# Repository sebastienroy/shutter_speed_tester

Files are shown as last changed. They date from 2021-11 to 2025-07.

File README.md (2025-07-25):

# Shutter Speed Tester for Film Cameras

The shutter speed tester is a project which goal is to design and build a tool that allows to test the shutter speed accuracy of a film camera

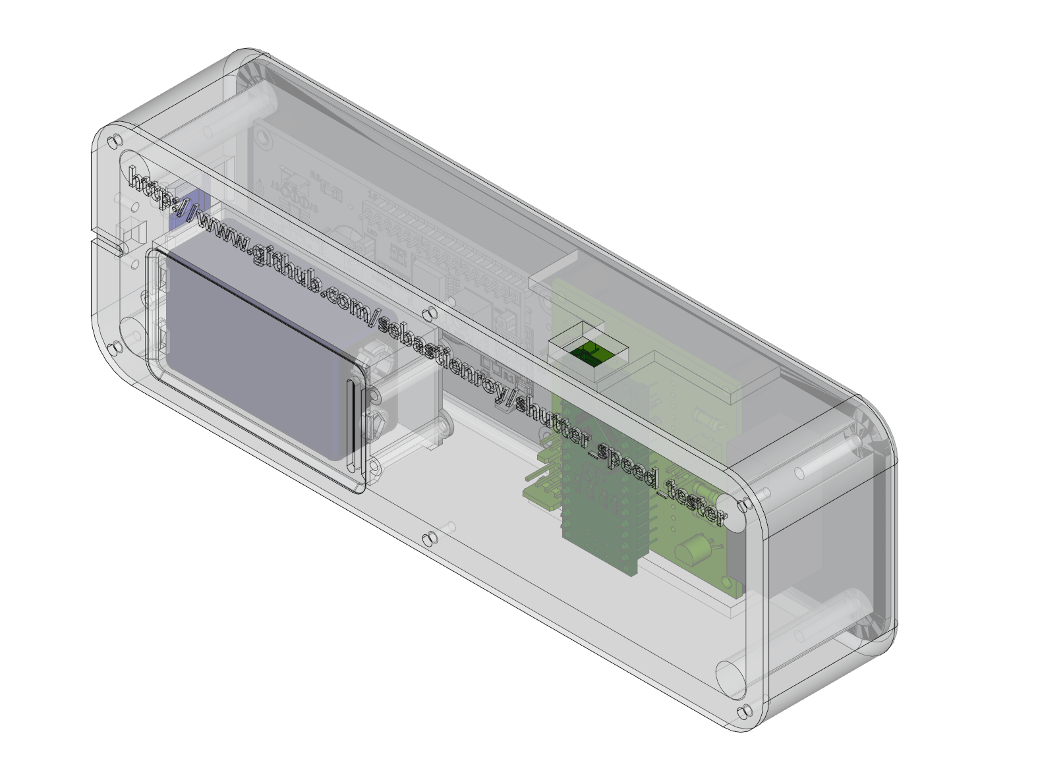
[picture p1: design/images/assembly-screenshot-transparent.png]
Shutter Speed Tester for Film Cameras in FreeCAD


When people passionated with old film cameras want to use their camera to shoot film, this sometimes results in an over or an under exposed film.  
This is usually due to the speed of the camera shutter that is not any more accurate. In order to check the shutter speed accuracy, the camera owner has to compare the actual opening time of the shutter with the expected one.  
This is the purpose of the shutter speed tester : measure the accuracy of shutter speed. 

Here is a presentation video (in French) :  

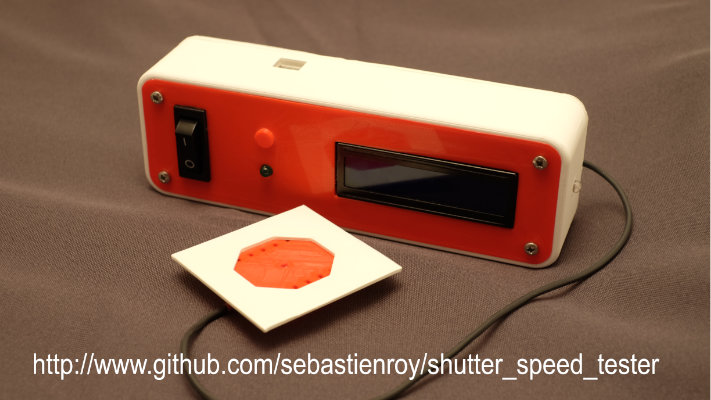
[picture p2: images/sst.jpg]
Presentation video in french (https://youtu.be/lsWC2Jt2cCw)


The result of this open source project is to allow anyone who has the minimum skills in DIY domain to build his own device

[Here is the description of the open source project.](project_description.md)

## Accuracy of the open source tester

The resulting tester has been tested against two methods described in [shutter meta tester project](https://github.com/sebastienroy/shutter_meta_tester) : time slot method and rotating wheel method.  
With the time slot method (an LED lit during a given time duration), the difference between expected and measured value is about a few tens of microseconds. This error is due mainly to the latency of the phototransistor. This error is small enough to not to be taken into account even at speed up to 1/2000s.  
With the rotating wheel method, we can observe an error a lot bigger. This error is not due to electronic factors, but results from geometric facts:  
The sensor of the tester is a bulb of 3mm diameter.  
At 1/1000s, given that the curtains translation speed is about 3m/s, the slit width of the curtain shutters is about 3mm large.  
When trying to measure a 3mm object with a 3mm sensor, the resulting error is about 100%.  
**So, because of geometric consideration, the use of such a tester should be reserved for speeds not exceeding 1/250.  
The conclusion is the same for all testers with a similar sensor that do not provide a calibration mechanism.**  

# Baby Shutter Tester mark II
Many people, interested to get such a device but who don't feel skilled enough to build their own copy, asked the author of the project to build it for them.  
This resulted to the commercial version of the tool, the Baby Shutter Tester (mark I).  
The Baby Shutter Tester was regularly improved, and its main additional feature was the ability to self calibrate.  **The self-calibration mechanism allowed a precision of a few microseconds, instead of 1 stop at high speeds.**  
However, the precision brought by the self-calibration procedure required to follow a very specific process, difficult to implement outside a workshop.  

So, a completely reworked version has been designed: the **Baby Shutter Tester Mark II.**  
The speed measurement method impleted by this new version is completely different: instead of starting a timer at a given light illumination threshold, the tester takes into account all the light variations that hits its sensor.  
This allows to take into account high speed ranges, where the shutter cannot be considered as a perfect shutter, i.e. the cases where the shutter cannot be aproximated to an on/off mechanism.  
This method is similar to the method used by the Kyoritsu legacy professional shutter tester.  
In addition, the Baby Shutter Tester Marks II meets all the recommendations of the ISO-516:2019 standard. Not only the testing method but also all the measurement precision requirement described by the standard.  

The benefits of this characteristics are the following:
- An extreme accuracy
- The accuracy is obtained without calibration procedure
- Using the optional light source with diffuser, the tester can also measure central (leaf) shutters without any bias.

More information on https://photographyelectronics.com  

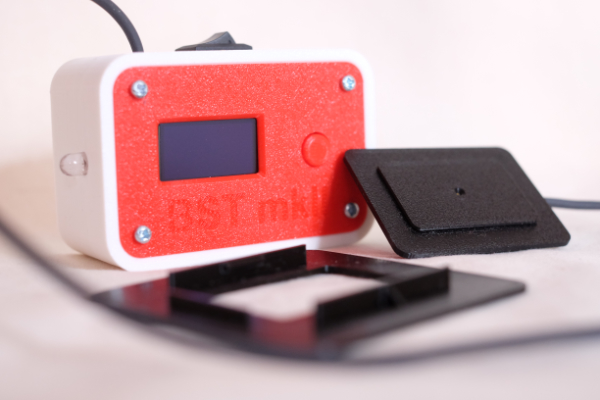
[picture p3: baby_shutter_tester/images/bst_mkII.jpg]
Baby Shutter Tester image


## Video presentation
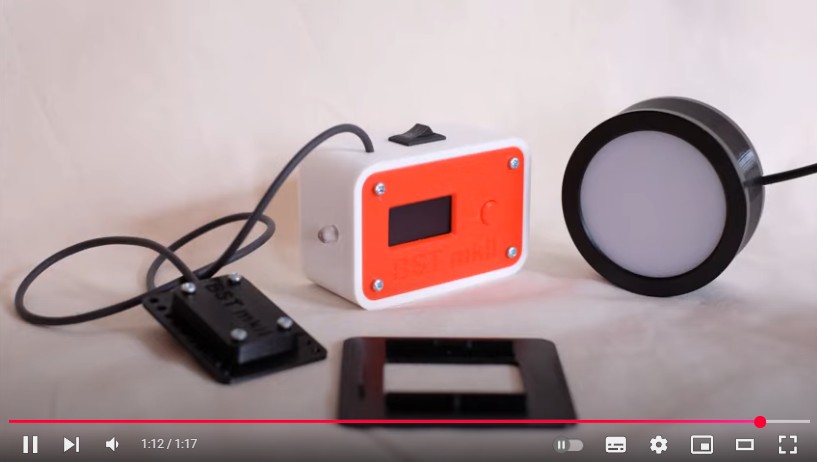
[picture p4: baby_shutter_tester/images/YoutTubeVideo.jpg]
Presentation YouTube (https://youtu.be/JVzSVh_tT6g)
  

## Accuracy test methods
The accuracy of the Baby Shutter Tester mark II is checked using 
- the graphical verification method described in the ISO-516:2019 standard
- [a dedicated benchmark](https://github.com/sebastienroy/shutter_meta_tester).
 
## Where to buy 
https://photographyelectronics.com/shop/  
[eBay link](https://www.ebay.fr/itm/205397044799)

## User manual

[User Manual](https://github.com/sebastienroy/shutter_speed_tester/wiki/Shutter-Testers-documentation)

# Curtain travel time measurement: The Shutter Lover

The Shutter Lover is a tool specialized in the measurement of the travel time of the curtains of focal plane shutters.  
The measurement of the curtain travel time is necessary for camera repairers, in order to be able to ajust the springs of each of the curtains.  
The goal is to obtain an homogeneous travel time of the two curtains, with values in accordance with the manufacturer recommendations.  

Shop: https://photographyelectronics.com/shop/  
This product is also available for [purchase on ebay](https://www.ebay.fr/itm/204344103169).  

Here is a short teaser :  
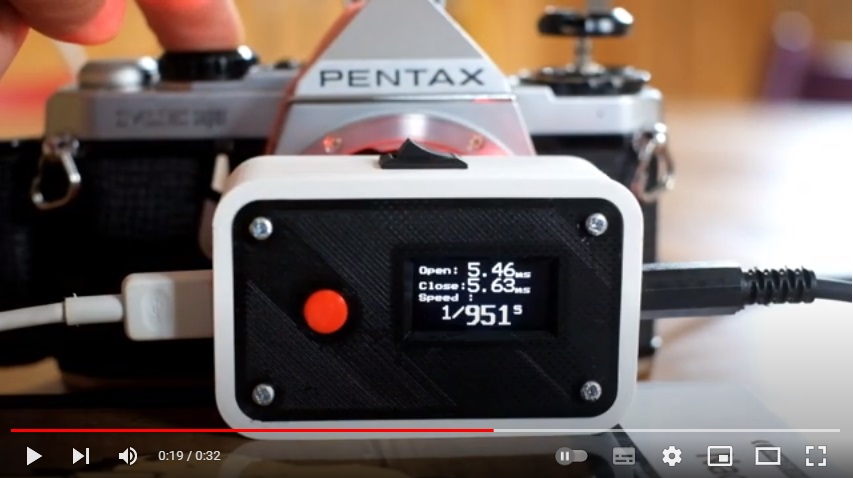
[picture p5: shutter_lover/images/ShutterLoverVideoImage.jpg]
Video of the Shutter Lover (https://youtu.be/AOC1KYjHUho)


## User Manual  

[User Manual](https://github.com/sebastienroy/shutter_speed_tester/wiki/Shutter-Testers-documentation)

## Test bench

In order to get the better precision and reproducibility with the shutter Lover, it is recommended to use a test bench, such as the one describe [here](testbench/testbench.md).

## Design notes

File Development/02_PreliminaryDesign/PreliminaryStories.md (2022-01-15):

# Preliminary design

## System and Architecture analysis

The system is very small and is not interfaced with other systems, except
- The user
- The camera

Thus we will not write a complete system analysis of this. We will jump directly to the physical architecture design of our tool :

Physical Architecture

## Components choice

|Component role | Component choice | Comment |
|---|---|---|
| Main unit | Compound | The main unit is composed of several other components.</br> A specific casing has to be be designed for it |
| Control unit (hardware) | Arduino Nano | An arduino nano microcontroler would fullfill all the needs : </br>- low price</br>- low dimensions</br>- low electric cosumption</br> - capacity to interact with simple electronic components |
| **Control unit (software)**| **Specific code** | This will be one of the subjects of this project. It has to make the link between the differents componetns of the tool |
| **Mother board** | **Specific design** | A specific PCB has to be designed to integrate all the different components of the tool. Once designed, it can be manufactured by any PCB manufacturer |
| Electrical power | Battery | The detailed design of the battery part has to be defined later. </br>The use of battery allow a more practical usage of the tool. </br>The low consumption of the arduino allow to use it without a to high battery consuption.</br>However, the USB port of the Arduino may be used as a opportunity to power the system without using a battery |
| Power switch | Flip flop switch | A "hard" power switch will be preferred rather than a "standby" push button, in order to not use the battery at all when not in use |
| Reset button | Push button | The Reset button will be able to erase the previous result and start a new measure |
| Control led| Led | the control led will help the operator to see that the light sensor is currently detecting light (when the shutter is open, if the light source and the light sensor are correctly positionned). This could be achieved also using a specific display on the general display device. However, due to the low response speed of the chosen display (see below), a LED is prefered|
|Display| 16x02 LCD| A 16x02 LCD is very common, low price and easy to control with an Arduino|
|Light source| Led| The light source has to be chosen in accordance with the light sensor sensitivity (intensity and even maybe wavelength).</br>It has to be mounted preferably on a physical support that allows to adjust the position according the tested camera.</br>There is two options for the light source : </br>  1. Use an independent light source, maybe even don't include it in the package and let the user choose it by himself</br>  2. Use a light source powered by the tool</br>The option 2 is prefered because it allow to have a real control on the quality of the light source. Indeed much of commercial led lamps are quickly blinking (PWM source) when used in eco mode and cannot be used for our purpose.</br>The challenge is to have a light source that <br/>  - is bright enough to allow the light sensor to detect the opening of the shutter</br>  - does not use too much electrical power and does not drain the battery too fast|
| Light Sensor | Phototransistor | A phototransistor is a good compromise between a low price, a good sensitivity and a low reaction time.</br> A specific support has to be designed, maybe according different film formats, in order allow a good position on the camera back, in order to easily detect the source light and not be influenced by environment light</br>Alternatives would have been :</br>- Photoresistor, too slow</br>- Photodiode, even faster than phototransistor but not enough sensitive |
| **Casing** | **Specific design** | A specific casing has to be designed in order to host all the components. There is many differnet ways to design a case. </br>- One of them is to model it with a 3D design tool and then to print it using a 3D printer</br>- Another solution is to make it using wood, using the same dimensional specifications as those defined for the 3D printed one</br>- It is also possible to mix the solutions |

## Design & development tools

The design & development tools are the following
| Tool name | Version  | Purpose | link |
| --- | -- | --- | --- |
| Fritzing | 0.9.3 | Electronic component & circuit design | https://fritzing.org/ |
| KiCad | 5.1.12 | Electronic component & circuit design| https://www.kicad.org/ |
| FreeCad | 0.19.2 | 3D modeling | https://www.freecadweb.org/ |
| Arduino IDE | 1.8.16 |Arduino cross development IDE | https://www.arduino.cc/en/software |
| VSCode | 1.62.0 | General purpose code editor | https://code.visualstudio.com/ |
| Drawio integration | 1.6.201 | Integration of Drawio tool into VSCode IDE |

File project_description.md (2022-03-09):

# Shutter Speed Tester Project Description

## Principle

Shutter speed tester principle schema

## Project scope

The project scope is to describe how to design and build a shutter speed tester tool.
The outputs of the project are :
- design documents, including the design process itself
- build description

## The project, step by step

Note that the following steps are not strictly waterfall. The result of a given step may introduce rework on previous steps

### [Operational concept definition](Development/01_OperationalConcepts/OperationalStories.md)
- Who is the target audience ?
- What need will be statisfied by the project product ? (Conops)
- How the product will satisfied by the need ? (Conuse)
- What are the product expected advantages compared to existing products ?

### [Preliminary design](Development/02_PreliminaryDesign/PreliminaryStories.md)
- Main behavioural description
- Definition of product architecture
- Choice of components / providers
- Choice of development/production tools

### [Development of Electronic circuit / microcontroler code / PCB design](Development/03_Development/DevelopmentStories.md)
- Definition of the target circuit with elements needed to implement the expected behaviour
- Development of the code necessary to control the electronic circuit and to implement the expected behaviour
- Design of the target PCB
- Production of PCB
- Assembly of components : soldering, connectors assembly, tests

### [Design of the casing](Development/04_Casing/CasingStories.md)
- Design of the facade : holes for display, button, LED, switch, position and size of screw plots
- Design of the body : positionning of the light source, sensor wire
- Design of the back : battery case and door
- Design of the sensor case : take into account different films and camera formats

### [Documentation](Development/05_Documentation/DocumentationStories.md)
- User Manual
- Build Manual
- BOM (Bill of Material)

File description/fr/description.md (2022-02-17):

# Description du projet Shutter Speed Tester (Testeur de vitesse d'obturateur)

## Introduction

Le projet consiste à réaliser un outil permettant de mesurer la vitesse d'obturation des appareils photographiques argentiques.  
Ces appareils photo, surtout lorsqu'il sont anciens, ont un obturateur qui est une pièce d'horlogerie susceptible de se dérègler. Le temps d'ouverture de l'obturateur peut alors avoir un écart important par rapport à la valeur attendue, conduisant à une sous-exposition ou une sur-exposition de la pellicule.  
La connaissance de cet écart permet au propriétaire de l'appareil photo, 
- soit de re-calibrer l'obturateur s'il en a les compétences, 
- soit de compenser l'écart constaté au moyen du règlage du diaphragme et/ou du sélecteur de vitesse.

## Niveaux de compétences requis pour ce projet

| Domaine | Niveau | Détail |
|--|--|--|
| Connaissance métier | Niveau intermédiaire| Comme dans tout projet, une bonne connaissance des besoins de l'utilisateur final est la clé de la réussite. Lorsque le client et le fournisseur ne font qu'un, forcément ça aide. Les concepts opérationnels servis par le projet sont toutefois plutôt simples à apréhender|
| Electronique | Peu complexe à moyennement complexe | - Définition des circuits : Niveau lycée. La loi d'Ohm et le principe de fonctionnement d'une LED et d'un transistor sont suffisants pour les circuits de ce projet</br>- Réalisation d'un circuit imprimé : L'expérience montre que la définition d'un circuit imprimé tel que celui de ce projet n'est au final  pas très compliquée. Sa fabrication est sous-traitée à un industriel spécialisé</br>- Assemblage des composants : L'assemblage des composants sur le circuit imprimé nécessite de réaliser quelques soudures et de sertir quelques connecteurs. Ce sont des savoir-faire qui s'apprennent très facilement après visualisation de quelques vidéos YouTube. |
| Programmation Arduino| Peu complexe à moyen | Niveau bac. Les circuits électroniques sont pilotés par le microcontroleur d'une carte Arduino. La programmation d'une telle carte est de niveau lycée. La gestion des interruptions et d'états est à peine plus complexe mais ne devrait pas présenter de difficulté particulière pour un ingénieur travaillant dans des systèmes à logiciel prépondérant |
| Modélisation 3D | Peu complexe | Définition du modèle 3D du boitier. De nombreux éléments sont à prendre en compte (taille et position des composants, trapes d'accès, etc), mais individuellement, aucun de ces éléments ne représente une difficulté majeure|
| Suite dans les idées| Niveau ingénieur d'un grand groupe industriel | Chacune des étapes du projet est individuellement très simple, et nécessite des connaissances facilement accessibles en ligne. Il a toutefois été nécessaire d'en enchainer un nombre important pour arriver au résultat attendu. L'identification et la description de ces étapes est au final l'enjeu principal d'un projet de ce type. Ce sont des activités qui sont le quotidien du Product Owner dans une organisation Scrum| 

## Outils et techniques appris ou mis en oeuvre au cours du projet
|Outil/technique|Description|
|---|---|
| Arduino IDE | Le web regorge de ressources, tutoriels, documentation, vidéos décrivant chaque aspect de la programmation Arduino. Il suffit de se pencher pour ramasser |
| Fritzing| Fritzing est un outil permettant de décrire très facilement des schémas électroniques, et notamment sous forme de plaque d'essais. Impeccable pour générer des illustrations|
| KiCAD | KiCAD est un outil Open Source de design de circuits imprimés. Il permet de décrire très précisément, avec une qualité "professionnelle", les différentes couches qui composent un circuit imprimé. Son format de fichier est directement accepté par les fabricants de circuits. KiCAD est très riche, mais seul une partie de cette richesse a été exploitée pour ce projet |
| Fer à souder | L'utilisation d'un fer à souder pour souder des composants n'est pas très compliquée mais nécessite un peu d'expérience avant d'arriver à un résultat satisfaisant. De nombreux tutoriaux et descriptifs sont disponibles en ligne |
| Pince à sertir| Pour relier les composants "externes" au circuit imprimé, on utilise des fils électriques connectés par le moyen de connecteurs. Ils nécessitent d'être sertis. On utilise pour ce faire une pince à sertir, qui demande un peu d'aprentissage pour limiter le taux de déchets|
| FreeCAD | FreeCAD est un des nombreux outils disponibles pour la modélisation 3D. Il a l'avantage d'avoir un fonctionnement paramétrique, permettant une définition ultra précise des dimensions des pièces concues. Par ailleurs de très nombreux tutoriaux et exemples sont diponibles en ligne. Une fois assimilés les principes généraux de l'outil, son utilisation est plutôt simple |
| Impression 3D| L'impression 3D proprement dite est très simple. Elle met en oeuvre un outil qui va importer le modèle 3D et le découper en tranches, les différentes couches d'impression.  |

## Les étapes du projet, pas à pas
Voici les grandes lignes du développement du projet. Les détails de chacune des parties est disponible (en anglais) sur le site de partage du projet  
> www.github.com/sebastienroy/shutter_speed_tester

### Définition du concept opérationnel
- Qui est la cible du produit ? 
- Quels besoins seront satisfaits par le produit ? (Conops)
- Comment le produit va satisfaire le besoin de l'utilisateur? (Conuse)
- Quels sont les avantages comparatifs du produit par rapport à ce qui existe déjà? 

### Design préliminaire
- Description des comportements principaux
- Définition de l'architecture du produit
- Choix des composants
- Choix des outils de développement

### Développement électronique et logiciel
- Définition du circuit comprenant les éléments requis pour implémenter le comportement attendu
- Développement du code de control des circuits électroniques et implémentant le comportement attendu
- Développement du circuit imprimé
- Production du circuit imprimé
- Assemblage des composants : soudure, sertissage des connecteurs, tests

## Design du boitier

- Design de la façade : ouvertures pour l'affichage, le bouton, la LED de control, l'interrupteur. Positionnement des plots de support à vis.
- Design du corps du boitier : positionnement de la source de lumière, du fil du capteur
- Design du dos : emplacement de la pile et de sa trappe d'accès
- Design du support de capteur : prise en compte des différents formats de film photographique.

### Documentation
- Manuel utilisateur
- Manuel de fabrication
- Liste des composants

## Les conseils de Sébastien
Ce type de projet est l'occasion idéale pour un ingénieur de couvrir l'ensemble des phases de réalisation d'un projet, des concepts opérationnels jusqu'à la mise en production. Ceci n'arrive pas souvent dans la vie professionnelle, vu les cycles parfois très longs et la taille des équipes sur lesquels nous sommes impliqués.  
Il pourrait être tentant, vu la taille typique d'un projet personnel et l'absence de contrainte externe, de ne pas formaliser les phases amont, ni même la description des phases de développement successives.  
Ce serait une erreur, car cette formalisation permet de se donner un fil conducteur. C'est une source de satisfaction à chaque étape réalisée. Comme le temps disponible pour le projet est très fragmenté, formaliser chaque étape permet de reprendre les travaux très rapidement après une interruption.

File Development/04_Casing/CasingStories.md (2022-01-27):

# Summary

- [Summary](#summary)
- [Casing Stories](#casing-stories)
  - [1. Design of the case, front side](#1-design-of-the-case-front-side)
    - [Description](#description)
    - [Realisation](#realisation)
    - [Screw holes](#screw-holes)
    - [Result](#result)
  - [2. Light source housing](#2-light-source-housing)
    - [Description](#description-1)
    - [Realisation](#realisation-1)
  - [3. Battery door](#3-battery-door)
    - [Description](#description-2)
    - [Realisation](#realisation-2)
    - [Conclusion](#conclusion)
  - [4. Prevent the sensor wire to rip](#4-prevent-the-sensor-wire-to-rip)
    - [Description](#description-3)
    - [Realisation](#realisation-3)
  - [5. LightSensorSupport](#5-lightsensorsupport)
    - [Description](#description-4)
    - [Result](#result-1)
  - [6. Medium format Adapter](#6-medium-format-adapter)
    - [Description](#description-5)
    - [Result](#result-2)

# Casing Stories

## 1. Design of the case, front side

### Description
Because designing the case may be a very complex activity, we will split in 3 steps :
* The design of the front panel
* The design of the case sides
* The design of the rear panel

Of course, the integration of these 3 parts has to be addressed

### Realisation
We use an open source model for LCD1602 : https://grabcad.com/library/1602-lcd-display-1

The Front panel need to put in place the main board, the LCD board, and te power switch. the thickness will be set to 1.5mm.

### Screw holes
One of the tricky thing is to choose the good screw hole diameter. It must be bigger than the core part of the screw, and smaller than the exernal diameter of the screw.
I have ordered iron plate screws, because they are most common than screxs for plastic.
However, screws for platics could have been ordered here :
https://www.visseriefixations.fr/eco-syn-pour-thermoplastiques-tcb-pozi-2-2x5-z-blanc.html  
We will order more specific screws when we'll have used all the screws we have ordered, described in the part list.
- Small screws : M2.2 x 6.5 mm
  - Core diameter : 1.9 mm
  - External diameter : 2.2 mm
- bigger screws : M2.9 x 13 mm
  - Core diameter : 2.2 mm
  - External diameter : 2.8 mm

Conclusion : we will use
  - 2 mm diameter for small screw holes (screws for pcb)
  - 2.5 mm diameter for bigger screw holes (screws for panels)

### Result 

Here is the front view :  
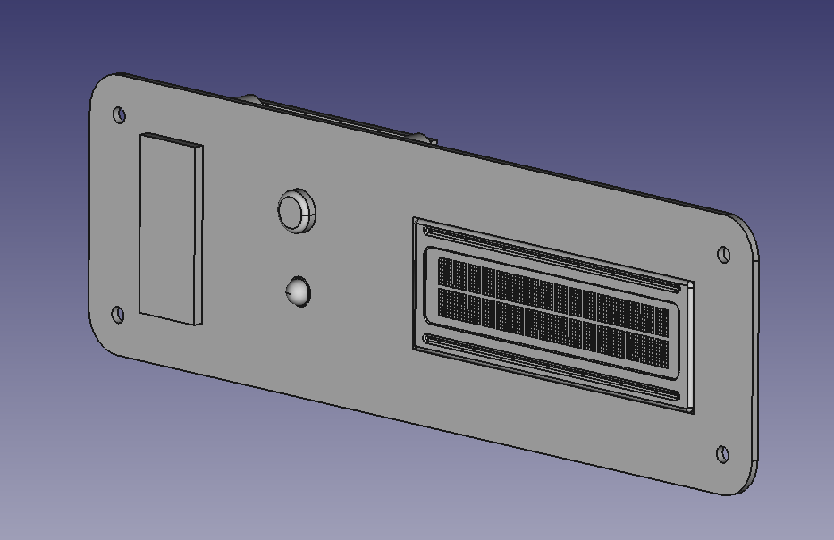
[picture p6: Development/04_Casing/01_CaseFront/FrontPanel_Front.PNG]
Casing front panel, Front view
  

And here is the back :  
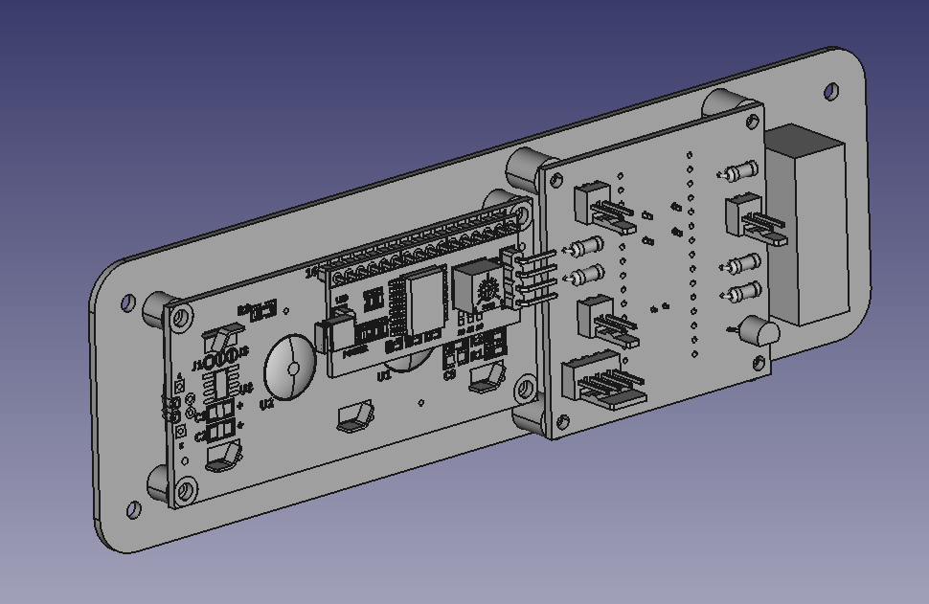
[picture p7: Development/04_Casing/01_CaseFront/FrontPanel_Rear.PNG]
Casing front panel, Rear view


## 2. Light source housing

### Description

The case must take into account the size of the different elements, but also the need to hold the light source.
Decision is taken to hold the light source in the side of the case. This will make more simple the general handling of the tool. It than just has to be placed in front of the camera, and the light sensor in the back.
The goal is now to make a design in order to hold the light source LED in the wall of the case.  
The dimensional specifications of the light source LED are the following :  
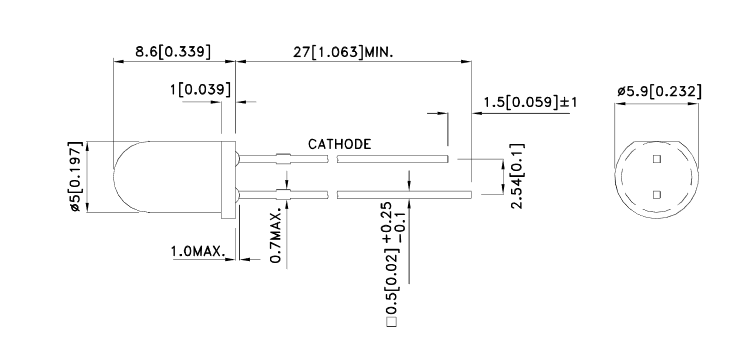
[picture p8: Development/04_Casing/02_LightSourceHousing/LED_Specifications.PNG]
LED specifications


### Realisation

We will test that :

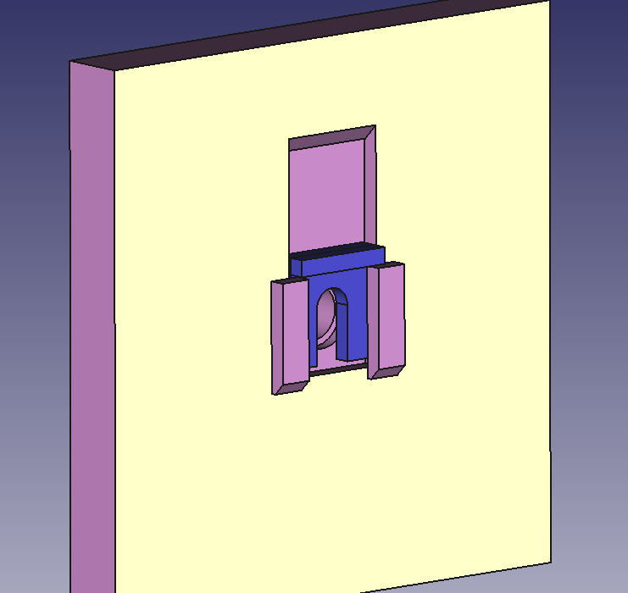
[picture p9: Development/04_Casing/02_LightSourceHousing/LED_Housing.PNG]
LED housing test


A first test shows that the concept is not bad. However, it needs a lot of sanding in order to be able to insert the LED into the hole. So, the tolerences have to be increased to make easier the insertion of the LED. Furthermore, chamfers have been added to the hold piece.

## 3. Battery door

### Description

The idea is to create a door that can be opened by hand but that cannot open by itself.  
In one word, we wan to design a battery door.
The prefered design would need no screw.  

### Realisation

We use a well known design, that use a door with a slot at one side, that allows to unlock it by bending the side.  

Here is the inside view :
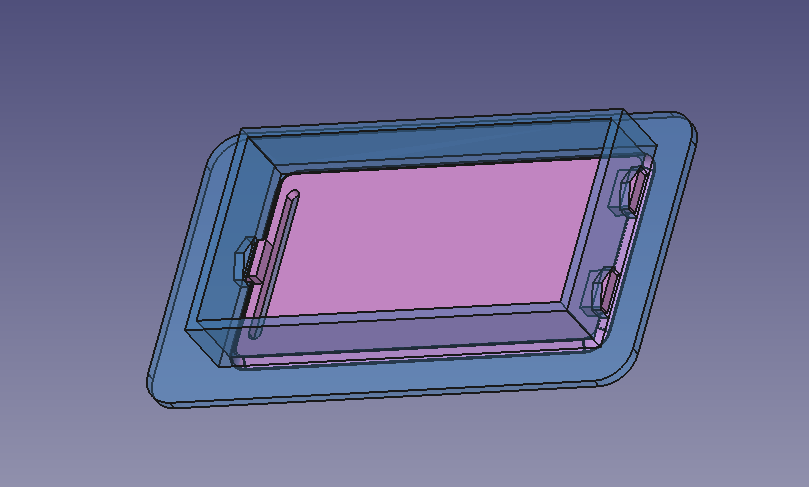
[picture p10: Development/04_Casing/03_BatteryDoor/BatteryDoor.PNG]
Battery door


There is chamfers in the opposite direction on the door panel and on the outside panel, so they fit perfectly together. 
Howver, du to the 3D printing flaws, some tolerances have to be applied :  
The door panel has to be smaller of :
- the panel opening is 60x30 mm
- the door is 62 x 32
- The thickness of both panels is 1.5 mm
- the chamfers of both panels is 1.3 mm

The theretical overlap of each side is :  
thickness - 2 (thickness - chamfer)  = 2 chamfer - thickness. 
In our case it is : 2x1.3 - 1.5 = 1.1 mm
So, a perfectly build construction would have fit with a door having 62.2 mm x 32.2 mm.  
We use a little bit smaller dimensions to take into account the 3D printing flaws.

### Conclusion
In order to fit perfectly, with a panel thickness of 1.5mm and a 1.3mm chamfer on both panel and door, the **door** must be **2mm longuer** and **2 mm larger** than the panel opening.

## 4. Prevent the sensor wire to rip

### Description
The light sensor will be placed at the back of the camera in a separate casing, and linked to the main body using a wire. The wire will be connected to the main board using a dedicated connector.  
The point to adress in this story is the way the wire passes through the casing. The problem to solve is to prevent to accidentaly rip the connecter by pulling on the wire. There is two ways to address this :  
- Using another connector to pass through the case panel
- blocking the wire, using for instance chicanes, inside the casing

### Realisation

- [ ] **TODO**

## 5. LightSensorSupport

### Description  
The vision of the design of the LightSensor support is to have a core support, designed for the 35mm film format.  
To this, may be added adaptors to 120 film format : 645, 6x6, 6x9

Specifications of 35mm film can be read there :  
[Kodak film specification](https://www.kodak.com/content/products-brochures/Film/How-to-read-a-Kodak-film-can-label.pdf)
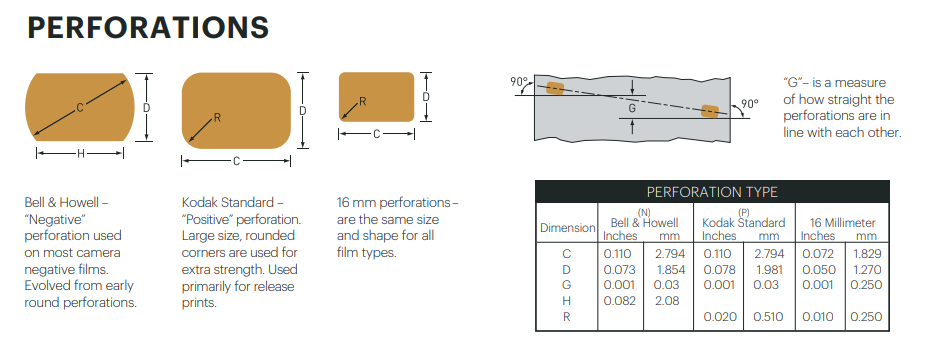
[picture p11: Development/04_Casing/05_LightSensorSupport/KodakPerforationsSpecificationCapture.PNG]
KS perforation specification


The 35mm film is 35mm large, 
Perforations pitch is 4.75mm.
Each perforation is about 2.8mm x 2.0mm large (KS perforation), at about 2 mm from the side of the film.  
Their corners are rounded, with 0.5mm radius.

Here are the physical specifications of the phototransistor :
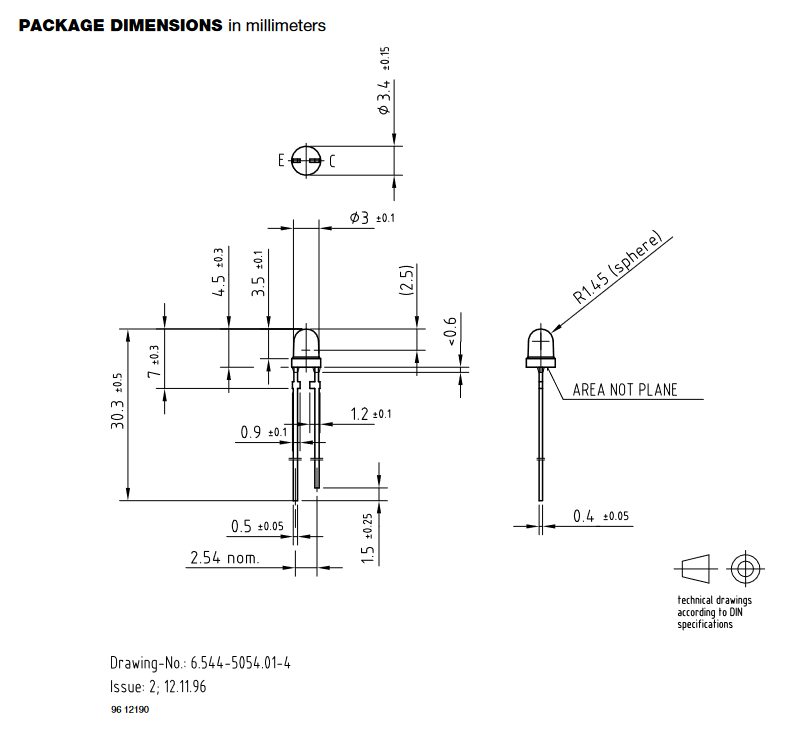
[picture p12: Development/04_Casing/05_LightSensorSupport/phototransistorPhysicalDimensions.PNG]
Phototransistor physical dimensions


A hole must be provided in the middle of the support to hold this phototransistor.

### Result
Here is the result :  
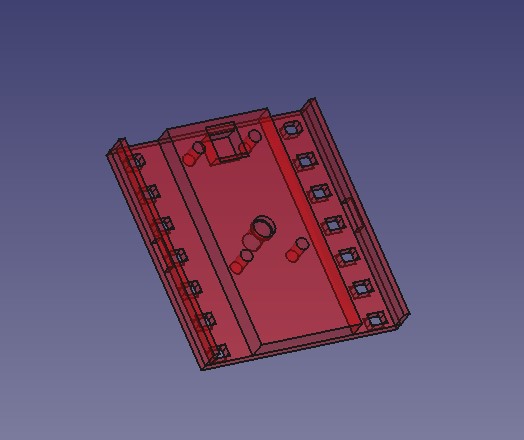
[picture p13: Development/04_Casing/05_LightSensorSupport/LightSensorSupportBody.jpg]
Light Sensor Support
  
Holes have been provisioned at the sides of the support to allow to fit an adapter for medium format film cameras.

And, with the lessons learned from step 4, we also add a cover that prevent the wire to move.

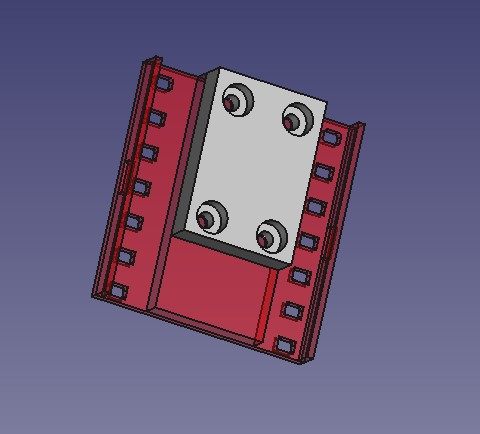
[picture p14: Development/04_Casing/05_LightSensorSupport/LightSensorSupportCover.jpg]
Light Sensor Cover


## 6. Medium format Adapter

### Description
We need an adapter in order to be able to use the sensor also with medium format cameras.  
Medium format films are rolls of approximatively 6 cm large. This format is named "120 format".  
The cameras that use 120 film may have different exposed sizes : 6x4.5, 6x6, 6x7, 6x9, ...
We will design a 6x6 adapter. Other format will be easily adapted from that.

### Result
And here is the result :
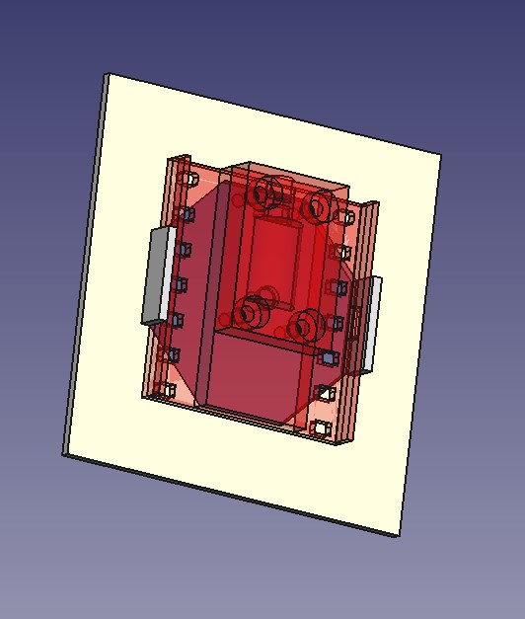
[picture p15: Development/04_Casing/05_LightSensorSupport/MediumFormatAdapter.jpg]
Medium Fomat Adapter
  
This is a very simple but efficient design.  
The adapter can be easily fit on or off by bending it.

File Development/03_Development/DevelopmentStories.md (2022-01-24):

# Summary

- [Summary](#summary)
- [Development Stories](#development-stories)
  - [1. Experimention : How to detect the opening of a camera shutter](#1-experimention--how-to-detect-the-opening-of-a-camera-shutter)
    - [Description](#description)
    - [Acceptance criteria](#acceptance-criteria)
    - [Realisation](#realisation)
    - [Results](#results)
  - [2. Detection of the time interval between rising and falling edges of the shutter](#2-detection-of-the-time-interval-between-rising-and-falling-edges-of-the-shutter)
    - [Description](#description-1)
    - [Test means](#test-means)
    - [acceptance criteria](#acceptance-criteria-1)
    - [Bibliography](#bibliography)
    - [Realisation](#realisation-1)
    - [Code](#code)
  - [3. Implementation of behaviour states](#3-implementation-of-behaviour-states)
    - [Description](#description-2)
    - [Realisation schema :](#realisation-schema-)
    - [Code](#code-1)
  - [4. Add control LED](#4-add-control-led)
    - [Description](#description-3)
    - [Realisation schema](#realisation-schema)
    - [Code](#code-2)
  - [5. Display on LCD screen](#5-display-on-lcd-screen)
    - [Description](#description-4)
    - [Code](#code-3)
  - [6. Bonus : create a sleeping mode](#6-bonus--create-a-sleeping-mode)
    - [Description](#description-5)
  - [7. Create the Printed Circuit Board (PCB)](#7-create-the-printed-circuit-board-pcb)
    - [Description](#description-6)
    - [Realisation](#realisation-2)
  - [8. Automatically update LCD IIC address](#8-automatically-update-lcd-iic-address)
    - [Description](#description-7)
    - [Realisation](#realisation-3)
  - [9. Setup mode](#9-setup-mode)
    - [Description](#description-8)
    - [Realisation](#realisation-4) 

# Development Stories

## 1. Experimention : How to detect the opening of a camera shutter

### Description

The aim of this story is to choose the right components and the right electronic schema in order to be able to detect the opening of a camera shutter, i.e how to detect a light source using a light sensor

### Acceptance criteria

The choice of the components and schema allow to detect a light source using a light sensor

### Realisation

With the following schema, it would be possible to check different values of resistor, and measure
* The voltage value induced by the phototransistor current, depending on the light that illuminated it
* Which light intensity, for different resistor value, allow to swich the digital port of the Arduino

As a ligth source, we will use a standard led component, directly wired on the 5V output of the Arduino.  A 220 Ohm resistor is used to get an intensity less than 20 mA.  
20 mA is the maximum current value recommended both for Arduino output (even not used in this experimentation) and for a standard LED.  
$$
I = U/R = \frac{(5.0 - 1.2)}{220} \approxeq 17 mA
$$  

I = U/R = (5.0V - 1.2V) / (220 Ohm) ~= 17 mA  
(The direct voltage of the Led is 1.2V)  

And here is the schema :
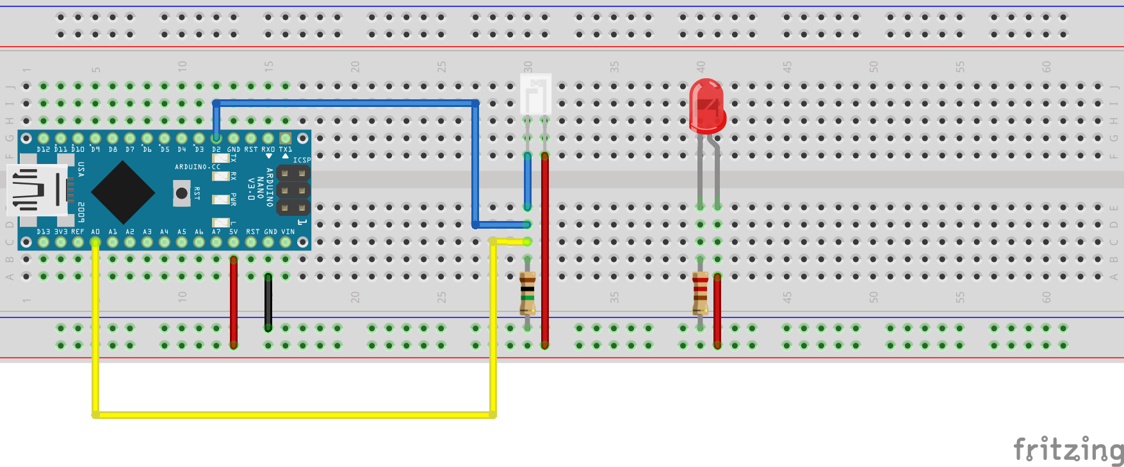
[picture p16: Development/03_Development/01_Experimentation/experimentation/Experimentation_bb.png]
Experimentation schema


Be carefull to plug the anode pin (the longer leg) of the phototransistor and the LED to the + side of the circuit

The following code will allow to get written on the serial of the Arduino, every second, the current analog and digital values read on the phototransistor :

[Experimentation code](01_Experimentation/experimentation/experimentation.ino)

### Results

The higher is the resistor value between the phototransistor, the more sensitive is the result.
- With a 1k Ohm resistor, the measured voltage change a little when putting the phototransistor in front of the led  
- The sensibility increases with increasing value of resistor
- When using 1M Ohm resistor, it is possible to change the input state at a ~ 5 cm distance
- When using 4x1M Ohm resistors (serial circuit), it is even possible to change the state at 10 cm

Questions :
- What is the limit of increasing sensibility ?
- Is there a side effect of increasing the resistor, as for instance a slower reactivity ?
- Is it better to use a more powerfull LED or higher resistor value ?

## 2. Detection of the time interval between rising and falling edges of the shutter

### Description 

The goal of this step is to do the minimum of design and development to be able to compute the time interval between rising and falling edges of the shutter.  
This step can be considered as a kind of derisking.

### Test means

The source of light may be provided by an external device 
The result output may be written (and read) on the serial port of the Arduino

### acceptance criteria
The system detects the rising and falling edges of the shutter
The system computes the time differences between rising and falling edges

### Bibliography

A similar problem has been adressed in this page :
https://lederniermatou.net/arduino-et-phototransistor.html

### Realisation

The following circuit has been realized, based on the experimentation :  

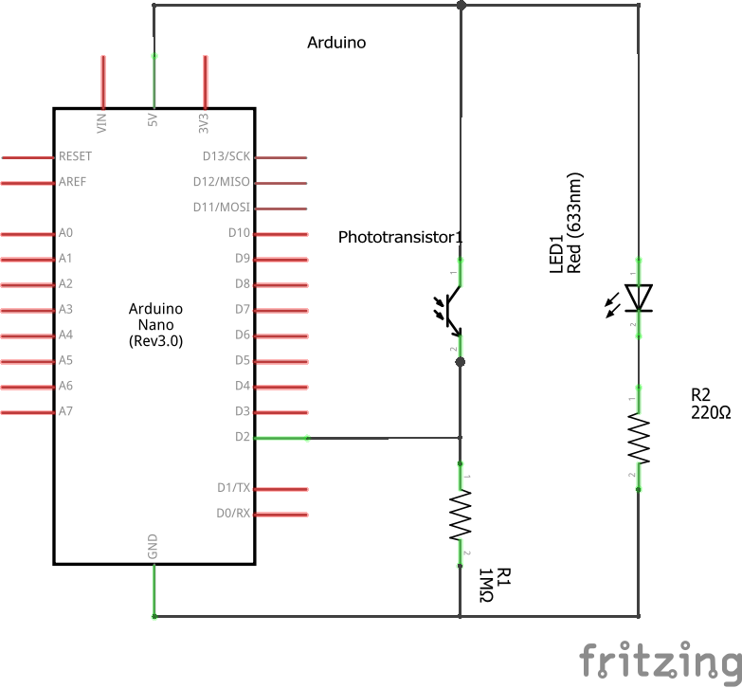
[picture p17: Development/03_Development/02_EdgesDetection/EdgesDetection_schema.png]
Schema
  

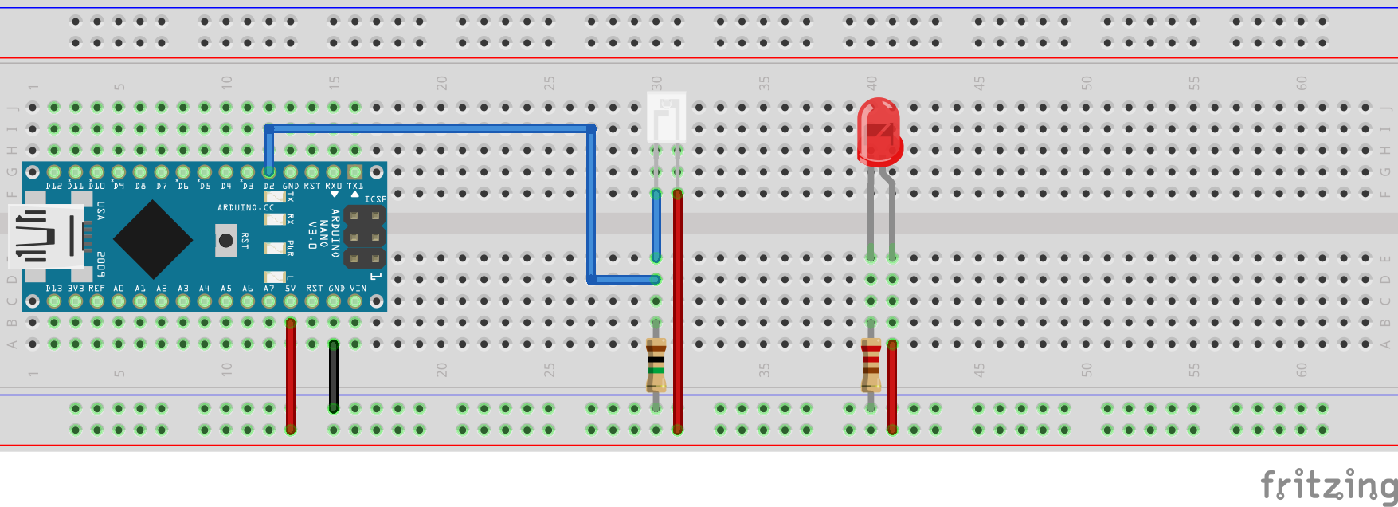
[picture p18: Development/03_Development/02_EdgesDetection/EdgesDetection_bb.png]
Bread board


Note that, in order to use the interrupt capacity of the Arduino, only the D2 or D3 pins may be used for the phototransistor state change. The interrupt capacity is not available on the other pins.  

### Code

[Edges detection code](02_EdgesDetection/EdgesDetection/EdgesDetection.ino)

## 3. Implementation of behaviour states

### Description

The goal of this step is to implement the complete state diagram of the expected behaviour of the tool.  
The idea is to light on the source LED only when the user is ready to start the measure, and to switch it off as soon as the measure is performed.  
A button allows to start a new measure.

State diagram :

Behaviour state diagram

### Realisation schema :
The implementation of the state diagram needs :
- a way to switch on and off the illumination LED. The choice is to achieve this using a command transistor. The justification of this is that it allows to use a LED that uses more than 20 mA, without deteriorating the Arduino pin.
- a push button in order to be able to start the measure again.  

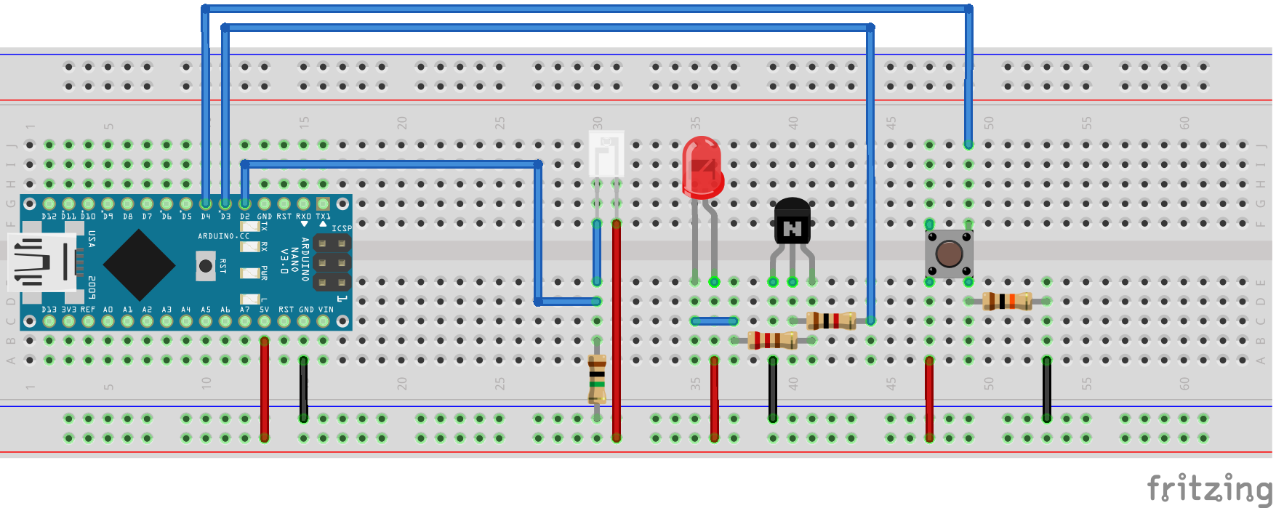
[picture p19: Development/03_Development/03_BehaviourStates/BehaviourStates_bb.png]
State diagram breadboard
  

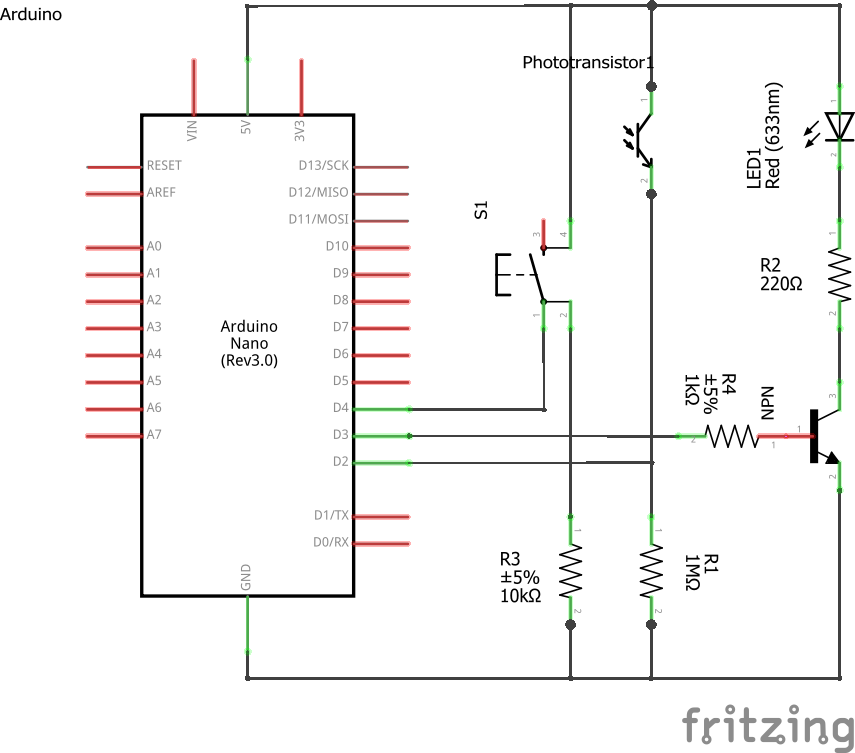
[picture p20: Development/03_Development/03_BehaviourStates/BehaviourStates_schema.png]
State diagram schema


### Code  

[State diagram Code](03_BehaviourStates/BehaviourStates/BehaviourStates.ino)

## 4. Add control LED

### Description  

After the previous step, which was very complex, this one will be very easy.  
The goal is to add a control LED, that is lit when the phototransistor detects light. This helps the user to see that the illumination LED and the light sensor are correctly positionned.  
The control LED has to be switched on only during the "Shutter open" state.

### Realisation schema

Here is the realisation schema for this new element :  

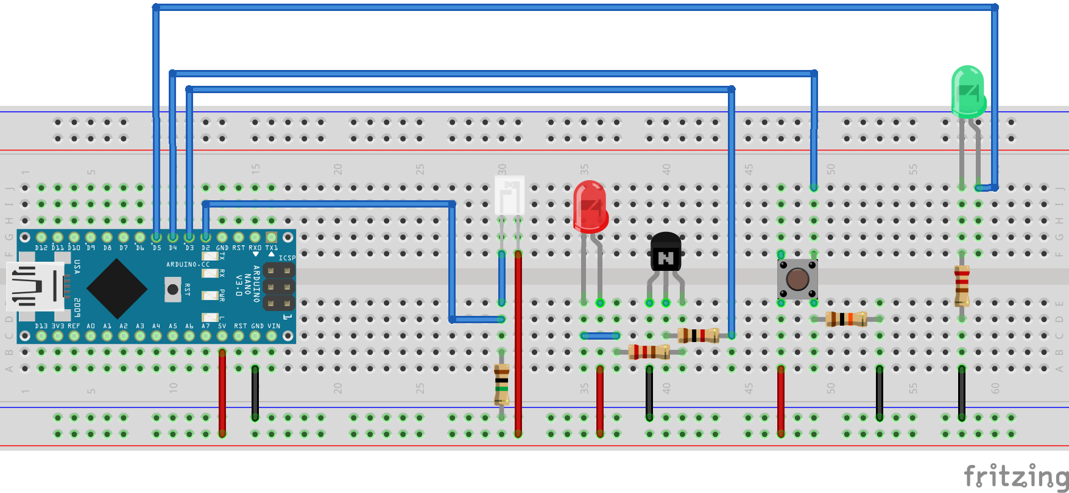
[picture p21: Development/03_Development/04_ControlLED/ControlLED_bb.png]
Control LED breadboard
  

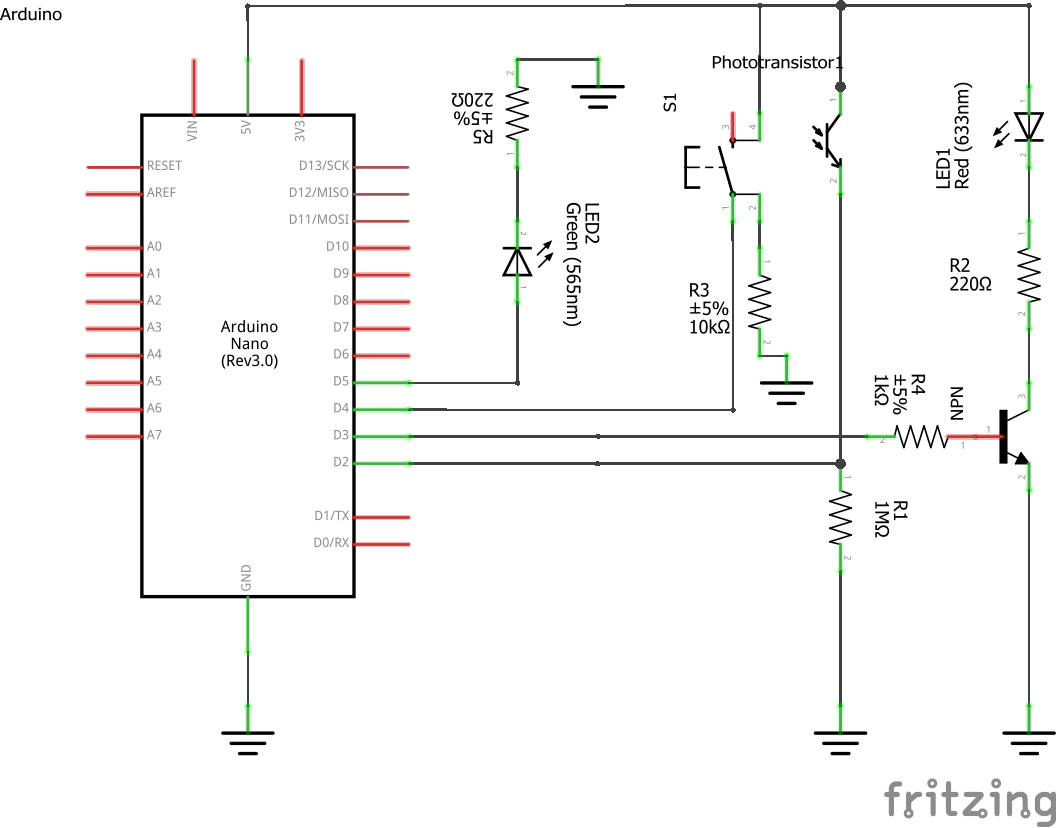
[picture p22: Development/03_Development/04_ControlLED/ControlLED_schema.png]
Control LED schema


### Code  

In order to prevent the control LED to be too bright, we use the PWM capability of the Arduino

[Control LED](04_ControlLED/ControlLED/ControlLED.ino)

## 5. Display on LCD screen

### Description  

All the previous experimentation and coding used the serial port of the Arduino to write the results.  
However, the target is to diplay the messages and the measure result on a dedicated display.  
The most common and cheap display are 16x2 LCD display. They can be addressed directly, or through an I2C interface.  
We will use this second option for the following reasons :  
- less wires from the Arduino to the LCD
- The IC2 interface integrates a potentiometer that adjusts the LCD screen contrast. So it hasn't to be added in the rest of the schema  

The SDA and SCL pins of the I2C interface have to be wired respectivlely on A4 and A5 pins of the Arduino.

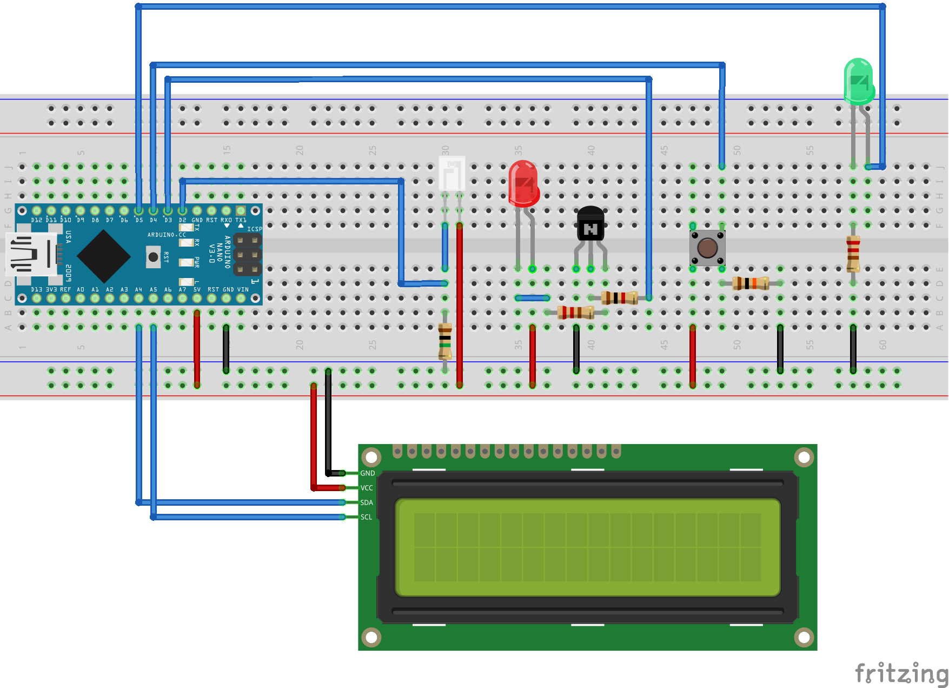
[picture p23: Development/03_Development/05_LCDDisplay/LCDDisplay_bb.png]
LCD Display breadboard
  

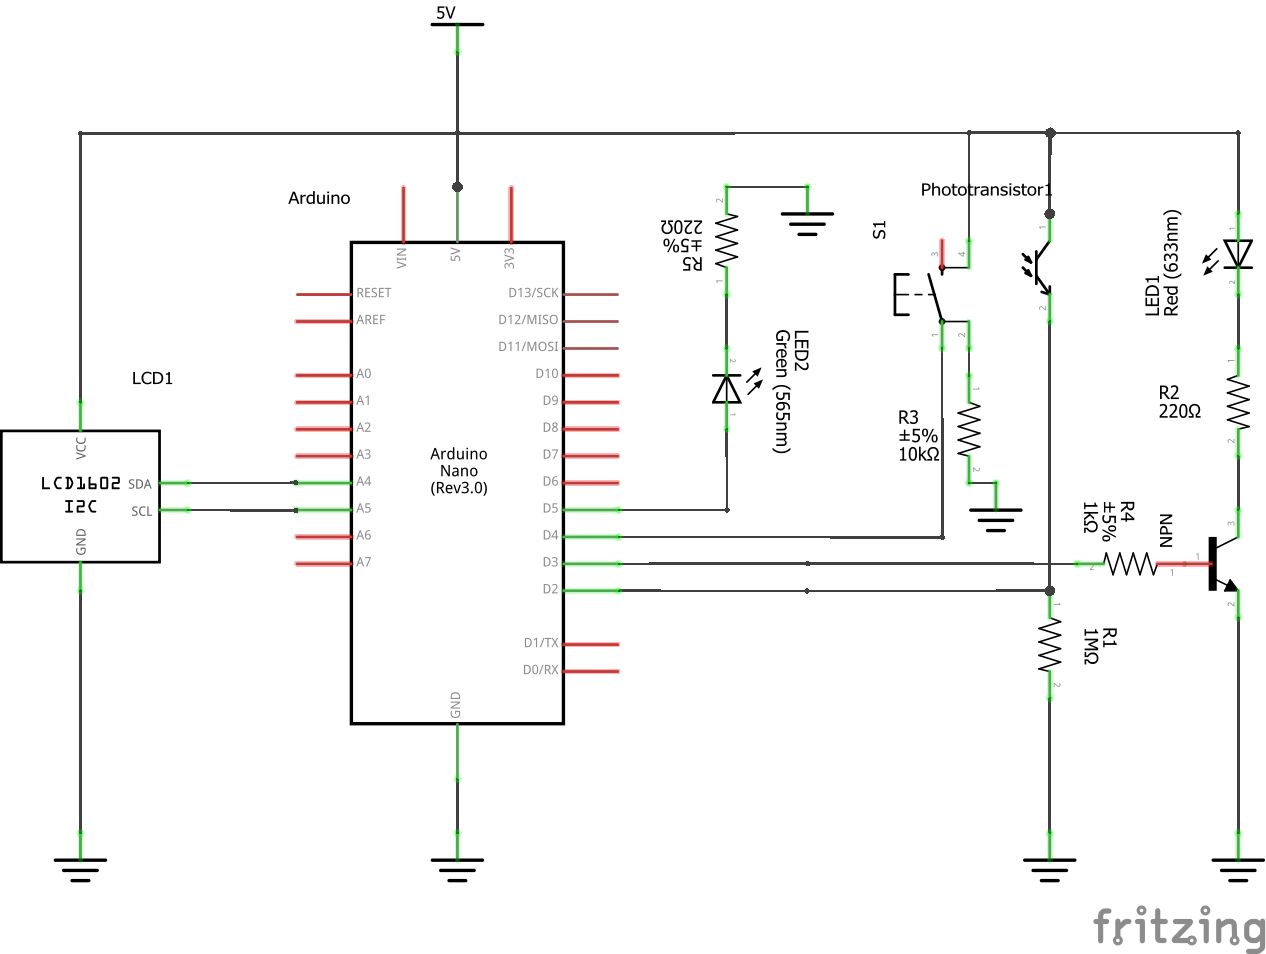
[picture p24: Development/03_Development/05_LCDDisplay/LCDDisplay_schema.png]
LCD Display schema


### Code

The code uses the [LiquidCrystal_I2C library](https://www.arduinolibraries.info/libraries/liquid-crystal-i2-c)

And here is the code result :
[Code for LCD Display](05_LCDDisplay/LCDDisplay/LCDDisplay.ino)

## 6. Bonus : create a sleeping mode

### Description  

The sleeping mode is intended to prevent the battery to get empty too fast when forgetting to switch off the device.  
The idea is to switch off the main consumption sources (Light Source LED, LCD back light, Arduino, ...). However, when the device is in sleeping mode, it can be easily forgotten by the user. So, when in sleeping mode, the device should flash periodically to show that it is still on.

- [ ] **TODO : implementation of a sleeping mode**

## 7. Create the Printed Circuit Board (PCB)

### Description  

The goal of this step is to create a PCB for our device
For the previous steps, we used Fritzing for the circuit description, because it is very convenied to draw quickly both schema and breadboard sketch.  
However, for the design of the target PCB, we will use a more precise design tool : Kicad.  
### Realisation
The first step is to create an empty project :  
[Kicad project](../../design/Kicad_shutter_speed_tester/shutter_speed_tester.pro)  

Then, the second step is to create a schema.
The goal of the schema is different from that one drawn with Fritzing : the goal is not to describe the whole circuit, but to focus on the main board of the tool.  
So some choices have to be made, mainly concerning the interfaces of this board :
* Internal interfaces  
  * I2C LCD
  * Power
* External interfaces
  * Light source LED
  * Light Sensor

| Internal Interfaces| Interface implementation |  
|---|---|
| I2C LCD | 4 pins PCB header |
| Power | 2 pins PCB header|
| Arduino socket | the Arduino will not be directly soldered on the main board, but placed on it using 2 rows of 15 pins female Dupont headers |

| External interfaces | Interface implementation|
| --- | --- |
| Light source LED | One option is to have a socket, such as an audio jack socket, directly soldered on the PCB, that socket would be accessible through a hole made at the side of the case. Such an option makes difficult the general design of the PCB and is considered as too constraining.</br>The following solution is prefered : an internal PCB header is placed on the board. From this header is connected a wire, directly connected to the light source LED, or through a second connector placed at the side of the case. </br>another option is to have the light source LED wrapped at the side of the case, internally connected to the board using a wire.</br> So the choice is : 2 pins PCB header |
| Light Sensor| In order to be easily adapted to different camera format and models, the light sensor has to be placed in a separated device, that can easily adapt to camera backs. So a wire has to be used, directly or through an intermediate connector placed at the side of the case. In all cases we need : </br>2 pins PCB header |
| Reset button| The choice is to place the reset button on the main board, it will be mechanically accessible to the operator using a button placed through the case |
| Control LED | As for the reset button, the control LED will be soldered on the main board, and accessible to the operator through the case |

Conclusions : 
On the schema, the power, the light source, the light sensor and the lcd will not be present, but instead a connector will be used

Result : 
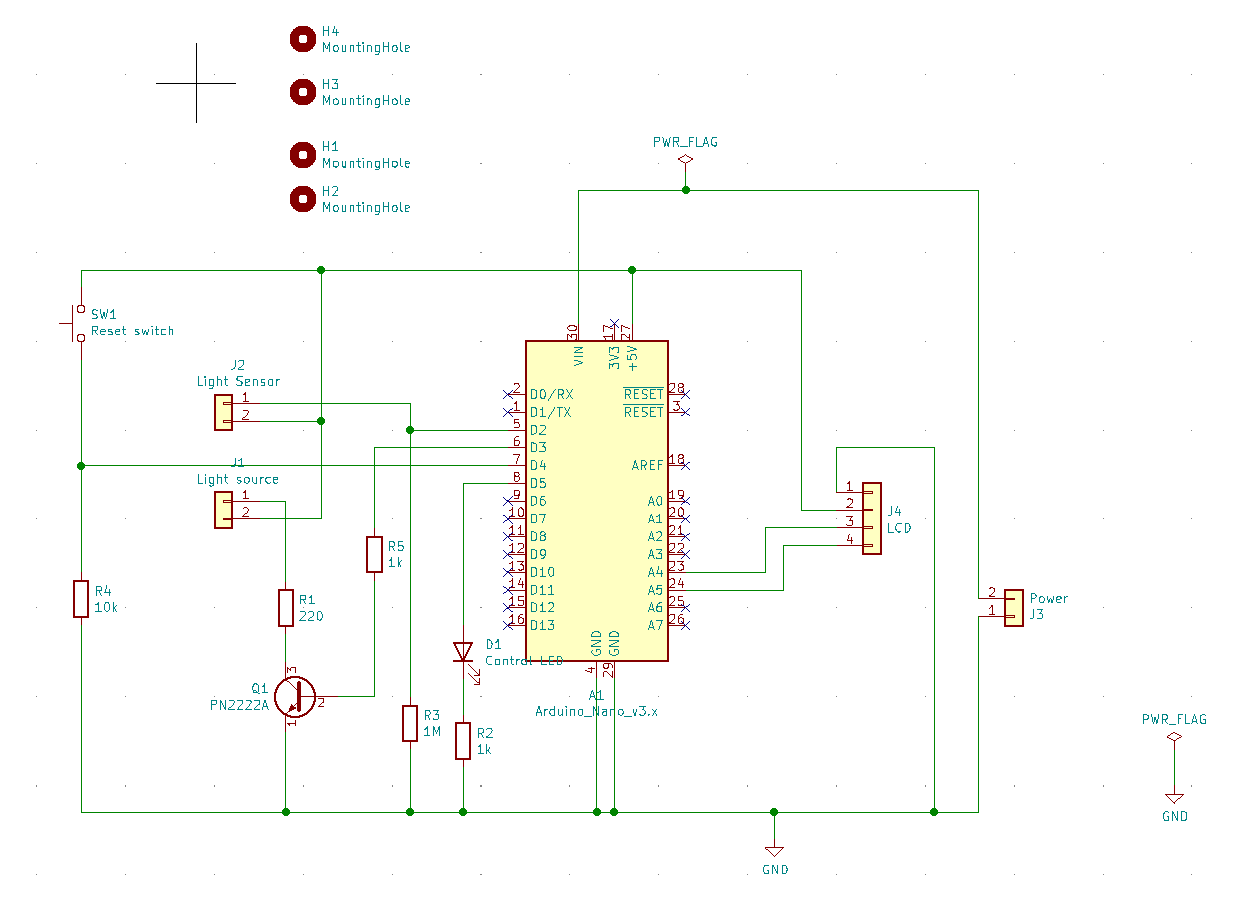
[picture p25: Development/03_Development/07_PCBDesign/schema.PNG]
PCB schema


After the schema design, before beginning the physical design of the board, it is necessary to assign a physical component to each of the schematic component.  
For all the PCB headers, we decide to use Molex 6410 headers (they are also referenced KF2510, depending on the provider).  These headers are low priced, and cannot be plugged in the wrong way.

Here are the correspondance between the shematic components and the components footprints (the real components) :

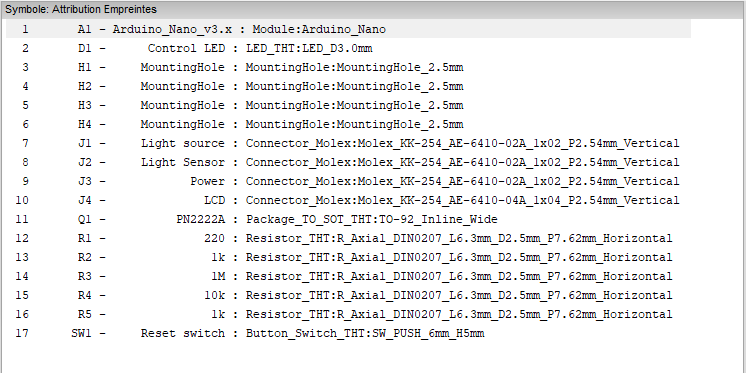
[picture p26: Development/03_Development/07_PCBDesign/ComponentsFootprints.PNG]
Components footprints


And then, the physical PCB can be designed :
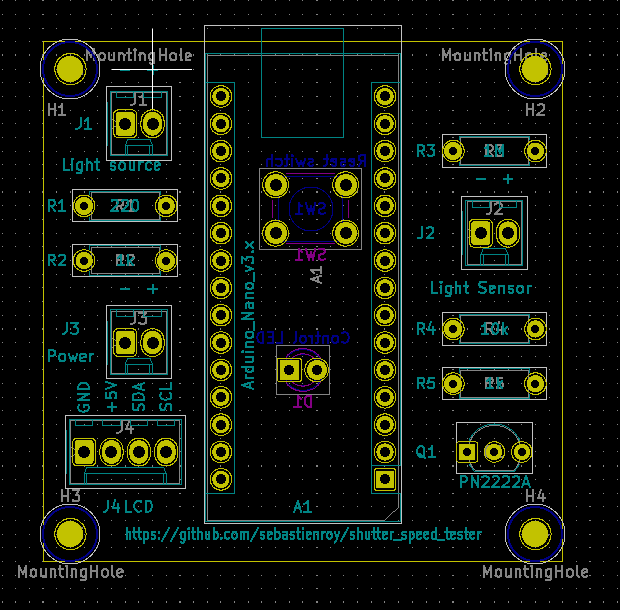
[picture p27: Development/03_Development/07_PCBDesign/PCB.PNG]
PCB Design


Note that the switch and the controled LED are placed at the back side of the board.
Note also that no via was used for the board design

And finally, the 3D views :
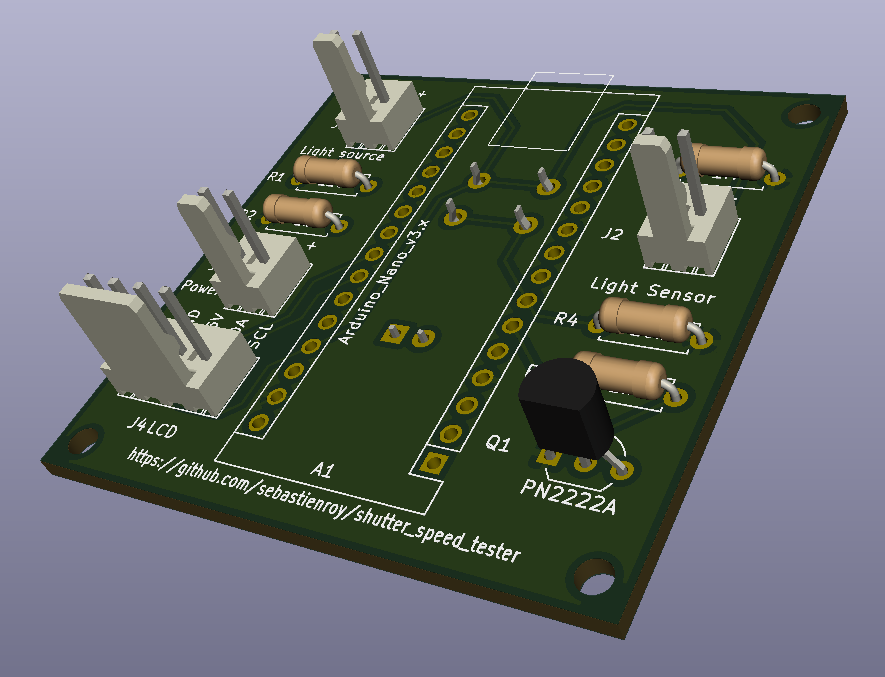
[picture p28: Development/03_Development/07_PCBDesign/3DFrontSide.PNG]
Front side


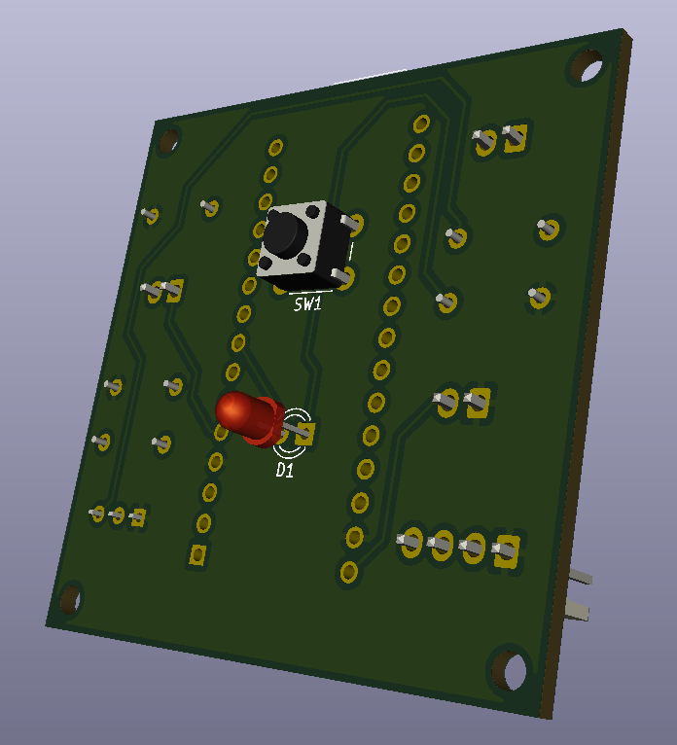
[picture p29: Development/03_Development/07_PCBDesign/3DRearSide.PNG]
Rear side


## 8. Automatically update LCD IIC address

### Description

The LCD display is connected through I2C interface. The interface has an address that can vary from one provider to another.
So the idea is to automatically set the address, instead of having it hard coded.  

This can be achieved using EEPROM memory.  
The library documentation is here :  
[Arduino EEPROM programming guide](https://docs.arduino.cc/learn/programming/eeprom-guide)

### Realisation  

It's fine.

## 9. Setup mode

### Description
In order to help the user to place correctly the sensor at the back of the camera and to place correctly the side of the tester in front of the camera, a setup mode can be usefull.  
In such a mode, the device doesn't measure the opening time. The light source is kept lit, and the control LED is on when the sensor detects some light.  
To enter in this mode, a long press on the reset button is needed.

### Realisation

- [ ] **TO DO : update of state diagram, code implementation**

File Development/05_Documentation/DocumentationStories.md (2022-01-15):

# Documentation Stories

[User Manual](UserManual.md)  
[Build Manual](BuildManual.md)  
[Bill of Material (BOM)](PartList.md)

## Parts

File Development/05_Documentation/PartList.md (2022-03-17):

## Part list
| Name | Description | Aprox. Price | Reference |
| ----- | ---| --- | --- |
| Main board | The board designed for shutter speed tester purpose | 12.73 € / 3 pcs | https://aisler.net/p/NGWECDGA |
| High power Led | A 8000 mcd red led | 0.62 € | 1050453 - LED 5 mm L-7113SEC-J3</br>https://www.conrad.fr/p/kingbright-l-7113sec-j3-led-rouge-rond-5-mm-8000-mcd-20-20-ma-22-v-1050453 |
| Green LED | | 0.17 € | 180180 - LED 5 MM SUPER LUMIN TYPE L-7113CGDK</br>https://www.conrad.fr/p/kingbright-l-7113cgdk-led-vert-rond-5-mm-140-mcd-30-20-ma-21-v-180180|
| Push button | | 0.23 €| 705338 - INTERRUPTEUR LOW COST JTP-1230L</br>https://www.conrad.fr/p/te-connectivity-1825910-2-bouton-poussoir-a-pression-24-vdc-005-a-1-x-offon-a-rappel-1-pcs-701749 |
| Toggle switch | Used as power switch | 1.53 € | 1587528 - Inter à bascule TC-R13-70A-01</br>https://www.conrad.fr/p/interrupteur-a-bascule-tru-components-tc-r13-70a-01-1587528-24-vdc-10-a-1-x-offon-a-accrochage-1-pcs-1587528 | 
| JST XH connector or </br> molex 6410 / KF2510 connector |  molex 6410 are finally used  | | Standard component  |
| Arduino nano | | 13 € | https://www.conrad.fr/p/tru-components-carte-de-developpement-atmega328-nano-development-board-2134126 |
| 15 pins 2.54mm female pcb header| These headers are used to plug the Arduino Nano on the pcb|| Standard component|
| Resistors :</br>220 Ohm</br>1k Ohm (x2)</br>10k Ohm</br>220k Ohm | Carbon film, 1/4 W THT | 0.08 € x5 | https://www.conrad.fr/p/resistance-a-couche-carbone-yageo-cfr25j220rh-220-sortie-axiale-0207-025-w-1-pcs-1417693</br>https://www.conrad.fr/p/resistance-a-couche-carbone-yageo-cfr25j1k0h-1-k%CF%89-sortie-axiale-0207-0.25-w-1-pc-s-1417699</br>https://www.conrad.fr/p/resistance-a-couche-carbone-yageo-cfr25j10kh-10-k%CF%89-sortie-axiale-0207-0.25-w-1-pc-s-1417697</br>https://www.conrad.fr/p/resistance-a-couche-carbone-yageo-cfr25j220kh-220-k-sortie-axiale-0207-025-w-1-pcs-1417665 |
| LCD 1602 | | 9.49 € | https://www.conrad.fr/p/display-elektronik-ecran-lcd-16-x-2-pixel-l-x-h-x-p-80-x-36-x-66-mm-2238810|
| I2C Interface for LCD || 4.50 € | https://www.conrad.fr/p/iduino-me033-1-pcs-2315239 |
| Phototransistor | | 0.46 €| Vishay, Visible light, TEPT4400</br>https://fr.rs-online.com/web/p/phototransistors/7000776 |
| Transistor 2N2222| NPN Transistor | 0.10 € | 1265001 - Transistor bipolaire PN2222ATA</br>https://www.conrad.fr/p/on-semiconductor-transistor-bjt-discret-pn2222ata-to-92-3-1-npn-1265001|
| Wire || 0.54 €| 457844 - Câble audio NF1106005</br>https://www.conrad.fr/p/bkl-electronic-1106005-cable-audio-1-x-010-mm-noir-marchandise-vendue-au-metre-457844|
| 9V battery connector | | 0.55 € | https://www.conrad.fr/p/connecteur-clip-pression-1x-6lr61-9-v-beltrona-9v-t-clip-raccordement-par-empreinte-pile-9v-l-x-l-x-h-26-x-13-x-8-mm-490660 |
| Small screw ||2.90 € / 200 pcs | https://www.visserie-boulonnerie-en-ligne.fr/visserie/vis-a-tole-tete-cylindrique-din-7981-pozidrive/vttc020200605i2-po-vis-a-tole-tete-cylindrique-empreinte-pozidri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 |
| Longer screw || 2.90 € / 200 pcs | https://www.visserie-boulonnerie-en-ligne.fr/visserie/vis-a-tole-tete-cylindrique-din-7981-pozidrive/vttc0209013i2-po-vis-a-tole-tete-cylindrique-empreinte-pozidrive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 |
| PLA filament for 3D printing | The 3D printing of the case needs about 130g of PLA filament  |  5.08 € (0.13kg x 39.08€/kg) | https://fr.rs-online.com/web/p/materiaux-pour-impression-3d/8320273</br>https://fr.rs-online.com/web/p/materiaux-pour-impression-3d/8320270|

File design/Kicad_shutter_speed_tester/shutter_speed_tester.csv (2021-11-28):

Reference | Value | Footprint | Datasheet
H3 | MountingHole | MountingHole:MountingHole_2.5mm | ~
H2 | MountingHole | MountingHole:MountingHole_2.5mm | ~
H1 | MountingHole | MountingHole:MountingHole_2.5mm | ~
H4 | MountingHole | MountingHole:MountingHole_2.5mm | ~
J4 | Power | Connector_Molex:Molex_KK-254_AE-6410-02A_1x02_P2.54mm_Vertical | ~
A1 | Arduino_Nano_v3.x | Module:Arduino_Nano | http://www.mouser.com/pdfdocs/Gravitech_Arduino_Nano3_0.pdf
R1 | 1meg | Resistor_THT:R_Axial_DIN0204_L3.6mm_D1.6mm_P5.08mm_Horizontal | ~
J3 | LCD | Connector_Molex:Molex_KK-254_AE-6410-04A_1x04_P2.54mm_Vertical | ~
Q1 | PN2222A | Package_TO_SOT_THT:TO-92_Inline | https://www.onsemi.com/pub/Collateral/PN2222-D.PDF
R4 | 1k | Resistor_THT:R_Axial_DIN0204_L3.6mm_D1.6mm_P5.08mm_Horizontal | ~
R2 | 220 | Resistor_THT:R_Axial_DIN0204_L3.6mm_D1.6mm_P5.08mm_Horizontal | ~
SW1 | Reset switch | Button_Switch_THT:SW_PUSH_6mm_H5mm | ~
R3 | 10k | Resistor_THT:R_Axial_DIN0204_L3.6mm_D1.6mm_P5.08mm_Horizontal | ~
D1 | Control LED | LED_THT:LED_D3.0mm | ~
R5 | 1k | Resistor_THT:R_Axial_DIN0204_L3.6mm_D1.6mm_P5.08mm_Horizontal | ~
J2 | Light source LED | Connector_Molex:Molex_KK-254_AE-6410-02A_1x02_P2.54mm_Vertical | ~
J1 | Light Sensor | Connector_Molex:Molex_KK-254_AE-6410-02A_1x02_P2.54mm_Vertical | ~

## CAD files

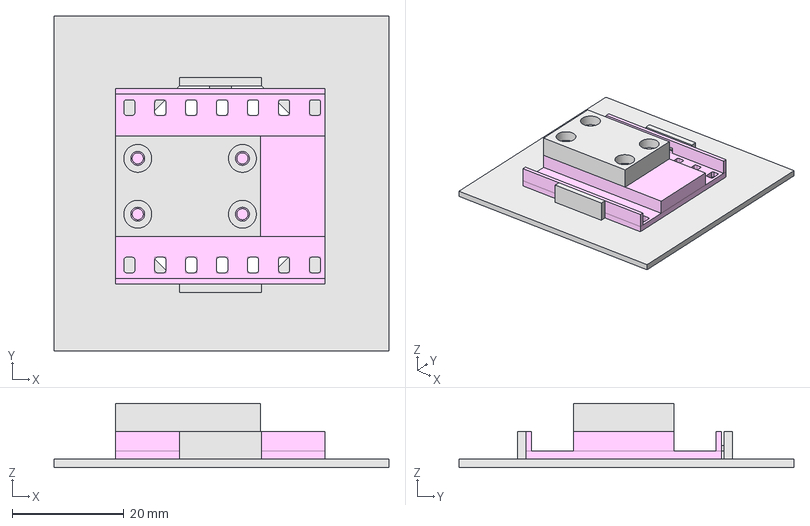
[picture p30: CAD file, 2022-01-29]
design/casing/LightSensorCasing.FCStd
60.0 x 60.0 x 11.5 mm
SensorCover
6x6Adapter

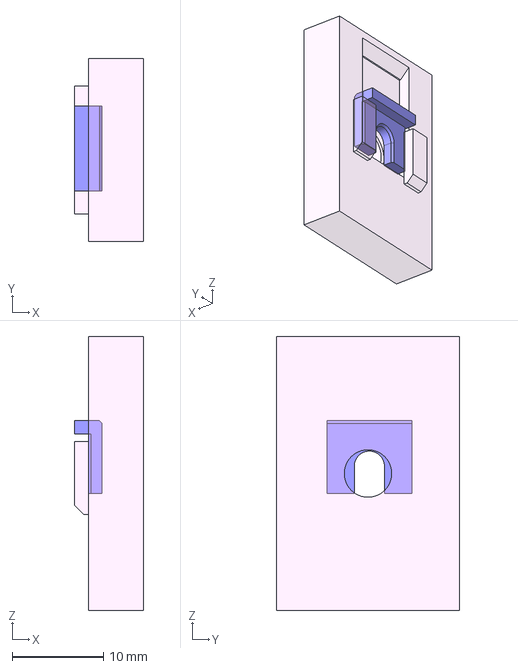
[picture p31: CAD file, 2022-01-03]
Development/04_Casing/02_LightSourceHousing/LightSourceHousingTest.FCStd
7.50 x 20.0 x 30.0 mm
Test Insert LED
Calle LED

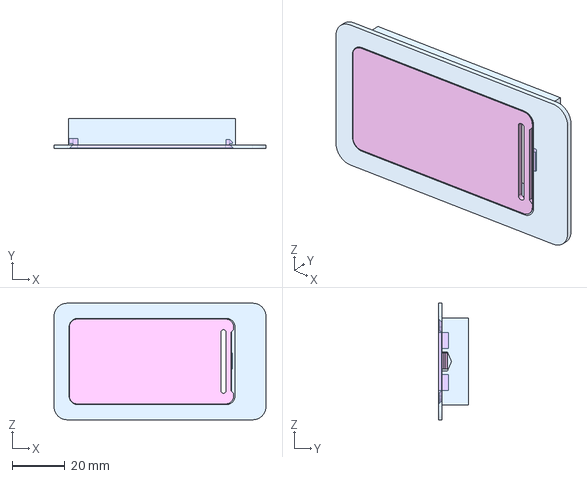
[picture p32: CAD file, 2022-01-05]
Development/04_Casing/03_BatteryDoor/BatteryDoor.FCStd
80.0 x 11.5 x 44.0 mm
Door

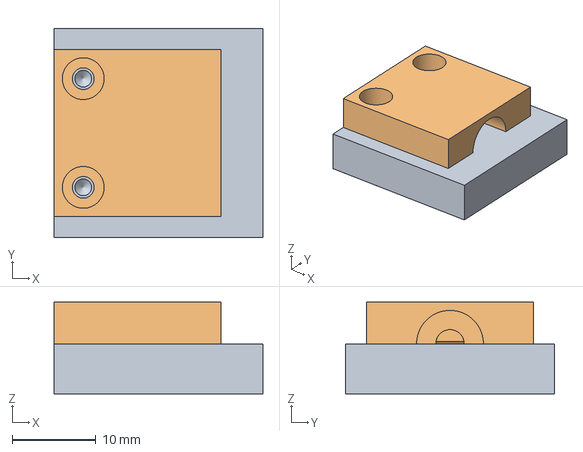
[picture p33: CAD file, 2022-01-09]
Development/04_Casing/04_WireBlocker/WireBlocking.FCStd
25.0 x 25.0 x 11.0 mm
Cover001

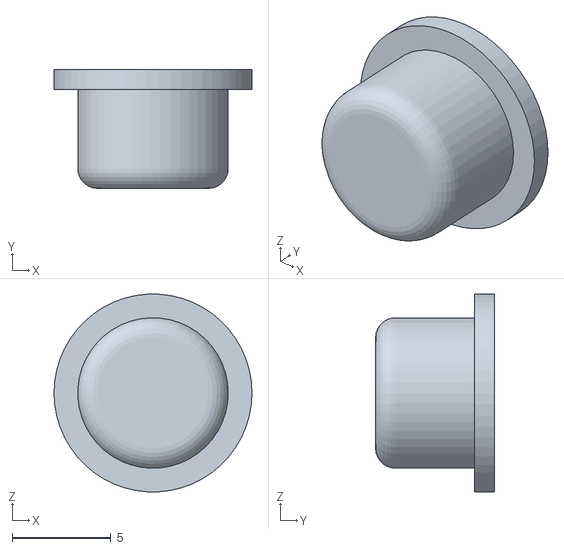
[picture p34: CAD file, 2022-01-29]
Development/04_Casing/parts/red/CasingForShutterSpeedTester-ResetButton.stl
10.0 x 6.00 x 9.98

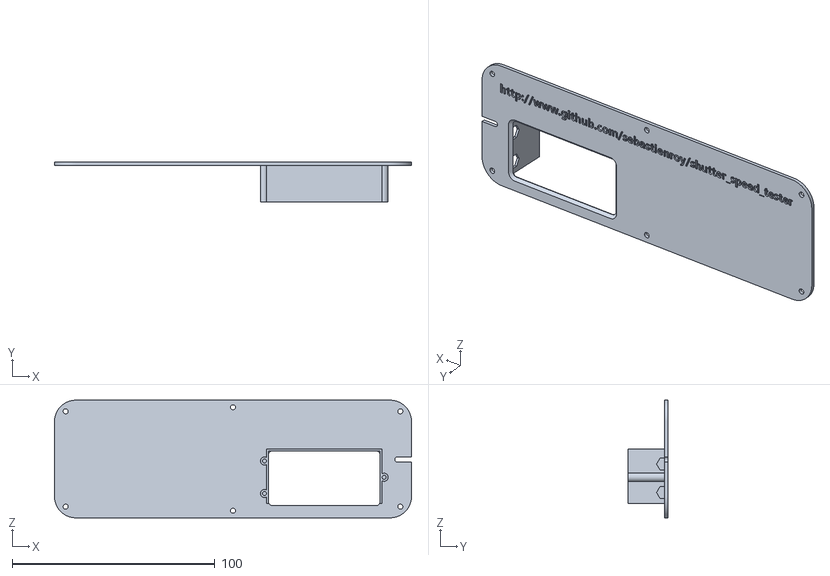
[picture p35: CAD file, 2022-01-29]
Development/04_Casing/parts/white/CasingForShutterSpeedTester-RearPanel.stl
176.0 x 19.5 x 58.0

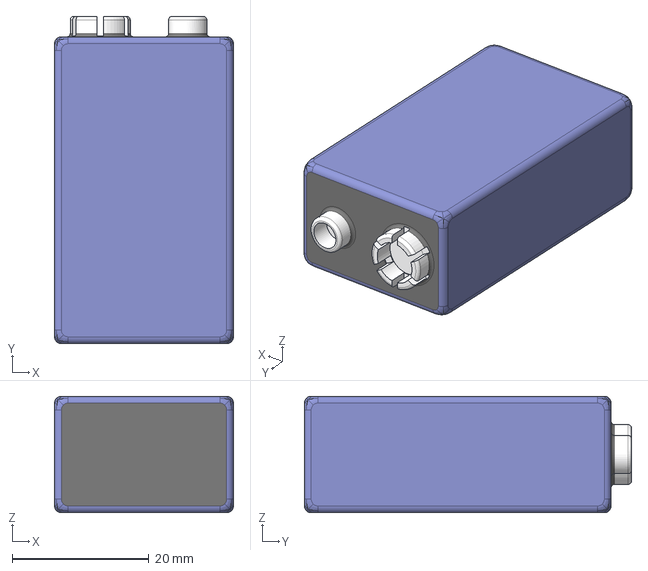
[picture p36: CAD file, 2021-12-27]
design/casing/9V battery v3.step
26.2 x 47.9 x 17.1 mm

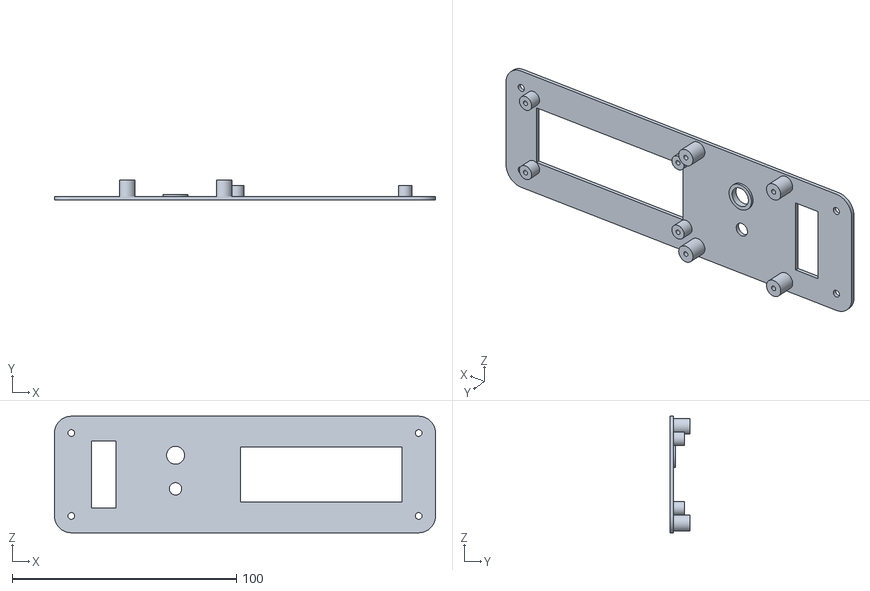
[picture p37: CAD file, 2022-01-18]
Development/04_Casing/parts/red/CasingForShutterSpeedTester-FrontPanel.stl
170.0 x 9.00 x 52.0

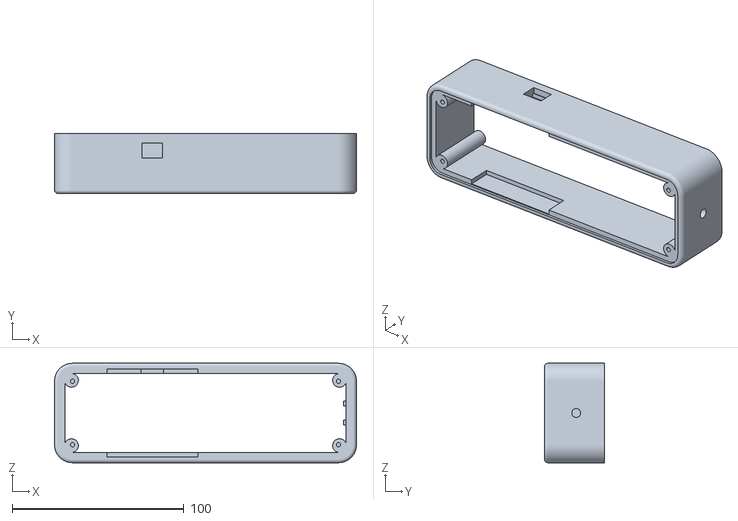
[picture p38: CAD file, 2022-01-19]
Development/04_Casing/parts/white/CasingForShutterSpeedTester-CaseBody.stl
176.0 x 35.0 x 58.0

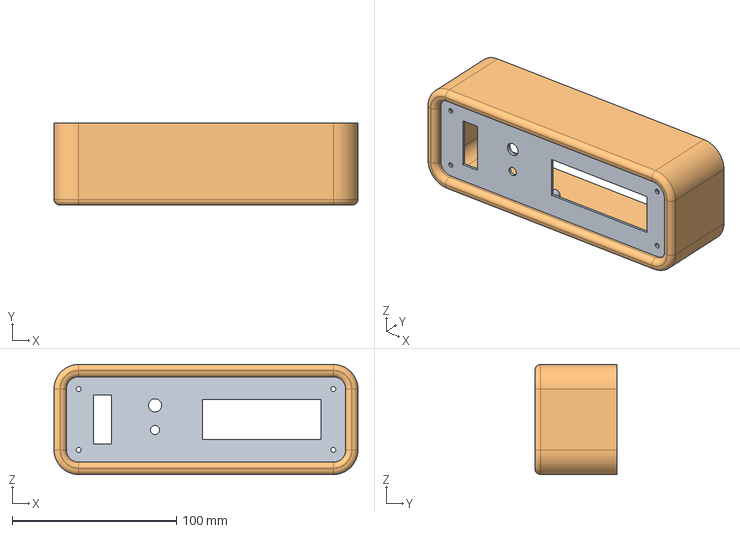
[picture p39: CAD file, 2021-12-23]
design/casing/CasingForShutterSpeedTester.FCStd
185.0 x 50.0 x 67.0 mm
FrontPanel
CaseBody

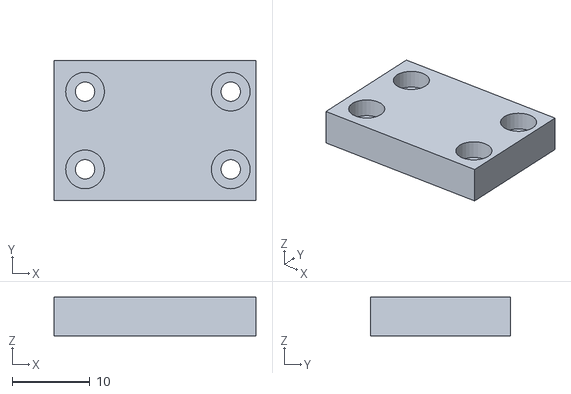
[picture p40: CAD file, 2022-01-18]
Development/04_Casing/parts/red/LightSensorCasing-SensorCover.stl
26.0 x 18.0 x 5.00

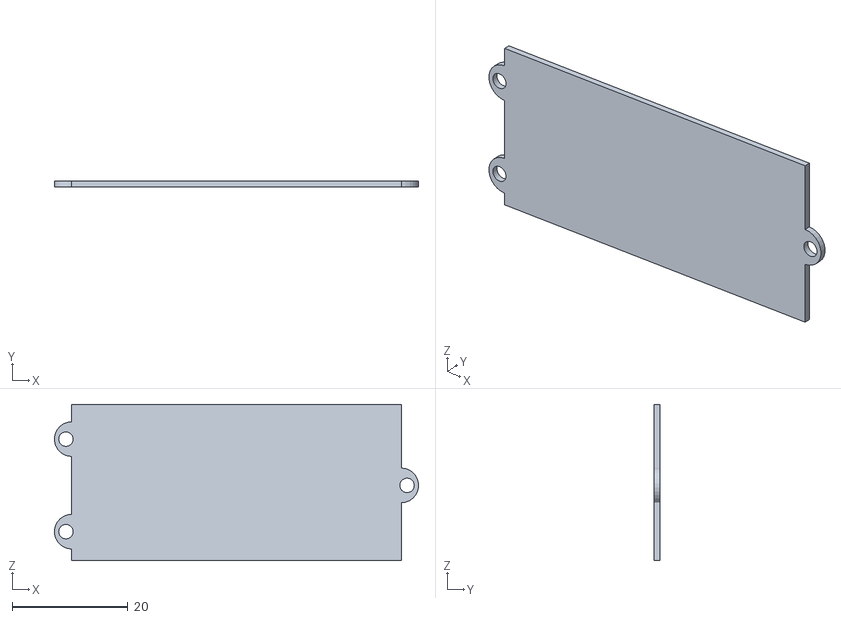
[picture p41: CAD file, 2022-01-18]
Development/04_Casing/parts/white/CasingForShutterSpeedTester-BatteryCageBack.stl
63.0 x 1.00 x 27.0

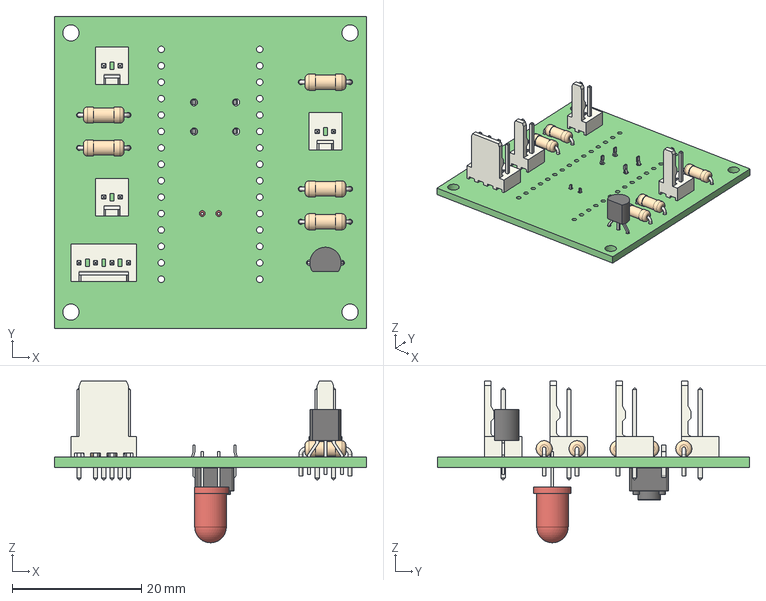
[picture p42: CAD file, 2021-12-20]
design/casing/shutter_speed_tester.step
48.3 x 48.3 x 25.0 mm

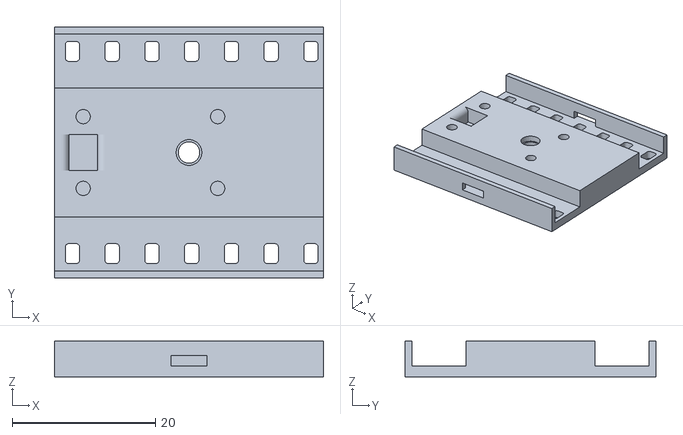
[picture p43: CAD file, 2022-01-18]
Development/04_Casing/parts/red/LightSensorCasing-Body001.stl
37.5 x 35.0 x 5.00

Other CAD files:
Development/04_Casing/parts/white/CasingForShutterSpeedTester-Door.stl
Development/04_Casing/parts/white/CasingForShutterSpeedTester-CoverWireBlocker.stl
Development/04_Casing/parts/white/LightSensorCasing-6x6Adapter.stl
Development/04_Casing/parts/white/CasingForShutterSpeedTester-Calle_LED.stl
Development/04_Casing/01_CaseFront/ScrewHoleTest.FCStd

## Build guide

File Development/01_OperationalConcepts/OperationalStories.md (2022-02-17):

# Operational Analysis

The operational analysis has to give an answer to the following points :  
- Who is the target audience ?
- What need will be statisfied by the project product ? (Conops)
- How the product will satisfied by the need ? (Conuse)
- What are the product expected advantages compared to existing products ?

## Target audience

The target audience is
* Film camera hobists
* Film camera repairers

## Operational concepts

### Camera hobist
A camera owner wants to use his camera to shoot film. Before loading the film into the camera, he checks the accuracy of the shutter speed using the shutter speed tester.  
So, if the speed is accurate, he is able to shoot in confidence to have the film correctly exposed.  
If the actual shutter speed is different than the speed selector indication, he is able to compensate the speed difference using either the aperture selector or the speed selector.  

### Camera repairer
As a professional or hobist, the camera reperair has to measure the shutteer speed of the camera at different speed selector positions. He uses for that the shutter speed tester.  
Knowing the difference between expected and actual speed value, he is able to adjust the springs tension of the shutter and thereby make the shutter more accurate.  

## Operational Usage

1. Put the source light of the shutter speed tester in front of the camera
2. Put the light sensor at the open back of the camera
3. Switch the device on
4. Press the camera shutter button
5. Read the measured camera speed (displayed as a time (t) and as a speed (1/t)), and compare it to the setting of the camera (1/60, 1/125, etc). Convert the difference in term of stops.
6. Press the Reset button on the device, perform the measure again, at all speed selector position.
7. You'll get, for each speed selector position, the number of stops needed to compensate to speed difference between expected and actual

### State Diagram of the Shutter Speed Tester

State diagram

### Speed measure to stop compensation 
Here is the formula to convert a given measure into a number of stops :
$$
\Delta_{stops} = log_2(\frac{S_m}{S_e})
$$
Where $S_m$ is the measured speed ans $S_e$ is the expected speed.  
### Example
If you measure a 1/60 speed, while the selector is at 1/125,  
$S_m=60$,  
$S_e=125$,  
$\to\Delta_{stops}\sim-1$  
So you must compensate the speed difference by closing the apperture of one stop compared to the theoretical value.

## Expected advantages of this tool, compared to that already existing

The researches on the web of such kind of tool give different results :
- Tools very expensive, more than 100 €
- Tools very tricky to use, that need to analyse a response curve on your computer or your smartphone
- Tools that have both properties
- Tools built by makers, but not integrated at all, not usable by common camera hobist

So, there is a room for a tool that would be all integrated, easy to use, at a reasonable price tag, let say less than 50€.

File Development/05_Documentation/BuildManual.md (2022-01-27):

# Shutter Speed Tester Build Manual

## Target audience

This build manual is intended for an allready skilled audience in following domains :
- Arduino usage
- Electronics circuits
- Soldering
- Wire crimping
- 3D printing

This manual is NOT a tutorial. It will not help you to learn the knowledges listed above. These knowledges are prerequisits.  
However, all the prerequisits can be easily aquired at school and/or by reading and practicing tutorials easily available on the web. So did the author of this manual.
The details of any of the described build steps can be found in the developement steps of the project.

## Construction description

- Solder components on the pcb :
  - On back side
    - 1x switch button
    - 1x control LED.
  - On front side :
    - 5x resistors
    - 1x transistor
    - 2x arduino female headers
    - 1x 4 pins KF2510 male connector
    - 3x 2 pins KF2510 male connectors
- Solder male headers on the Arduino board
- Solder I2C interface on the LCD display
- Solder wires on
  - phototransistor
  - Light source LED
- Crimp connectors on wires
  - LCD 4 wires : dupont connector at LCD side and KF2510 at PCB side
  - Battery adapter, Gnd on a 2 pins female KF2510, Vcc on a 1 pin Dupont female connector 
  - Switch connectors : 
    - on the above 2 pins KF2510 
    - on a male 1 pin Dupont connector 
  - Phototransistor, KF2510
  - Light source LED, KF2510
- System assembly and test
  - Plug the Arduino board 
  - Connect the LCD display
  - Connect the light source LED
  - Connect the phototransistor
  - Connect the battery adapter and the switch  
  - Connect the Arduino on the computer, and upload the code
  - Adjust the display contrast
  - Test the behaviour : states, measured value
  - Unplug from computer, connect to a battery
  - Switch on, test the behaviour
- 3D print all the case pieces
  - Remove all the adhesion layer
  - Check that all the pieces fit together, pay special attention on reset button and light souce LED blocking part.
- Sensor assembly
  - Insert the phototransitor in its dedicated hole and screw the cover
- Front panel assembly
  - Insert the reset button  
  - Screw PCB and LCD on the front panel, connect them together
  - Insert power switch in the front panel, and connect it to the PCB and the battery adapter
- Case body assembly
  - Insert the light source LED in the case body, and block it using the piece printed for that usage
  - Connect all the wires
  - Screw the front panel on the case body
  - Block the sensor wire on the body
- Assembly of the rear panel
  - Screw the battery cage back on the rear panel
  - Screw the rear panel on the body
- Final test with a battery

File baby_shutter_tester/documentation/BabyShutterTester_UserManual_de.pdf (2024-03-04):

# Baby Shutter Tester - Gebrauchsanweisung

Der Baby Shutter Tester ist ein Gerät zur Messung der Verschlusszeit von analogen Kameras.

## Übersicht

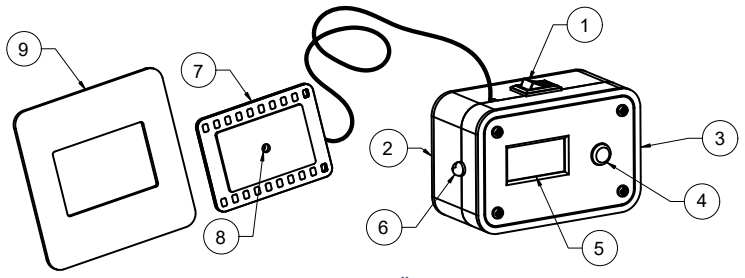
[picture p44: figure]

Abbildung 1 : Übersicht

1. Ein/Aus-Schalter
2. Batteriefach für LR03/AAA-Batterien
3. Mikro-USB-Anschluss
4. Taste zum Zurücksetzen und Aufheben der Modusauswahl
5. Display
6. LED-Beleuchtung
7. Sensorhalterung
8. Lichtempfindlicher Sensor
9. Mittelformatadapter

## Inbetriebnahme

Die Kamera kann entweder über ein Mikro-USB-Kabel oder über zwei LR03-Batterien (AAA) mit Strom versorgt werden.
Wenn die im Betrieb von den Batterien gelieferte Spannung zu niedrig ist, wird auf dem Bildschirm eine Anzeige für schwache Batterien ( ) angezeigt. Wechseln Sie die Batterien aus, um einen unregelmäßigen Betrieb zu vermeiden.
Es ist notwendig die Batterien zu entfernen wenn Sie die Kamera über einen längeren Zeitraum nicht benutzen.

Der Baby Shutter Tester sollte vor Feuchtigkeit und Wärmequellen geschützt werden.
Er ist für den Betrieb in einem Temperaturbereich von 5 bis 40 °C vorgesehen.

## Funktionsweise

- Öffnen Sie die Rückseite Ihrer Kamera.
- Legen Sie den Sensor anstelle des Films auf die Rückseite der Kamera, wobei der Fototransistor zum Verschluss der Kamera zeigt. Bei Mittelformatkameras verwenden Sie den mitgelieferten Adapter. Achten Sie darauf, dass der Sensor zentriert ist, und fixieren Sie ihn mit einem Gummiband oder einer anderen Vorrichtung.
- Platzieren Sie das Gehäuse vor Ihrer Kamera, eventuell mit einer Erhöhung, damit die Beleuchtungs-LED der Kamera auf den Sensor gerichtet ist. Die LED des Baby Shutter Testers hat einen Beleuchtungskegel von 20°. Für die Durchführung der Messungen ist es notwendig, dass sich der Sensor innerhalb dieses Beleuchtungskegels befindet. Vermeiden Sie es, den Lichtstrahl in Richtung der Augen zu richten.
- Schalten Sie den Baby Shutter Tester ein. Das Display zeigt "Ready" an und die Beleuchtungs-LED leuchtet.

- Um sicherzustellen, dass das Gehäuse des Baby Shutter Testers und sein Sensor richtig positioniert sind, verwenden Sie den Testmodus (siehe nächstes Kapitel). Um präzise Messungen bei hohen Verschluss-Geschwindigkeiten (1/250 Sekunde und schneller) durchzuführen, stellen Sie Ihr Set auf ein festes Gestell und führen Sie vorher die Kalibrierung des Testers durch.
- Wählen Sie die Verschluss-Geschwindigkeit, die Sie messen möchten, auf Ihrer Kamera aus.
- Lösen Sie den Verschluss aus. Während der Öffnungsphase des Verschlusses zeigt der Baby Shutter Tester eine Sonne an, um anzuzeigen, dass er Licht erkennt. Diese Phase kann je nach der an der Kamera gewählten Verschlusszeit sehr kurz sein.
- Nachdem der Verschluss geschlossen wurde, wird der gemessene Geschwindigkeitswert auf dem Bildschirm angezeigt.
- Vergleichen Sie den gemessenen Wert mit dem am Geschwindigkeitswahlrad Ihrer Kamera gewählten Wert.
- Um eine neue Messung vorzunehmen, drücken Sie die Reset-Taste.
Bei exakter Anwendung kann der Baby Shutter Tester Messungen von mehreren Sekunden bis zu 1/4000 Sekunde mit einer Zuverlässigkeit im Bereich von Mikrosekunden durchführen.

## Die verschiedenen Betriebsarten

Der ursprüngliche Betriebsmodus des Baby Shutter Testers, ist der "Messmodus", mit dem die Geschwindigkeitsmessungen durchgeführt werden.
Das Gerät verfügt aber auch über andere Betriebsmodi, die die Positionierung und Kalibrierung erleichtern oder Informationen anzeigen. Durch langes oder kurzes Drücken der Taste am Gerät kann zwischen den einzelnen Modi gewechselt werden.

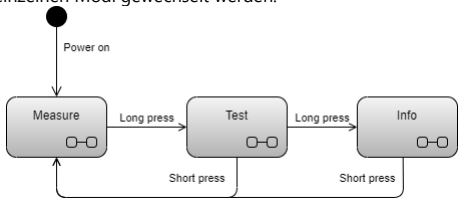
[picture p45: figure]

Abbildung 2 : Betriebsmodi und Wechsel von einem Modus in den anderen

Messungsmodus

In diesem Modus können Sie die Geschwindigkeit Ihrer Kamera messen (siehe Funktionsweise weiter oben).

Testmodus

In diesem Modus können Sie den Sensor auf der Rückseite der Kamera richtig positionieren und die höchste Messgenauigkeit erzielen.
Um eine zuverlässige Messung bei hohen Geschwindigkeiten (1/250 und schneller) zu erhalten, ist eine optimale Positionierung der LED des Gehäuses in Bezug auf den Sensor unerlässlich. Dies ist der Prozess der Kalibrierung.
Damit die Kalibrierung und die Messungen zuverlässig sind, müssen Sie bei gedämpftem Licht arbeiten, d. h. unter Bedingungen, bei denen das Umgebungslicht, das auf den Sensor trifft, im Vergleich zu dem Licht, das von der LED kommt, gering ist.

Nachdem Sie den Sensor auf der Rückseite der Kamera korrekt zentriert und die LED des Gehäuses vor sich platziert haben, wählen Sie eine langsame Geschwindigkeit oder Pause B an Ihrer Kamera

Abbildung 3 : Anzeigen im Testmodus

Im Testmodus wird, solange der Sensor das Licht der LED nicht erkennt, auf der linken Seite des Bildschirms ein Kreis angezeigt (Anzeige 1).
Wenn der Sensor die LED erkennt, wird anstelle des Kreises eine Sonne angezeigt.
- Wenn sich die LED zu nah am Sensor befindet, wird in der Mitte des Bildschirms ein Rechtspfeil sowie eine negative Zahl angezeigt (Anzeige 2).
- Wenn die LED zu weit vom Sensor entfernt ist, wird in der Mitte des Bildschirms ein Pfeil nach links sowie eine positive Zahl angezeigt (Anzeige 3).
- Wenn die LED im richtigen Abstand positioniert ist, wird in der Mitte des Bildschirms ein Punkt sowie eine Zahl zwischen -10 und 10 angezeigt (Anzeige 4).
Die letzte Entfernungsanzeige bleibt 2 Sekunden lang bestehen, nachdem die Kamera die LED nicht mehr erkennt. Dies erleichtert die Kalibrierung, auch wenn die Kamera weder den Langsamfahrmodus noch den B-Modus hat.

Wenn das Objektiv Ihrer Kamera abnehmbar ist, ist die Kalibrierung einfacher, wenn das Objektiv entfernt wird.
Wenn das Objektiv nicht abnehmbar ist oder das Messobjekt ein Zentralverschluss ist, der sich im Objektiv befindet, wird das Verfahren erleichtert, wenn die Blende auf volle Öffnung und der Fokus auf Unendlich eingestellt ist.
Wenn Ihre Baugruppe richtig positioniert ist, kehren Sie in den Messmodus zurück und führen Sie die Geschwindigkeitsmessungen unter exakt denselben Bedingungen wie die Kalibrierung durch.
Eine falsche Positionierung der LED in Bezug auf den Sensor kann bei einer Geschwindigkeit von 1000stel Sekunden zu einem Messfehler von bis zu 1 Blende führen.

Info-Modus

In diesem Modus zeigt der Bildschirm Informationen über die Kamera an, einschließlich der Versionsnummer der Firmware.

## Durchführung der Messung je nach Verschlusstyp

Es werden hauptsächlich zwei Arten von Verschlüssen unterschieden:
- Die Schlitzverschlüsse (Vorhangverschlüsse).
- Die Zentralverschlüsse (centeral shutters).
Der Baby Shutter Tester zeigt einen Wert für die Verschlussgeschwindigkeit. Unter bestimmten Bedingungen ist dieser Wert allein jedoch nicht ausreichend genau, um die Belichtung zu bestimmen.

Schlitzverschluss

Beim Schlitzverschluss kommen zwei Vorhänge zum Einsatz, die sich nacheinander in die gleiche Richtung bewegen. Auf das Öffnen des einen folgt das Schließen des anderen. Wenn sich beide

Vorhänge mit der gleichen Geschwindigkeit über die gesamte Fläche bewegen, ist die Belichtung gleichmäßig und wird durch die Messung des Baby Shutter Testers genau angezeigt.
Wenn sich die beiden Vorhänge mit unterschiedlichen Geschwindigkeiten bewegen, führt dies zu unterschiedlichen Belichtungen in den verschiedenen Teilen des Fotos. Für eine Kamera mit nur einem Sensor wie den Baby Shutter Tester ist es schwierig, ein solches Phänomen zu beurteilen. Wenn es für Sie notwendig ist, wenden Sie sich an ein Gerät mit mehreren Sensoren wie den Shutter Lover desselben Herstellers.

Zentralverschluss

Der Zentralverschluss hat die Eigenschaft, dass er in drei Phasen arbeitet: Öffnen, volle Öffnung und Schließen.
Wenn die volle Öffnung im Verhältnis zu den Öffnungs- und Schließphasen lange dauert, ist alles in Ordnung, und die gemessene Geschwindigkeit entspricht der Belichtung, die der Film haben wird. Wenn dies nicht mehr der Fall ist (bei sehr hohen Geschwindigkeiten, aber auch wenn sich die Verschlusslamellen zu langsam bewegen), kann es zu einer Abweichung zwischen der gemessenen Geschwindigkeit und der tatsächlichen Belichtung des Films kommen, da die Zwischenphase, in der der Verschluss weder ganz offen noch ganz geschlossen ist, nicht zu vernachlässigen ist.
Dies hat zur Folge, dass die Geschwindigkeitsmessung im optischen Zentrum mit dem Baby Shutter Tester unterschätzt wird. Bei der maximalen Geschwindigkeit eines Zentralverschlusses ist eine Unterschätzung der Geschwindigkeit um bis zu einer Blende üblich. In einem solchen Fall sollte man sich also keine Sorgen machen. Wenn Sie den Sensor so nah wie möglich am Verschluss platzieren (also auf der Seite des Objektivs), können Sie Messungen in der Mitte und am Rand durchführen. Die gemessene Zeitdifferenz gibt Ihnen die Zeit an, die die Lamellen zum Öffnen und Schließen benötigen.

## Eingeschränkte Garantie

Der Baby Shutter Tester wurde mit größter Sorgfalt entwickelt und hergestellt, dennoch übernimmt sein Hersteller keine Verantwortung für die Folgen seiner Verwendung.

Alle ausdrücklichen oder stillschweigenden Garantien, einschließlich, aber nicht beschränkt auf die stillschweigenden Garantien der Marktgängigkeit und der Eignung für einen bestimmten Zweck, werden abgelehnt. In keinem Fall haftet der Hersteller für direkte, indirekte, zufällige, besondere, exemplarische oder Folgeschäden (einschließlich, aber nicht beschränkt auf Nutzungs- oder Gewinnausfall oder Betriebsunterbrechung), unabhängig von der Ursache, die in irgendeiner Weise aus der Verwendung dieser Ausrüstung entstehen, selbst wenn er auf die Möglichkeit solcher

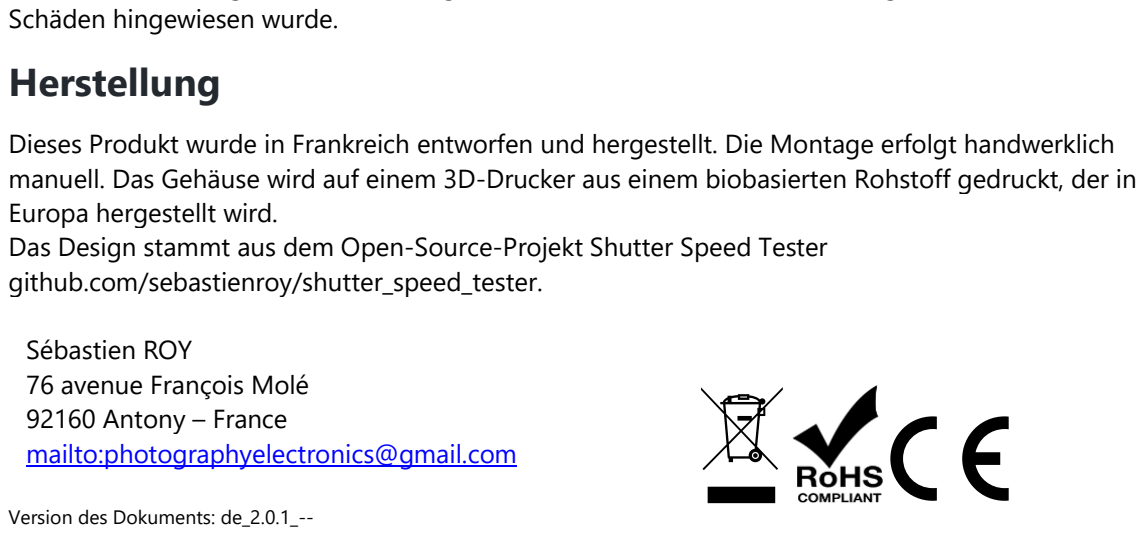
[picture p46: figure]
Schäden hingewiesen wurde.; Herstellung; Europa hergestellt wird.; github.com/sebastienroy/shutter_speed_tester.; Sébastien ROY 76 avenue François Molé 92160 Antony – France mailto:photographyelectronics@gmail.com; Version des Dokuments: de_2.0.1_--

Dieses Produkt wurde in Frankreich entworfen und hergestellt. Die Montage erfolgt handwerklich manuell. Das Gehäuse wird auf einem 3D-Drucker aus einem biobasierten Rohstoff gedruckt, der in

Das Design stammt aus dem Open-Source-Projekt Shutter Speed Tester

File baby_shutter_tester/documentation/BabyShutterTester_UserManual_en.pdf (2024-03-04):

# Baby Shutter Tester – User Manual

The Baby Shutter Tester is a device designed to check the accuracy of the shutter speed of film cameras.

# Presentation

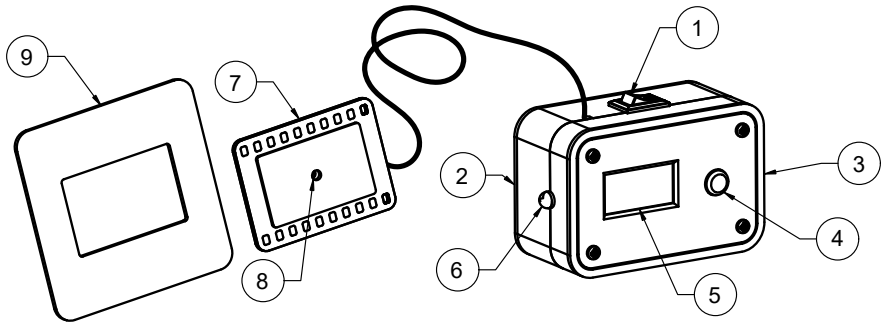
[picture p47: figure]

Figure 1 : Presentation

1. On/Off switch
2. LR03/AAA battery compartment
3. Micro-USB port
4. Reset and mode selection button
5. Display screen
6. Lighting LED
7. Sensor support
8. Light sensitive sensor
9. Removable 6x6 medium format adapter (120 film format)

# Setup

The device can be powered either by a micro-USB cable or by two LR03 (AAA) batteries.
When the voltage delivered by the batteries during operation is too low, a low battery indication ( ) appears on the display. Change the batteries to avoid erratic operation.
It is better to remove the batteries when the device is not used for a long time.

The Baby Shutter Tester should be kept away from moisture and heat sources. It is designed to operate over a temperature range from 5 to 40°C.

# Measurement operation

- Open the back of your camera.
- Place the sensor on the back of the camera, in place of the film. With medium format cameras, use the supplied adapter. Be sure to center the sensor, and hold it with a rubber band or other device.
- Place the main box in front of your camera, raising it if necessary, so that the illumination LED of the device is in front of the sensor. The Baby Shutter Tester LED has an illumination cone of 20°. It is necessary that the sensor is located in this lighting cone. Avoid projecting the light beam towards the eyes
- Turn on the baby Shutter Tester. The box displays "Ready" and the lighting LED is on

- To be sure that the Baby Shutter Tester box and its sensor are correctly positioned, use the Test mode (see next chapter). For accurate measurements at high speeds (1/250th of a second and faster), place your equipment in a fixed position and calibrate the tester first.
- Select the speed you want to measure on your camera.
- Trigger your camera's shutter. During the shutter opening phase, the Baby Shutter Tester displays a sun picture in order to indicate that it detects light. This phase can be very brief, depending on the speed chosen on the camera.
- Once the shutter is closed, the measured speed value is displayed on the screen
- Compare the measured value with the value chosen on the speed selector of your camera
- To perform a new measurement, press the reset button.
If used rigorously, the Baby Shutter Tester can perform measurements ranging from several seconds to 1/4000th of a second with a precision of a few microseconds.

# The different operating modes

The initial operating mode of the Baby Shutter Tester is the "Measurement" mode, with which speed measurements are carried out.
But the device also has other operating modes, to facilitate positioning and calibration, or to display information. A long or short press on the device button allows you to navigate from one mode to another.

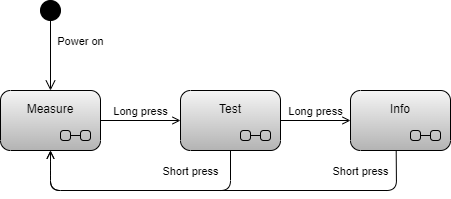
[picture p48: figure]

Figure 2 Operating modes and transitions from one mode to another

Measurement mode
This mode allows you to measure the speed of your camera (see Measurement Operation above). Test mode
This mode allows you to place the sensor correctly on the back of the camera, and obtain the best measurement accuracy.
To obtain a reliable measurement at high speeds (1/250th and faster), an optimum positioning of the tester's LED in relation to the sensor is essential. This is the calibration process.
To ensure that calibration and measurements are reliable, it is necessary to proceed in subdued light, i.e. in conditions where the ambient light hitting the sensor is lower than that coming from the LED.
After positioning the sensor on the back of the camera, correctly centred, with the LED of the tester in front of it, select a slow shutter speed or pause B on your camera and release the shutter.

Figure 3 : Test Mode displays

In Test mode, as long as the sensor does not detect the light from the LED, a circle is displayed on the left of the screen (display 1).
When the sensor detects the LED, a sun is displayed instead of the circle.
- If the LED is too close to the sensor, a right arrow is displayed in the centre of the screen, along with a negative number (display 2).
- If the LED is too far from the sensor, a left arrow is displayed in the centre of the screen, along with a positive number (display 3).
- If the LED is positioned at the right distance, a dot is displayed in the centre of the screen, along with a number between -10 and 10 (display 4).
The last distance indication display persists 2 seconds after the camera has stopped detecting the LED. This facilitates calibration even if the camera has neither slow speed nor B mode.

If your camera lens is removable, calibration will be easier when it is removed.
If the lens is not removable, or if the object of the measurement is a central (leaf) shutter located in the lens, the procedure is made easier when the aperture is set to full open and the focus is set to infinity.
Once your assembly has been correctly positioned, return to measurement mode and carry out the speed measurements under exactly the same conditions as the calibration.
Incorrect positioning of the LED in relation to the sensor can result in a measurement error of up to 1 f-stop for a speed of 1000th of a second.
Information mode
In this mode, the screen displays information about the device, including its firmware version number.

# Specificity of the measure according to the type of

shutter.

There are mainly two types of shutters:
- Focal plane shutters (curtain shutters)
- Leaf shutters (central shutters)
The Baby Shutter Tester gives an indication of shutter speed as a single value.
However, there are some cases where this simple value is not sufficient to determine the exposure. Focal plane shutter
The focal plane shutter uses two curtains that move successively in the same direction. The opening of the first is followed by the closing of the second. If the two curtains move at the same speed over the entire surface, the exposure is uniform and is given by the measurement of the Shutter Speed Tester.
If the two curtains move at different speeds, this will result in different exposures in different parts of the photo. It is difficult for a single-sensor device such as the Baby Shutter Tester to assess this type of phenomenon.
If you need to, turn to a multi-sensor device such as the Shutter Lover, from the same manufacturer.

Leaf shutter
The central shutter has the characteristic of operating in three phases: opening, full opening, and closing.
When full aperture lasts longer than the opening and closing phases, everything is fine, and the measured shutter speed corresponds to the exposure the film will have. When this is no longer the case (for very high speeds, but also if the shutter blades move too slowly), you can have a discrepancy between the measured speed and the actual exposure that the film will have, since the intermediate phase during which the shutter is neither fully open nor fully closed is not negligible. This results in a speed measurement at the optical centre that is underestimated with the Baby Shutter Tester. At the maximum speed of a central shutter, an underestimation of the speed by up to one f-stop is usual. So, there's no need to worry in this case.
If you place the sensor as close as possible to the shutter (on the lens side), you can take measurements in the centre and at the periphery. The difference in time measured will give you the time taken for the blades of the shutter to open and close.

# Limitation of warranty

The Baby Shutter Tester has been designed and manufactured with care. However, the manufacturer declines all responsibility for the consequences of its use.

All warranties, express or implied, including, but not limited to, implied warranties of merchantability and fitness for a particular purpose, are disclaimed. In no event shall the manufacturer be liable for any direct, indirect, incidental, special, exemplary or consequential damages (including, but not limited to, loss of use or profits, or business interruption), however caused, arising in any way out of the use of this equipment, even if advised of the possibility of such damages.

# Manufacture

This product has been designed and manufactured in France. Its assembly is made according to an artisanal process. The case is printed individually on a 3D printer with a bio sourced raw material produced in Europe.
Its design is an extension of the Shutter Speed Tester open-source project (github.com/sebastienroy/shutter_speed_tester).

Sébastien ROY
76 avenue François Molé
92160 Antony – France
mailto:photographyelectronics@gmail.com

Document version: en_2.0.1_--

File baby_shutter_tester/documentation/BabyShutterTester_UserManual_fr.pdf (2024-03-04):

# Baby Shutter Tester – Mode d’emploi

Le Baby Shutter Tester est un appareil destiné à mesurer la vitesse d’obturation des appareils photographiques argentiques.

## Présentation

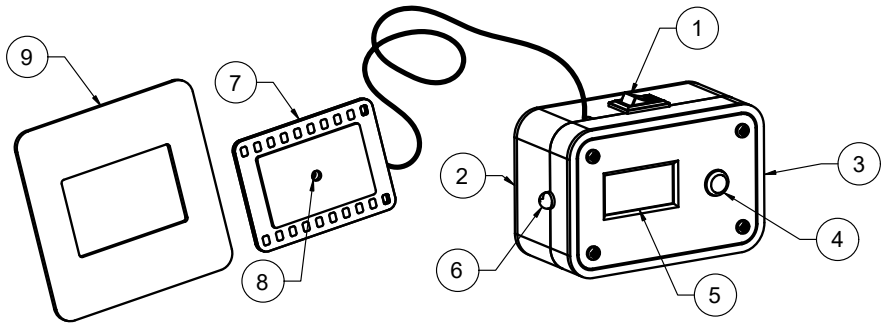
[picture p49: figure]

Figure 1 : Présentation

1. Interrupteur On/Off
2. Trappe à pile LR03/AAA
3. Port micro USB
4. Bouton de réinitialisation et de sélection de mode
5. Ecran d'affichage
6. LED d'éclairage
7. Support du capteur
8. Capteur photosensible
9. Adaptateur moyen format

## Mise en service

L'appareil peut être alimenté soit par un câble micro USB, soit par deux piles LR03 (AAA).

Lorsque la tension délivrée en fonctionnement par les piles est trop basse, une indication de batterie faible ( ) est affichée sur l’écran. Changez les piles pour éviter un fonctionnement erratique.
Veillez à enlever les piles lorsque vous n'utilisez pas l'appareil pendant une durée prolongée

Le Baby Shutter Tester doit être maintenu à l’abri de l’humidité et des sources de chaleur. Il est prévu pour fonctionner sur une plage de température de 5 à 40°C.

## Mode opératoire

- Ouvrez le dos de votre appareil photo.
- Placez le capteur à l’arrière de l’appareil photo, à la place de la pellicule, le phototransistor faisant face à l’obturateur de l’appareil photo. Pour les appareils moyen format, utilisez l’adaptateur fournit. Veillez à centrer le capteur, et maintenez-le à l’aide d’un élastique ou de tout autre dispositif.
- Placez le boitier en face de votre appareil photo, en le rehaussant éventuellement, afin que la LED d’illumination de l’appareil soit bien en face du capteur. La LED du Baby Shutter Tester a un cône d’éclairage de 20°. Il est nécessaire pour réaliser les mesures que le capteur soit situé dans ce cône d’éclairage. Evitez de projeter le faisceau lumineux en direction des yeux.
- Allumez le baby Shutter Tester. Le boitier affiche "Ready" et la LED d'éclairage est allumée
- Pour vous assurer que le boitier du Baby Shutter Tester et son capteur sont bien positionnés, utilisez le mode Test (voir chapitre suivant). Pour effectuer des mesures précises aux vitesses élevées (1/250e de seconde et plus rapide), disposez votre ensemble de façon fixe et effectuez au préalable la calibration du testeur.
- Sélectionnez la vitesse que vous voulez mesurer sur votre appareil photo.
- Déclenchez l’obturateur. Durant la phase d'ouverture de l'obturateur, le Baby Shutter Tester affiche un soleil pour indiquer qu'il détecte de la lumière. Cette phase peut être très brève, en fonction de la vitesse choisie sur l'appareil photo.
- Une fois l'obturateur refermé, la valeur de vitesse mesurée est affichée sur l'écran
- Comparez la valeur mesurée avec la valeur choisie sur le sélecteur de vitesse de votre appareil photo
- Pour effectuer une nouvelle mesure, appuyez sur le bouton de réinitialisation.
S’il est utilisé de façon rigoureuse, le Baby Shutter Tester peut effectuer des mesures allant de plusieurs secondes au 4000e de seconde avec une précision de l’ordre de quelques microsecondes.

## Les différents modes de fonctionnement

Le mode de fonctionnement initial du Baby Shutter Tester, est le mode "Mesure", avec lequel on effectue les mesures de vitesse.
Mais l'appareil possède également d'autres modes de fonctionnement, qui permettent de faciliter le positionnement, la calibration, ou d'afficher des informations. Un appui long ou court sur le bouton de l'appareil permet de naviguer d'un mode à l'autre.


Figure 2 : Modes de fonctionnement et transitions d'un mode à l'autre

Mode Mesure

Ce mode permet d'effectuer les mesures de vitesse de votre appareil photo (voir mode opératoire plus haut).

Mode Test

Ce mode vous permet de positionner correctement le capteur à l'arrière de l'appareil photo, et obtenir la meilleure précision de mesure.
Pour obtenir une mesure fiable au vitesses élevées (1/250e et plus rapide), un positionnement optimal de la LED du boitier par rapport au capteur est indispensable. C’est le processus de calibration.

Pour que la calibration et les mesures soient fiables, il est nécessaire de procéder en lumière tamisée, c’est-à-dire dans des conditions où la lumière ambiante touchant le capteur est faible par rapport à celle en provenance de la LED.

Après avoir positionné le capteur à l’arrière de l’appareil, correctement centré, placé la LED du boitier en face, sélectionnez une vitesse lente ou la pause B sur votre appareil photo et déclenchez.

Figure 3: affichages du mode Test

Dans le mode Test, tant que le capteur ne détecte pas la lumière de la LED, un cercle est affiché sur la gauche de l’écran (affichage 1).
Lorsque le capteur détecte la LED, un soleil est affiché à la place du cercle.
- Si la LED est trop proche du capteur, une flèche vers la droite est affichée au centre de l’écran, ainsi qu’un nombre négatif (affichage 2).
- Si la LED est trop éloignée du capteur, une flèche vers la gauche est affichée au centre de l’écran, ainsi qu’un nombre positif (affichage 3).
- Si la LED est positionnée à la bonne distance, un point est affiché au centre de l’écran, ainsi qu’un nombre entre -10 et 10 (affichage 4).
Le dernier affichage d’indication de distance persiste 2 secondes après que l’appareil ait cessé de détecter la LED. Ceci permet de faciliter la calibration même si l‘appareil photo ne dispose ni de vitesse lente ni de pause B.

Si l’objectif de votre appareil photo est démontable, la calibration sera plus aisée lorsqu’il est retiré. Si l’objectif n’est pas démontable, ou si l’objet de la mesure est un obturateur central situé dans l’objectif, la procédure est facilitée lorsque le diaphragme est réglé à pleine ouverture et la mise au point à l’infini.
Une fois votre ensemble correctement positionné, retournez en mode mesure et effectuez les mesures de vitesse exactement dans les mêmes conditions que la calibration.
Un mauvais positionnement de la LED par rapport au capteur peut entrainer une erreur de mesure allant jusqu’à 1 diaphragme pour une vitesse au 1000e de seconde.

Mode Info

Dans ce mode, l'écran affiche des informations sur l'appareil, et notamment le numéro de version de son microcode.
Spécificité de mesure selon le type d’obturateur.

On distingue principalement deux types d’obturateur :
- Les obturateurs plan focal (à rideaux)
- Les obturateurs centraux
Le Baby Shutter Tester donne une indication de vitesse d’obturateur. Dans certaines conditions, cette simple valeur n’est cependant pas suffisante à elle seule pour déterminer l’exposition.

Obturateur plan focal

L’obturateur plan focal met en œuvre deux rideaux qui se déplacent successivement, dans le même sens. L’ouverture de l’un est suivie par la fermeture de l’autre. Si les deux rideaux se déplacent à la même vitesse sur toute la surface, l’exposition est uniforme et est donnée par la mesure du Baby Shutter Tester.
Si les deux rideaux se déplacent à des vitesses différentes, cela donne des différences d’exposition selon les parties de la photo. Il est difficile pour un appareil à un seul capteur tel que le Baby Shutter Tester d’évaluer ce type de phénomène.
Si cela vous est nécessaire, tournez-vous vers un appareil à plusieurs capteurs tel que le Shutter Lover, du même fabricant.

Obturateur central

L'obturateur central a pour caractéristique de fonctionner en trois phases : l'ouverture, la pleine ouverture, et la fermeture.
Lorsque la pleine ouverture dure longtemps par rapport aux phases d'ouverture et de fermeture, tout va bien, la vitesse mesurée correspond à l'exposition qu'aura la pellicule. Lorsque ce n'est plus le cas (pour les très hautes vitesses, mais également si la vitesse de déplacement des lamelles de l'obturateur est trop lente), vous pouvez avoir un écart entre la vitesse mesurée et l'exposition effective qu'aura la pellicule, puisque la phase intermédiaire pendant laquelle l'obturateur n'est ni complètement ouvert ni complètement fermé n’est pas négligeable.
Cela a pour conséquence une mesure de vitesse au centre optique qui est sous-estimée avec le Baby Shutter Tester. A la vitesse maximale d’un obturateur central, une sous-estimation de la vitesse jusqu’à un diaphragme est chose courante. Il ne faut donc pas s’inquiéter dans un tel cas. Si vous placez le capteur au plus proche de l'obturateur (coté objectif, donc), vous pouvez faire des mesures au centre et des mesures en périphérie. La différence de temps mesuré vous donnera le temps mis par les lamelles pour s'ouvrir et se fermer

## Limitation de garantie

Le Baby Shutter Tester a été conçu et fabriqué avec le plus grand soin, toutefois, son fabricant décline toute responsabilité sur les conséquences de son utilisation.

Toute garantie expresse ou implicite, y compris, mais sans s’y limiter, les garanties implicites de qualité marchande et d’adéquation à un usage particulier, est rejetée. En aucun cas le fabricant ne peut être tenu pour responsable des dommages directs, indirects, accessoires, spéciaux, exemplaires ou consécutifs (y compris mais sans s’y limiter, la perte d’utilisation ou de bénéfices, ou l'interruption des activités), quelle qu’en soit la cause, résultant de quelque manière que ce soit de l’utilisation de cet équipement, même s’il a été informé de la possibilité de tels dommages.

## Fabrication

Ce produit a été conçu et fabriqué en France. Son assemblage est fait selon un processus artisanal. Le boitier est imprimé à l'unité sur une imprimante 3D avec une matière première biosourcée et

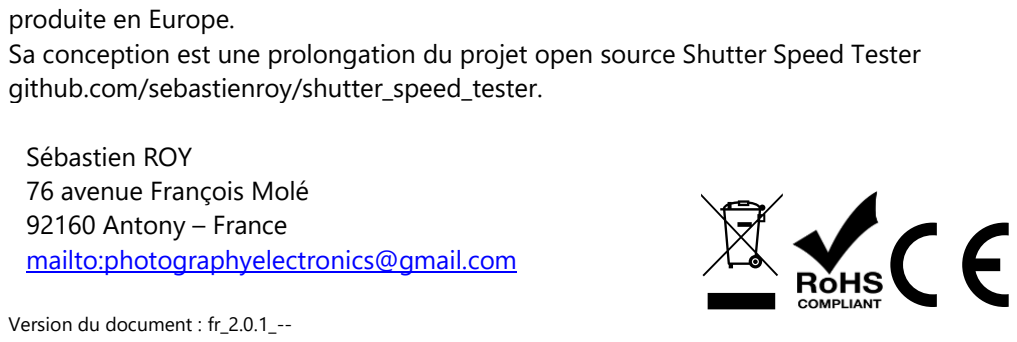
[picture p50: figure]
produite en Europe.; github.com/sebastienroy/shutter_speed_tester.; Sébastien ROY 76 avenue François Molé 92160 Antony – France mailto:photographyelectronics@gmail.com; Version du document : fr_2.0.1_--

Sa conception est une prolongation du projet open source Shutter Speed Tester

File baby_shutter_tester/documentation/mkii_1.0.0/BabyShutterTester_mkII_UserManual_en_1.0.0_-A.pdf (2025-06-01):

# Baby Shutter Tester mark II

# User manual

## 1. Introduction

The Baby Shutter Tester Mark II is a tool for measuring the shutter speed of film cameras.
Its compact and lightweight design, battery-powered operation, and calibration-free operation make it ideal for testing cameras before purchase at fairs or flea markets.
Its excellent accuracy also makes it a very good workshop tool for testing cameras and determining whether or not they require servicing.

This tester was designed in accordance with the recommendations of the international standard ISO-516-2019. As such, it offers professional-level measurement accuracy. It has also been designed to be easy to use, allowing it to be used without any specific technical knowledge.

To get the most out of it, however, it is recommended to read this manual carefully.

## 2. Presentation

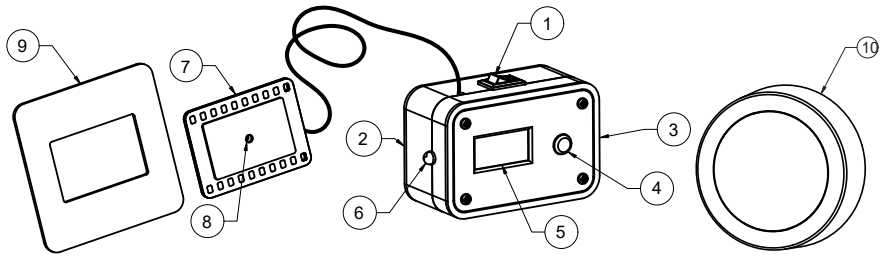
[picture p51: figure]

Figure 1 : Presentation

1. On/Off switch
2. LR03/AAA battery compartment
3. Micro USB port
4. Reset and mode selection button
5. Display screen
6. Lighting LED
7. Sensor support
8. Light sensitive sensor
9. Removable 6x6 medium format adapter
10. Light source with diffuser (optional)

The device can be powered either by a micro-USB cable or by two LR03 (AAA) batteries.
When the battery voltage is too low, a low battery indicator ( ) is displayed on the screen and the device cannot be operated.
The light source with diffuser (optional) is USB powered.

Remove the batteries when not using the device for an extended period.
The Baby Shutter Tester should be kept away from moisture and heat sources. It is designed to operate within a temperature range of 5 to 40°C.

## 3. Setup: quick inspection of a focal plane shutter camera (SLR or rangefinder type)

- Open the back of your camera.
- Place the sensor on the back of the camera, in place of the film.
Remove the lens from the camera body.
- Place the tester's LED opposite the camera mount, pointing towards the sensor.
- Turn on the tester.
- Trigger the camera.
- The tester will then display the measured shutter speed.
- The measured value is updated with each new shutter release.

Handheld, the camera is capable of producing extremely reliable results from 1/15s to 1/1000s using this procedure, without requiring any calibration.

To obtain reliable results for other use cases (central shutter, slow shutter speeds, etc.), refer to the detailed description in this manual.

## 4. Measurement Modes

The Baby Shutter Tester has two operating modes: automatic mode and global mode.
- Automatic mode should be used for handheld tests between 1/15s and 1/1000s
- with the built-in LED for focal plane shutters,
- and with the light source with diffuser for central shutters.
- Global mode has no limits on the speeds to be measured,
- with the light source with diffuser
- from the slowest speed to the fastest speed.
- With identical lighting from one measurement to the next See below for further explanations of these two measurement modes

## 5. Display description and results interpretation

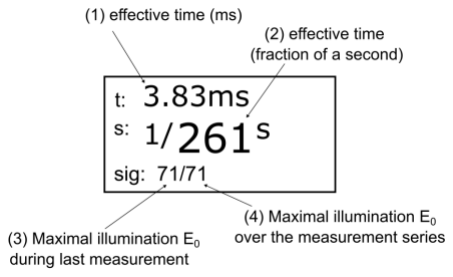
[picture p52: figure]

Figure 2: display of the measurement result

After each measurement, the Baby Shutter Tester displays the following:
1) The effective time te, expressed in milliseconds
2) The effective time te, expressed in fractions of a second
3) The maximum illumination value E0 during the last measurement
4) The maximum illumination value E0 over the measurement series (global mode), or "Auto" (automatic mode)

The effective time value, expressed in fractions of a second, should be compared to the shutter speed selected on the camera, for example, 1/250s.
It is important to be aware of the tolerance on these values. The standard tolerance on shutter speed values for new cameras was around 30%. Thus, for a selected shutter speed of 1/250 seconds, the permissible shutter speed values are between 1/187 seconds and 1/350 seconds. This high tolerance should be considered compared with the exposure tolerance of film, for which a 30% increase or decrease in exposure generally has little impact.

The E0 value, the maximum illumination value, is a unitless value that can vary between 0 and 100 depending on lighting conditions. A value above 90 indicates a value close to saturation. It is necessary to decrease the illumination (move the light source away from the sensor) to maintain reliable measurements.
A value below 10 indicates low illumination. This has the effect of reducing the signal-to-noise ratio, and therefore decreasing the reliability of the measurement.
If, for strictly identical lighting conditions, the E0 value decreases for the highest speeds, this indicates that the operating situation illustrated in Figure 5 is present. To maintain reliable measurements, it is necessary to switch to global measurement mode.

## 6. Operating principle of shutters and tester

### 6.1. Shutters

### 6.1.1. Two families of shutters

There are two types of shutters: front shutters and focal plane shutters.

- A focal plane shutter is a shutter located near the camera's focal plane. Focal plane shutters are found on almost all 35mm SLR and 35mm rangefinder cameras, as well as a number of medium format cameras. Focal plane shutters have the characteristic of illuminating the image incrementally.
- A front shutter (also called a central shutter or leaf shutter) is a shutter located near or inside the lens. Front shutters have the characteristic of illuminating the entire image simultaneously. Front shutters are found on large format cameras, a large number of medium format cameras (folding, twin-lens, Hasselblad, etc.), but also on many small format cameras with fixed lenses. The reliable measurement of central shutters is only possible with a light source with a diffuser (see below).

### 6.1.2. Perfect Shutter

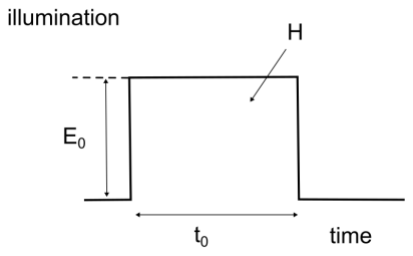
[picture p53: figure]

Figure 3 : Illustration of a perfect shutter

The function of a shutter is to limit the exposure of an image to light over time.
Exposure H (the total amount of light received by a point in the image) is the product of the light intensity E0 and the open time t0.

H = t0 × E0
Conversely,
t0 = H
E0

⁄

Shutter speed is expressed in units of time: the second. To compare this value with camera speed markings, this time is also expressed as a fraction of a second (e.g., 1/125s = 0.008s).

### 6.1.3. Real shutter

The operation of a perfect shutter is represented in Figure 3. It is either fully closed or fully open.

The real operation of a shutter involves a transition between the fully open position and the fully closed position, the proportion of which can be significant, especially at high speeds.

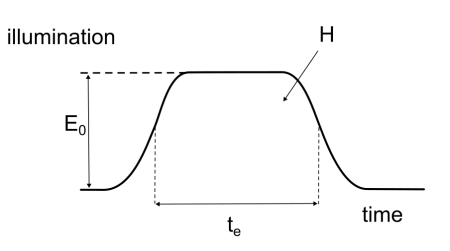
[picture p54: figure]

Figure 4: Operation of a Real Shutter

The effective time te is then defined by: te = H
E0

⁄

Since the Baby Shutter Tester is capable of measuring E0 and H, it deduces the effective time te using the previous formula.

### 6.1.4. Degraded case

In the very degraded case, which can be encountered at high speeds, the light intensity measured at a point in the image may begin to decrease before reaching the maximum E0.

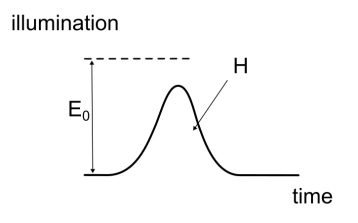
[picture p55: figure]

Figure 5: Extreme case of shutter operation

In this case, the E0 value cannot be determined directly. However, it can be deduced from previous measurements, taken under the same conditions but at a lower speed.
When this case is encountered with a central shutter, it indicates a malfunction (it does not open to its maximum at high speeds).
With a focal plane shutter, this does not indicate a malfunction. This effect is due to the progressive illumination of the sensor's sensitive surface.

### 6.2. Baby Shutter Tester Measurement Modes

The Baby Shutter Tester has two measurement modes: automatic mode and global mode.

### 6.2.1. Automatic Mode

In automatic mode, the default operating mode, in addition to measuring exposure H, the tester determines E0 as the maximum illumination during a measurement.
This allows the tester to determine the effective time in the ideal case shown in Figure 3, or the actual time shown in Figure 4.
For a reliable measurement, the illumination must be constant throughout the measurement.

### 6.2.2. Global Mode

To also handle the extreme case shown in Figure 5, the device needs to memorize the maximum illumination E0 from previous measurements.
This is achieved using global mode. In this mode, the maximum illumination E0 value is retained from one measurement to the next. By performing speed measurements from the slowest to the fastest, it allows the effective time to be correctly determined, even for speeds above 1/1000s.
The E0 value is reset after a short press of the camera's reset/mode button.
Restrictions:
- The lighting must be strictly identical from one measurement to the next. Specifically, this can be achieved by placing the light source with diffuser on the camera mount or lens. Using the built-in LED is not recommended for this mode.
- The aperture value must not be changed from one measurement to the next.
- Some point and shoot cameras have an automatic aperture adjustment that cannot be disengaged. Global mode should not be used for these cameras.

For reliable measurement results in global mode, it is essential that the light is constant during the measurement, as well as from one measurement to the next.
To switch from automatic mode to global mode, and vice versa, press and hold (> 2 seconds) the reset/mode button.

## 7. Light Sources

To take measurements, the device can use either its built-in LED or a light source with a diffuser (optional).
The light sources supplied with the device have been specifically designed for their stability and suitability for the sensor's sensitivity. The reliability of measurement results cannot be guaranteed with any other light source.

### 7.1. Built-in LED

The ISO-516-2019 standard recommends to use a light source with diffuser.
However, experience shows that, in the case of focal plane shutters, for speeds ranging from 15s to 1/1000s, measurements made with the LED give values very close to those made with the light source with a diffuser.
Place the LED as close as possible to the mount, pointing toward the sensor.
Note that the high sensitivity of the sensor allows measurements to be taken even when the LED is far away. However, this leads to a degradation of the measurement signal-to-noise ratio.

### 7.2. Light source with diffuser (optional)

The light source with diffuser should be placed against the lens or on the camera mount. This ensures an optimal signal-to-noise ratio and high illumination stability. This last point is particularly critical when using global mode or for measuring slow shutter speeds.

The light source with diffuser is recommended in the following cases:
- Cameras with a central shutter
- Slow shutter speeds
- Using global mode

## 8. Measurement accuracy

Measurement accuracy is limited by two categories of errors:
- Experimental errors
- Equipment errors

Experimental errors are all phenomena not caused by the device: lighting fluctuations, electromagnetic interference, incorrect sensor positioning, etc.

Experimental errors depend solely on the user.
The equipment error is estimated to be less than 1% + 10 microseconds.

Note that its operating principle does not require calibration.

The validity of this device's measurements has been verified using two different methods:
- The graphical method described in the ISO-516-2019 standard
- Measurements carried out on a shutter model whose speed is known with certainty.

## 9. Recommendations for use

The table below provides a summary of the tester's usage recommendations.

Use case | Light source | Measurement mode
Quick handheld testing of a SLR or other focal plane shutter camera | Built-in LED | Automatic
Quick testing of a central shutter camera | Light Source with Diffuser | Automatic
Complete workshop testing | Light Source with Diffuser | Global

## 10.Limitation of warranty

The Baby Shutter Tester has been designed and manufactured with care. However, the manufacturer declines all responsibility for the consequences of its use.

All warranties, express or implied, including, but not limited to, implied warranties of merchantability and fitness for a particular purpose, are disclaimed. In no event shall the manufacturer be liable for any direct, indirect, incidental, special, exemplary or consequential damages (including, but not limited to, loss of use or profits, or business interruption), however caused, arising in any way out of the use of this equipment, even if advised of the possibility of such damages.

## 11.Manufacture

This product has been designed and manufactured in France. Its assembly is made according to an artisanal process. The case is printed individually on a 3D printer with a bio sourced raw material

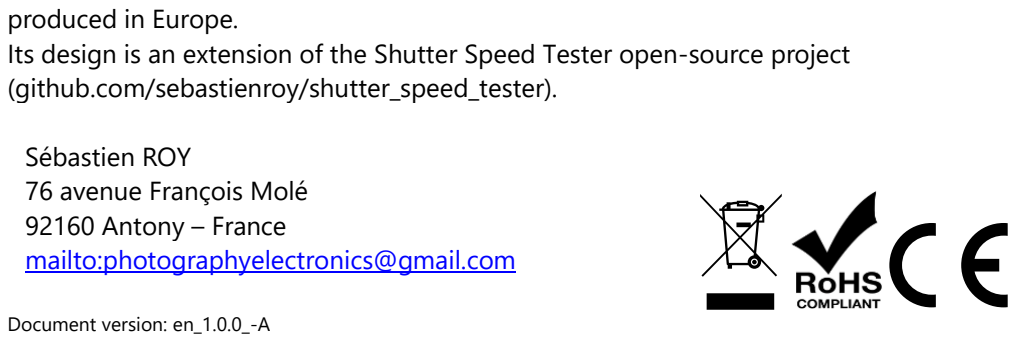
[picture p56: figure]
produced in Europe.; (github.com/sebastienroy/shutter_speed_tester).; Sébastien ROY 76 avenue François Molé 92160 Antony – France mailto:photographyelectronics@gmail.com; Document version: en_1.0.0_-A

Its design is an extension of the Shutter Speed Tester open-source project

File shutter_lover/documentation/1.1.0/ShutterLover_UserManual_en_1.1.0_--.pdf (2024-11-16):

# Shutter Lover - User Manual

The Shutter Lover is a device intended to measure the shutter speed of film cameras, and in particular to measure the travel time of the curtains of focal plane shutters.

It is particularly adapted for 35mm film cameras (24x36mm frame). An adapter allows to use it also on medium format cameras.

## Presentation

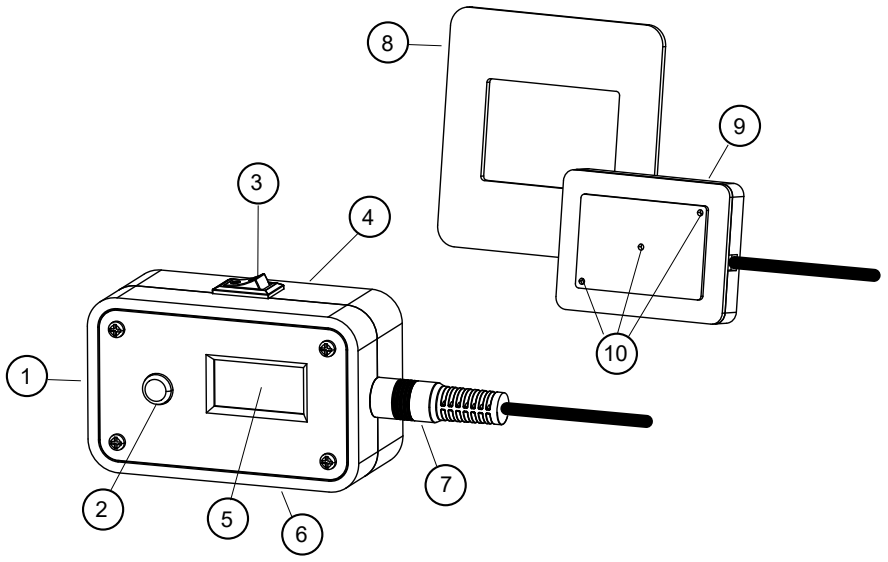
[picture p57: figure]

1. Micro-USB port
2. Reset and mode selection button
3. On/Off switch
4. Lighting LEDs
5. Display screen
6. Base for tripod mounting
7. Sensor connector
8. Sensor adapter for medium format camera
9. Sensor
10. Sensor measurement points

## Setup

To turn on the unit, plug the sensor into the sensor socket, connect the USB cable to the Shutter Lover on one end and to a power source on the other (computer or AC adapter) and switch On the power switch.

The Shutter Lover should be kept away from moisture and heat sources.
It is designed to operate in a temperature range of 5 to 40°C.

## Measurement Operation

- Place the sensor on the back of the camera, in place of the film A relief on the sensor allows to position it precisely in the frame of the 24x36 cameras. A medium format adapter allows to place it on this camera format as well.
Use a rubber band or other mean to hold the sensor in place.
- Remove the lens from the camera
- Plug in and turn on the Shutter Lover. The display will show "Ready" and its light LEDs will light up. Avoid directing the light from the LEDs towards your eyes.
- Place the Shutter Lover case in front of the camera mount, parallel to it and centered vertically and horizontally. Adjust the distance between the Shutter Lover and the sensor to match the calibration distance (see below). It is recommended to use a tripod for the camera and the Shutter Lover to facilitate control of their relative positioning.
- To ensure that the Shutter Lover is correctly positioned, you can use the Test mode of the camera (see Test Mode section).
- Select the shutter speed you want to check on your camera.
- Release the shutter.
- The Shutter Lover screen then displays the summary results of the measurement. The display is split in two parts:
- The upper part displays the travel time of the first curtain ("Open" (1)) and the second curtain ("Close" (2)) between the two measurement points located on the diagonal of the sensor.
- The lower part displays the shutter speed on the first diagonal sensor point that detects the opening (3), the central point (4) and the last diagonal sensor point (5).
- If the measurement on one or more of the points of the sensor could not be carried out, (incorrect positioning of the sensor, or malfunction of the shutter), partial results are displayed after a delay of 2 seconds.
- If the Shutter Lover is connected to a computer and the remote application is launched (see paragraph Remote Application), you can also get the detailed measurement results and transfer them in your favourite application.
- To start a new measure, briefly press the reset button.

## The Different Operating Modes

The initial operating mode of the Shutter Lover is the "Measurement" mode.
But the device also has other operating modes, that can be used to facilitate positioning or to display information. A long or short press on the device button allows you to navigate from one mode to another.

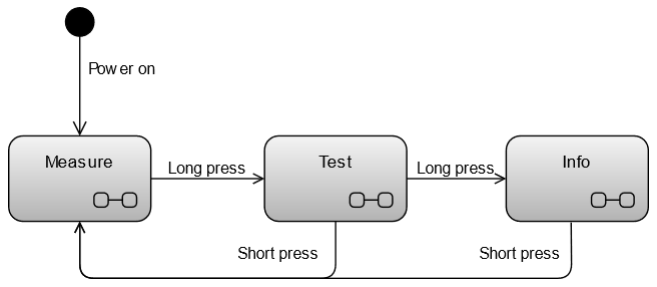
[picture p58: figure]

Figure 2: Operating modes and transitions.

Measurement Mode

This mode is used to make measurements. See paragraph ”Measurement operation”

Test Mode

This mode ensures that the sensor is correctly positioned on the camera.

In this mode, the screen displays a representation of each of the sensor's measurement points and indicates which of them are illuminated.

Position the sensor on the back of the camera, position the Shutter Lover's housing in front of it, centered, at its calibration distance and fire the shutter at slow shutter speed or pause B. When the sensor is correctly positioned, the 3 measurement points are illuminated. You can then proceed with your measurements.

Information Mode

In this mode, the display shows information about the device: firmware version number and factory calibration values.

## Operating principles

Many cameras, including most SLRs in 24x36 format, feature a focal-plane shutter.
This type of shutter consists of two curtains that move in front of the focal plane (the film plane). Both curtains move in the same direction. The first curtain opens, the second closes. If the travel speed of the two curtains is not identical, this leads to exposure variations from one side of the exposed surface to the other, particularly visible at high speeds, where the distance between the edge of the two curtains is low.
In their maintenance manuals, manufacturers recommend setting the curtain travel speed to precise values. The role of the Shutter Lover is to measure this speed for control and maintenance purposes.
The Shutter Lover uses a sensor with 3 measuring points. One is located at the center, the two others in opposite corners of a 32mm x 20mm rectangle (2mm from the edges in 24x36 format). This diagonal positioning makes it possible to measure both horizontally and vertically moving curtains. When facing the camera, the sensor should be positioned instead of the film, with the cable on the right.
The Shutter Lover's casing features 3 LEDs that illuminate each of the sensor's measurement points, preventing parallax errors.
The Shutter Lover takes the time of the illuminated/unilluminated transitions at each measurement point, and so can deduce the shutter speeds and times at each point, and also the curtains travel times between points.

## Measurement accuracy and factory calibration

Due to physical phenomena linked to the size of the sensor, measured speeds vary slightly with light intensity, and therefore with LED-to-sensor distance. A factory calibration is carried out to determine the optimum distance between the LEDs on the casing and the sensor.
This optimal distance, specific to your model, is noted in the documentation supplied. As the used components are stable, there is no need to recalibrate the device over time.

## Remote application

A remote application enables you to collect, display and archive on a personal computer the detailed results of measurements taken with the Shutter Lover.
This application is Open-Source, as are its interface specifications. So, you can adapt it to your own needs.
For installation and use, please refer to the following web address: http://github.com/sebastienroy/shutter_lover_remote_app

## Limitation of warranty

The Shutter Lover has been designed and manufactured with care, in order to perform measurements with the best reliability. The device comes with a 2-year manufacturer's warranty. However, the manufacturer declines all responsibility for the consequences of its use.

All warranties, express or implied, including, but not limited to, implied warranties of merchantability and fitness for a particular purpose, are disclaimed. In no event shall the manufacturer be liable for any direct, indirect, incidental, special, exemplary or consequential damages (including, but not limited to, loss of use or profits, or business interruption), however caused and on any theory of liability, arising in any way out of the use of this equipment, even if advised of the possibility of such damages.

## Manufacture

This product has been designed and manufactured in France.
The plastic material of the casing is bio-sourced and produced in Europe.
Its assembly, including the soldering of its components, is carried out according to an artisanal process. Each unit is calibrated individually

Sébastien ROY
76 avenue François Molé
92160 Antony – France
mailto:photographyelectronics@gmail.com

Document version: en_1.1.0_--

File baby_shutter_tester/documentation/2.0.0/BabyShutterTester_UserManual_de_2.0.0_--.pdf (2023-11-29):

# Baby Shutter Tester - Gebrauchsanweisung

Der Baby Shutter Tester ist ein Gerät zur Messung der Verschlusszeit von analogen Kameras.

## Übersicht

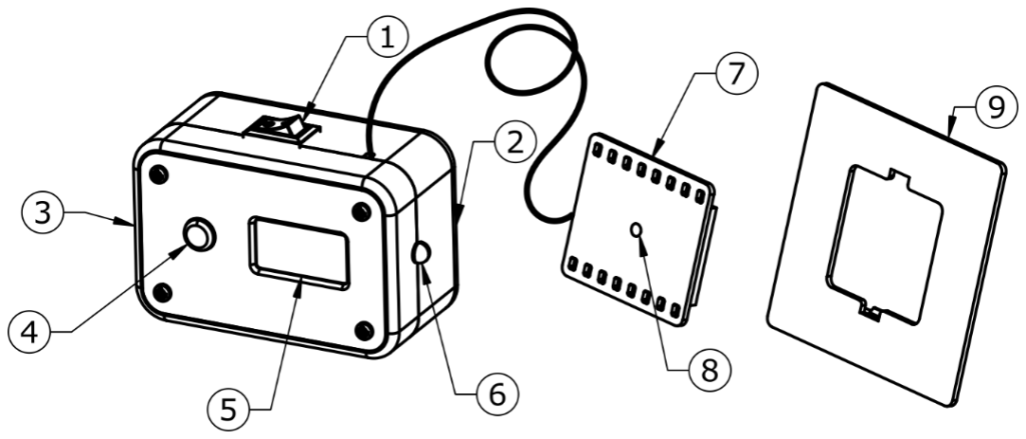
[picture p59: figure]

Abbildung 1 : Übersicht

1. Ein/Aus-Schalter
2. Batteriefach für LR03/AAA-Batterien
3. Mikro-USB-Anschluss
4. Taste zum Zurücksetzen und Aufheben der Modusauswahl
5. Display
6. LED-Beleuchtung
7. Sensorhalterung
8. Lichtempfindlicher Sensor
9. Mittelformatadapter

## Inbetriebnahme

Die Kamera kann entweder über ein Mikro-USB-Kabel oder über zwei LR03-Batterien (AAA) mit Strom versorgt werden.
Wenn die Kamera über den USB-Anschluss mit Strom versorgt wird, ist der Ein/Aus-Schalter nicht funktionsfähig.
Wenn die im Betrieb von den Batterien gelieferte Spannung zu niedrig ist, wird auf dem Bildschirm eine Anzeige für schwache Batterien ( ) angezeigt. Wechseln Sie die Batterien aus, um einen unregelmäßigen Betrieb zu vermeiden.
Es ist notwendig, die Batterien zu entfernen.
- Wenn Sie die Kamera über einen längeren Zeitraum nicht benutzen.
- Wenn Sie das Gerät an den USB-Anschluss anschließen.

Der Baby Shutter Tester sollte vor Feuchtigkeit und Wärmequellen geschützt werden. Er ist für den Betrieb in einem Temperaturbereich von 5 bis 40 °C vorgesehen.

## Funktionsweise

- Öffnen Sie die Rückseite Ihrer Kamera.
- Legen Sie den Sensor anstelle des Films auf die Rückseite der Kamera, wobei der Fototransistor zum Verschluss der Kamera zeigt. Bei Mittelformatkameras verwenden Sie den mitgelieferten Adapter. Achten Sie darauf, dass der Sensor zentriert ist, und fixieren Sie ihn mit einem Gummiband oder einer anderen Vorrichtung.

- Platzieren Sie das Gehäuse vor Ihrer Kamera, eventuell mit einer Erhöhung, damit die Beleuchtungs-LED der Kamera auf den Sensor gerichtet ist. Die LED des Baby Shutter Testers hat einen Beleuchtungskegel von 20°. Für die Durchführung der Messungen ist es notwendig, dass sich der Sensor innerhalb dieses Beleuchtungskegels befindet. Vermeiden Sie es, den Lichtstrahl in Richtung der Augen zu richten.
- Schalten Sie den Baby Shutter Tester ein. Das Display zeigt "Ready" an und die Beleuchtungs-LED leuchtet.
- Um sicherzustellen, dass das Gehäuse des Baby Shutter Testers und sein Sensor richtig positioniert sind, verwenden Sie den Testmodus (siehe nächstes Kapitel). Um präzise Messungen bei hohen Verschluss-Geschwindigkeiten (1/250 Sekunde und schneller) durchzuführen, stellen Sie Ihr Set auf ein festes Gestell und führen Sie vorher die Kalibrierung des Testers durch.
- Wählen Sie die Verschluss-Geschwindigkeit, die Sie messen möchten, auf Ihrer Kamera aus.
- Lösen Sie den Verschluss aus. Während der Öffnungsphase des Verschlusses zeigt der Baby Shutter Tester eine Sonne an, um anzuzeigen, dass er Licht erkennt. Diese Phase kann je nach der an der Kamera gewählten Verschlusszeit sehr kurz sein.
- Nachdem der Verschluss geschlossen wurde, wird der gemessene Geschwindigkeitswert auf dem Bildschirm angezeigt.
- Vergleichen Sie den gemessenen Wert mit dem am Geschwindigkeitswahlrad Ihrer Kamera gewählten Wert.
- Um eine neue Messung vorzunehmen, drücken Sie die Reset-Taste.
Bei exakter Anwendung kann der Baby Shutter Tester Messungen von mehreren Sekunden bis zu 1/4000 Sekunde mit einer Zuverlässigkeit im Bereich von Mikrosekunden durchführen.

## Die verschiedenen Betriebsarten

Der ursprüngliche Betriebsmodus des Baby Shutter Testers, ist der "Messmodus", mit dem die Geschwindigkeitsmessungen durchgeführt werden.
Das Gerät verfügt aber auch über andere Betriebsmodi, die die Positionierung und Kalibrierung erleichtern oder Informationen anzeigen. Durch langes oder kurzes Drücken der Taste am Gerät kann zwischen den einzelnen Modi gewechselt werden.


Abbildung 2 : Betriebsmodi und Wechsel von einem Modus in den anderen

Messungsmodus

In diesem Modus können Sie die Geschwindigkeit Ihrer Kamera messen (siehe Funktionsweise weiter oben).

Testmodus

In diesem Modus können Sie den Sensor auf der Rückseite der Kamera richtig positionieren und die höchste Messgenauigkeit erzielen.
Um eine zuverlässige Messung bei hohen Geschwindigkeiten (1/250 und schneller) zu erhalten, ist eine optimale Positionierung der LED des Gehäuses in Bezug auf den Sensor unerlässlich. Dies ist der Prozess der Kalibrierung.
Damit die Kalibrierung und die Messungen zuverlässig sind, müssen Sie bei gedämpftem Licht arbeiten, d. h. unter Bedingungen, bei denen das Umgebungslicht, das auf den Sensor trifft, im Vergleich zu dem Licht, das von der LED kommt, gering ist.

Nachdem Sie den Sensor auf der Rückseite der Kamera korrekt zentriert und die LED des Gehäuses vor sich platziert haben, wählen Sie eine langsame Geschwindigkeit oder Pause B an Ihrer Kamera

Abbildung 3 : Anzeigen im Testmodus

Im Testmodus wird, solange der Sensor das Licht der LED nicht erkennt, auf der linken Seite des Bildschirms ein Kreis angezeigt (Anzeige 1).
Wenn der Sensor die LED erkennt, wird anstelle des Kreises eine Sonne angezeigt.
- Wenn sich die LED zu nah am Sensor befindet, wird in der Mitte des Bildschirms ein Rechtspfeil sowie eine negative Zahl angezeigt (Anzeige 2).
- Wenn die LED zu weit vom Sensor entfernt ist, wird in der Mitte des Bildschirms ein Pfeil nach links sowie eine positive Zahl angezeigt (Anzeige 3).
- Wenn die LED im richtigen Abstand positioniert ist, wird in der Mitte des Bildschirms ein Punkt sowie eine Zahl zwischen -10 und 10 angezeigt (Anzeige 4).
Die letzte Entfernungsanzeige bleibt 2 Sekunden lang bestehen, nachdem die Kamera die LED nicht mehr erkennt. Dies erleichtert die Kalibrierung, auch wenn die Kamera weder den Langsamfahrmodus noch den B-Modus hat.

Wenn das Objektiv Ihrer Kamera abnehmbar ist, ist die Kalibrierung einfacher, wenn das Objektiv entfernt wird.
Wenn das Objektiv nicht abnehmbar ist oder das Messobjekt ein Zentralverschluss ist, der sich im Objektiv befindet, wird das Verfahren erleichtert, wenn die Blende auf volle Öffnung und der Fokus auf Unendlich eingestellt ist.
Wenn Ihre Baugruppe richtig positioniert ist, kehren Sie in den Messmodus zurück und führen Sie die Geschwindigkeitsmessungen unter exakt denselben Bedingungen wie die Kalibrierung durch.
Eine falsche Positionierung der LED in Bezug auf den Sensor kann bei einer Geschwindigkeit von 1000stel Sekunden zu einem Messfehler von bis zu 1 Blende führen.

Info-Modus

In diesem Modus zeigt der Bildschirm Informationen über die Kamera an, einschließlich der Versionsnummer der Firmware.

## Durchführung der Messung je nach Verschlusstyp

Es werden hauptsächlich zwei Arten von Verschlüssen unterschieden:

- Die Schlitzverschlüsse (Vorhangverschlüsse).
- Die Zentralverschlüsse (centeral shutters).
Der Baby Shutter Tester zeigt einen Wert für die Verschlussgeschwindigkeit. Unter bestimmten Bedingungen ist dieser Wert allein jedoch nicht ausreichend genau, um die Belichtung zu bestimmen.

Schlitzverschluss

Beim Schlitzverschluss kommen zwei Vorhänge zum Einsatz, die sich nacheinander in die gleiche Richtung bewegen. Auf das Öffnen des einen folgt das Schließen des anderen. Wenn sich beide Vorhänge mit der gleichen Geschwindigkeit über die gesamte Fläche bewegen, ist die Belichtung gleichmäßig und wird durch die Messung des Baby Shutter Testers genau angezeigt.
Wenn sich die beiden Vorhänge mit unterschiedlichen Geschwindigkeiten bewegen, führt dies zu unterschiedlichen Belichtungen in den verschiedenen Teilen des Fotos. Für eine Kamera mit nur einem Sensor wie den Baby Shutter Tester ist es schwierig, ein solches Phänomen zu beurteilen. Wenn es für Sie notwendig ist, wenden Sie sich an ein Gerät mit mehreren Sensoren wie den Shutter Lover desselben Herstellers.

Zentralverschluss

Der Zentralverschluss hat die Eigenschaft, dass er in drei Phasen arbeitet: Öffnen, volle Öffnung und Schließen.
Wenn die volle Öffnung im Verhältnis zu den Öffnungs- und Schließphasen lange dauert, ist alles in Ordnung, und die gemessene Geschwindigkeit entspricht der Belichtung, die der Film haben wird. Wenn dies nicht mehr der Fall ist (bei sehr hohen Geschwindigkeiten, aber auch wenn sich die Verschlusslamellen zu langsam bewegen), kann es zu einer Abweichung zwischen der gemessenen Geschwindigkeit und der tatsächlichen Belichtung des Films kommen, da die Zwischenphase, in der der Verschluss weder ganz offen noch ganz geschlossen ist, nicht zu vernachlässigen ist.
Dies hat zur Folge, dass die Geschwindigkeitsmessung im optischen Zentrum mit dem Baby Shutter Tester unterschätzt wird. Bei der maximalen Geschwindigkeit eines Zentralverschlusses ist eine Unterschätzung der Geschwindigkeit um bis zu einer Blende üblich. In einem solchen Fall sollte man sich also keine Sorgen machen. Wenn Sie den Sensor so nah wie möglich am Verschluss platzieren (also auf der Seite des Objektivs), können Sie Messungen in der Mitte und am Rand durchführen. Die gemessene Zeitdifferenz gibt Ihnen die Zeit an, die die Lamellen zum Öffnen und

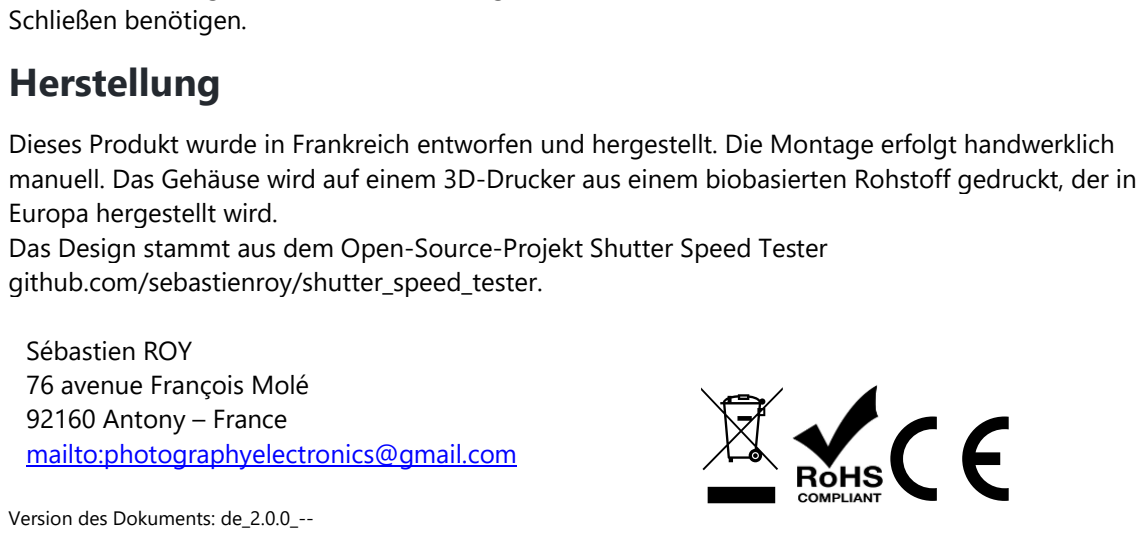
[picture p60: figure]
Schließen benötigen.; Herstellung; Europa hergestellt wird.; github.com/sebastienroy/shutter_speed_tester.; Sébastien ROY 76 avenue François Molé 92160 Antony – France mailto:photographyelectronics@gmail.com; Version des Dokuments: de_2.0.0_--

Dieses Produkt wurde in Frankreich entworfen und hergestellt. Die Montage erfolgt handwerklich manuell. Das Gehäuse wird auf einem 3D-Drucker aus einem biobasierten Rohstoff gedruckt, der in

Das Design stammt aus dem Open-Source-Projekt Shutter Speed Tester

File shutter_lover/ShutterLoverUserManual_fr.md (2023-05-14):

# Shutter Lover - Mode d'emploi

[Manuel Français- Shutter Lover - pdf](documentation/ShutterLover_Manual_fr.pdf)

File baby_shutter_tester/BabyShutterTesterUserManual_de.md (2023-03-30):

# Baby Shutter Tester – User Manual  

[Baby Shutter Tester Manual, German version - pdf](documentation/BabyShutterTester_Manual_de.pdf)

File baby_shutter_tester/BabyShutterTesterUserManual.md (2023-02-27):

# Baby Shutter Tester - Mode d'emploi

[Manuel Français- Baby Shutter Tester - pdf](documentation/BabyShutterTester_Manual_fr.pdf)

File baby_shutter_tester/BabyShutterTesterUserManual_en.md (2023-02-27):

# Baby Shutter Tester – User Manual  

[Baby Shuter Tester Manual, English version - pdf](documentation/BabyShutterTester_Manual_en.pdf)

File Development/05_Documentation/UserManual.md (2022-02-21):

# Shutter Speed Tester User Manual

# English

- [ ] Todo

# French

## Référence
Le Shutter Speed Tester est le produit d’un projet open source. Tous les détails de son fonctionnement, ses plans, sa fabrication, etc, sont disponibles sur le site web suivant :  
http://github.com/sebastienroy/shutter_speed_tester
## Licence
Le code de Shutter Speed Tester est distribué sous licence GPL3. Cette licence vous permet de copier, modifier, distribuer son code, à condition que ces copies soient distribuées sous la même licence.  
Pour plus de détails :  
https://www.gnu.org/licenses/gpl-3.0.fr.html

## Mise en service
Le Shutter Speed Tester est constitué d'une boitier principal et d'un capteur relié par un fil.  
- Le boitier principal comporte 
  - un interrupteur on/off
  - un bouton poussoir
  - une LED de contrôle
  - un écran d'affichage
  - une LED d'éclairage (sur le côté)
  - un port MINI USB (sur le desssus)
  - une trappe à pile 9V (à l'arrière)
- Le capteur est constitué
  - du capteur de lumière, sur un support 35mm
  - d'un adaptateur amovible moyen format 6x6  

L'appareil  peut être alimenté électriquement soit par un cable MINI USB, soit par une pile 9V.  
Cette dernière se met en place à l'arrière de l'appareil, en ouvrant la trappe en plastique et en connectant la pile 9V sur le connecteur prévu à cet effet.  

Il est nécessaire d'enlever la pile
- lorsque vous n'utilisez pas l'appareil pendant une durée prolongée
- lorsque vous connectez l'appareil sur le port USB

## Mode opératoire
-	placez le capteur à l'arrière de l'appareil photo, à la place de la pellicule. Selon le format de votre appareil photo, utilisez ou enlevez l'adaptateur moyen format.
-	placez le boitier en face de l'appareil photo à la bonne hauteur pour être en face du capteur
-	allumez l'appareil. La LED d'éclairage de l'appareil s'allume
-	déclenchez. La LED de control (verte) s'allume durant le temps où l'obturateur est ouvert. L'appareil indique ensuite la vitesse mesurée.
-	pour recommencer la mesure, appuyez sur le bouton sur la façade de l'appareil.
## Spécificité de mesure selon le type d’obturateur.
On distingue principalement deux types d’obturateur : 
-	Les obturateurs centraux
-	Les obturateurs plan focal (à rideaux)  

Le Shutter Speed Tester donne une indication de vitesse d’obturateur sur un mode tout ou rien, mesuré à l’emplacement du capteur. Ce fonctionnement très simple est suffisant pour couvrir la majorité du besoin de mesure, pour lequel l’exposition est le produit de la vitesse et de l’ouverture.  
Il existe toutefois certains cas où cette simple valeur n’est pas suffisante pour déterminer l’exposition.
### Obturateur plan focal
L’obturateur plan focal met en œuvre deux rideaux qui se déplacent successivement, dans le même sens. L’ouverture de l’un est suivie par la fermeture de l’autre.
Si les deux rideaux se déplacent à la même vitesse sur toute la surface, l’exposition est uniforme et est donnée par la mesure du Shutter Speed Tester.  
Si les deux rideaux se déplacent à des vitesses différentes, cela donne des différences d’exposition selon les parties de la photo. Pour détecter cela, positionnez le capteur à différentes positions à l’arrière de l’appareil photo pour faire vos mesures et vérifiez que les valeurs de mesures sont identiques quel que soit l’emplacement du capteur.
### Obturateur central
L'obturateur central a pour caractéristique de fonctionner en trois phases : l'ouverture, la pleine ouverture, et la fermeture.  
Lorsque la pleine ouverture dure longtemps par rapport aux phases d'ouverture et de fermeture, tout va bien.  
Lorsque ce n'est plus le cas (pour les très hautes vitesses, en pratique uniquement pour la vitesse la plus rapide de l'obturateur), vous pouvez avoir un écart entre la durée d'ouverture mesurée et l'exposition de la pellicule, puisqu'il est impossible de dire à partir de quel seuil le "chronomètre" va être mis en marche. Ce dernier fonctionne en mode "tout ou rien".  
Il existe toutefois une façon d'estimer le phénomène : Si vous placez le capteur au plus proche de l'obturateur (coté objectif, donc), vous pouvez faire des mesures au centre et des mesures en périphérie. La différence de valeur mesurée vous donnera la vitesse d'ouverture et de fermeture de l'obturateur

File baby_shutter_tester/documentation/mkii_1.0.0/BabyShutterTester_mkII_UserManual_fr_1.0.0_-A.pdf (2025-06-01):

# Baby Shutter Tester mark II

# Manuel utilisateur

## 1. Introduction

Le Baby Shutter Tester mark II est un outil de mesure de la vitesse d'obturation des appareils photographiques argentiques.
Sa conception compacte et légère, son autonomie grâce à l’alimentation par piles, son fonctionnement ne nécessitant pas de calibration, en font l’outil idéal pour tester des appareils photos avant achat sur des foires ou des brocantes.
Son excellente précision en fait également un très bon outil d’atelier pour tester le bon fonctionnement d’appareil photos et déterminer s’ils nécessitent ou non une révision.

Ce testeur été conçu conformément aux préconisations du standard international ISO-516-2019. Il offre à ce titre une précision de mesure de niveau professionnel. Il a également été conçu afin d'offrir une facilité d'utilisation permettant sa mise en œuvre sans connaissance technique particulière.

Afin d'en tirer le meilleur parti, il est toutefois conseillé de faire une lecture attentive de ce manuel.

## 2. Présentation

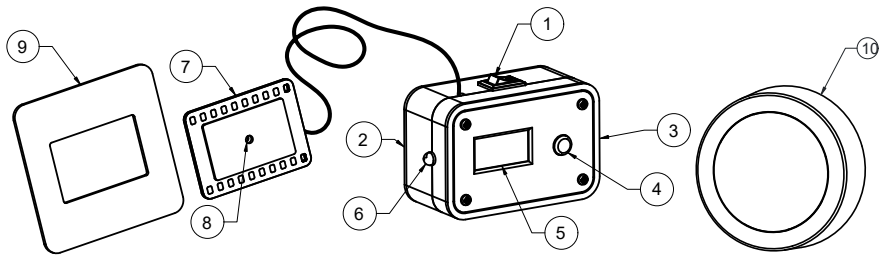
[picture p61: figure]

Figure 1 : Présentation

1. Interrupteur On/Off
2. Trappe à pile LR03/AAA
3. Port micro USB
4. Bouton de réinitialisation et de sélection de mode
5. Ecran d'affichage
6. LED d'éclairage
7. Support du capteur
8. Capteur photosensible
9. Adaptateur moyen format
10. Source de lumière avec diffuseur (optionnel)

L'appareil peut être alimenté soit par un câble micro USB, soit par deux piles LR03 (AAA). Lorsque la tension délivrée par les piles est trop basse, une indication de batterie faible ( ) est affichée sur l’écran.
La source de lumière avec diffuseur (optionnelle) est alimentée par USB.

Enlevez les piles lorsque vous n'utilisez pas l'appareil pendant une durée prolongée.
Le Baby Shutter Tester doit être maintenu à l’abri de l’humidité et des sources de chaleur. Il est prévu pour fonctionner sur une plage de température de 5 à 40°C.

## 3. Mise en service : inspection rapide d’un appareil photo à obturateur plan focal (type reflex ou télémétrique)

- Ouvrez le dos de votre appareil photo.
- Placez le capteur à l’arrière de l’appareil photo, à la place de la pellicule.
- Enlevez l'objectif du boitier.
- Placez la LED du testeur en face de la monture de l'appareil photo, dirigée vers le capteur.
- Allumez le testeur.
- Déclenchez l'appareil photo.
- Le testeur indique alors la vitesse mesurée.
- La valeur mesurée est mise à jour à chaque nouveau déclenchement.

A main levée, l'appareil est capable de donner selon cette procédure, et sans nécessiter aucune calibration, des résultats extrêmement fiables du 1/15s au 1/1000s

Pour obtenir des résultats fiables pour les autres cas d'utilisation (obturateur central, vitesses lentes, etc.) se référer à la description détaillée de ce manuel.

## 4. Modes de mesure

Le Baby Shutter Tester a deux modes de fonctionnement : le mode automatique et le mode global.
- Le mode automatique doit être utilisé pour des tests à main levé entre 1/15s et 1/1000s
- avec la LED intégrée pour les obturateurs plan focal,
- et avec la source de lumière avec diffuseur pour les obturateurs centraux.
- Le mode global n’a pas de limitation sur les vitesses à mesurer,
- avec la source de lumière avec diffuseur
- de la vitesse la plus lente à la vitesse la plus rapide.
- Avec un éclairage identique d’une mesure à l’autre Voir plus loin pour de plus amples explications sur ces deux modes de mesure

## 5. Description de l’affichage et interprétation des résultats

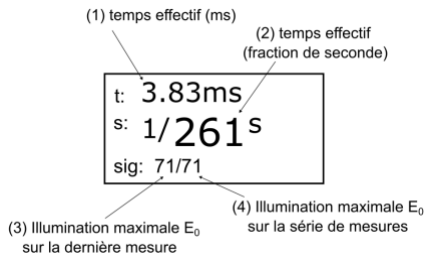
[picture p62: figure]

Figure 2: affichage du résultat de mesure

Après chaque mesure, le Baby Shutter Tester affiche les éléments suivants :
1) Le temps effectif te, exprimé en milliseconde
2) Le temps effectif te, exprimé en fraction de seconde
3) La valeur maximale de l’illumination E0 lors de la dernière mesure
4) La valeur maximale de l’illumination E0 sur la série de mesure (mode global), ou « Auto » (mode automatique)

La valeur du temps effectif, exprimé en fraction de seconde, est à comparer à la vitesse sélectionnée sur l’appareil photo, par exemple le 250e de seconde.
Il est important d’avoir conscience de la tolérance sur ces valeurs. La tolérance sur les valeurs de vitesse pour les appareils neufs était de l’ordre de 30%. Ainsi, pour une vitesse sélectionnée de 1/250e

, les valeurs admissibles de vitesse sont comprises entre 1/187e et 1/350e de seconde. Cette tolérance importante est à mettre en regard de la tolérance d’exposition des pellicules, pour lesquelles 30% d’exposition en plus ou en moins a généralement peu d’impact.

La valeur de E0, valeur maximale de l’illumination, est une valeur sans unité, pouvant varier entre 0 et 100 suivant les conditions d’illumination. Une valeur supérieure à 90 indique une valeur proche de la saturation. Il est nécessaire de diminuer l’illumination (éloigner la source de lumière du capteur) pour garder des mesures fiables.
Une valeur inférieure à 10 indique une faible illumination. Cela a pour effet de diminuer le rapport signal sur bruit, et donc de diminuer la fiabilité de la mesure.
Si, pour des conditions d’éclairage strictement identiques, la valeur E0 diminue pour les vitesses les plus élevées, cela indique que l’on se trouve dans le cas de fonctionnement illustré par la Figure 5. Pour garder des mesures fiables, il faut passer en mode de mesure global.

## 6. Principe de fonctionnement des obturateurs et du testeur

### 6.1. Obturateurs

### 6.1.1. Deux familles d’obturateurs

Il existe deux familles d’obturateurs : les obturateurs frontaux et les obturateurs plan focal.

- Un obturateur plan focal est un obturateur situé à proximité du plan focal de l'appareil photo. Les obturateurs plan focal équipent la quasi-totalité des appareils reflex 24x36, télémétriques 24x36, mais également un certain nombre d'appareils moyen format. Les obturateurs plan focal ont pour caractéristique d’illuminer l’image de façon incrémentale.
- Un obturateur frontal (appelé aussi obturateur central) est un obturateur situé à proximité ou à l'intérieur de l'objectif. Les obturateurs centraux ont pour caractéristique d’illuminer simultanément l’ensemble de l’image. Les obturateurs centraux sont rencontrés sur les grand format, une bonne partie des appareils moyen formats (folding, bi-objectifs, Hasselblad, ...), mais également sur beaucoup de petits formats à objectif fixe. Leur fonctionnement implique que la mesure fiable des obturateurs centraux est uniquement possible avec une source de lumière avec diffuseur (voir plus loin).

### 6.1.2. Obturateur parfait

Figure 3 : Illustration d’un obturateur parfait

La fonction d'un obturateur est de limiter dans le temps l'exposition d'une image à la lumière.

L'exposition H (la quantité totale de lumière reçue par un point de l'image) est le produit de l'intensité lumineuse E0 et du temps d'ouverture t0.
H = t0 × E0
Réciproquement,
t0 = H
E0

⁄

La vitesse d'un obturateur est exprimée en unité de temps : la seconde. Pour pouvoir comparer cette valeur avec le marquage de vitesse des appareils photo, ce temps est également exprimé en fraction de seconde (par exemple 1/125s = 0.008s)

### 6.1.3. Obturateur réel

Le fonctionnement d'un obturateur idéal est représenté par la Figure 3. Il est soit totalement fermé, soit totalement ouvert.

Le fonctionnement réel d'un obturateur comporte une transition entre la position totalement ouverte et la position totalement fermée, dont la part peut être non négligeable, surtout aux vitesses élevées.

Figure 4 : fonctionnement d’un obturateur réel

On définit alors le temps effectif te par : te = H
E0

⁄

Le Baby Shutter Tester étant capable de mesurer E0 et H, il en déduit le temps effectif te par la formule précédente.

### 6.1.4. Cas dégradé

Dans le cas très dégradé, que l'on peut rencontrer sur les hautes vitesses, l'intensité lumineuse mesurée en un point de l'image peut commencer à décroitre avant d'avoir atteint le maximum E0.

Figure 5 : cas extrême du fonctionnement d’un obturateur

Dans ce cas, la valeur E0 ne peut être déterminée directement. Elle peut cependant être déduite des mesures précédentes, prises dans les mêmes conditions mais à vitesse plus faible.
Lorsque ce cas est rencontré sur un obturateur central, cela indique un dysfonctionnement de celui-ci (il ne s’ouvre pas au maximum aux hautes vitesses).
Sur un obturateur plan focal, cela n’exprime pas un dysfonctionnement. Cet effet est dû à l’illumination progressive de la surface sensible du capteur.

### 6.2. Modes de mesure du Baby Shutter Tester

Le Baby Shutter Tester a deux modes de mesure : le mode automatique et le mode global.

### 6.2.1. Mode automatique

En mode automatique, mode de fonctionnement par défaut, en plus de mesurer l’exposition H, le testeur détermine E0 comme l’illumination maximale au cours d’une mesure.
Cela permet au testeur de déterminer le temps effectif dans le cas idéal de la Figure 3, ou réel de la Figure 4.
Pour que la mesure soit fiable il faut que l’éclairage soit constant tout au long de la mesure.

### 6.2.2. Mode global

Afin de pouvoir gérer également le cas extrême de la Figure 5, l'appareil a besoin de mémoriser l'illumination maximale E0 à partir des mesures précédentes.
Ceci est permis par le mode global. Dans ce mode, la valeur de l'illumination maximale E0 est conservée d'une mesure à l'autre. En effectuant les mesures de vitesse de la plus lente à la plus rapide, elle permet de déterminer correctement le temps effectif, même pour les vitesses supérieures au 1/1000s.
La mémorisation de E0 est réinitialisée suite à un appui court sur bouton reset/mode de l'appareil. Restrictions :
- L'éclairage doit être strictement identique d'une mesure à l'autre. Concrètement, cela peut être réalisé en plaquant la source de lumière avec diffuseur sur la monture ou sur l'objectif de l'appareil photo. L'utilisation de la LED intégrée n'est pas recommandée pour ce mode.
- La valeur du diaphragme ne doit pas être modifiée d'une mesure à l'autre.
- Certains appareil photos "point and shoot" comportent un réglage automatique du diaphragme qui ne peut être débrayé. Le mode global ne doit pas être utilisé pour ces appareils.

Pour que les résultats de mesure soient fiables en mode global, il est indispensable que l’éclairage soit stable pendant la mesure, mais également d'une mesure à l'autre.
Pour passer du mode automatique au mode global, et inversement, effectuez un appui long (> 2 secondes) sur le bouton reset/mode.

## 7. Sources de lumière

Pour faire les mesures, l'appareil peut utiliser soit sa LED intégrée, soit une source de lumière avec diffuseur (optionnelle).
Les sources de lumière fournies avec l'appareil ont été spécifiquement étudiées pour leur stabilité et leur adéquation avec la sensibilité du capteur. La fiabilité des résultats de mesure ne peut être garantie avec toute autre source de lumière.

### 7.1. LED intégrée

La norme ISO-516-2019 préconise d'utilise une source de lumière diffuse.
Toutefois, l'expérience montre que, dans le cas des obturateurs plan focal, pour des vitesses allant du 15s jusqu'à 1/1000s, les mesures effectuées avec la LED donnent des valeurs très proches des celles effectuées avec la source de lumière avec diffuseur.
Placez la LED au plus proche de la monture, dirigée vers le capteur.
Notez que la forte sensibilité du capteur permet d'effectuer des mesures même en éloignant la LED. Cela conduit cependant à dégrader le rapport signal sur bruit de la mesure.

### 7.2. Source de lumière avec diffuseur (optionnelle)

La source de lumière avec diffuseur doit être placée contre l'objectif ou sur la monture de l'appareil. Cela permet d'avoir un rapport signal sur bruit optimal et une grande stabilité de l'éclairage. Ce dernier point est particulièrement critique pour l'utilisation du mode global ou pour la mesure des vitesses lentes.

La source de lumière avec diffuseur est préconisée dans les cas suivants :
- Appareil à obturateur central
- Vitesses lentes
- Utilisation du mode global

## 8. Précision des mesures

La précision de mesure est limitée par deux catégories d’erreurs:
- Les erreurs d’expérimentation
- Les erreurs d’appareillage

Les erreurs d’expérimentation sont tous les phénomènes qui ne sont pas dus à l’appareil : fluctuation de l’éclairage, pertubations électromagnétiques, mauvais positionnement du capteur, etc.

Les erreurs d’expérimentation dépendent uniquement de l’utilisateur.
L’erreur d’appareillage est estimée inférieure à 1% + 10 microsecondes.

Notez que son principe de fonctionnement ne nécessite pas de calibration.

La validité des mesures de cet appareil a été vérifiée à partir de deux méthodes différentes :
- La méthode graphique décrite dans le standard ISO-516-2019
- Mesures effectuées sur un modèle d’obturateur dont la vitesse est connue avec certitude.

## 9. Préconisations d’utilisation

Le tableau ci-dessous présente un résumé des préconisations d'utilisation du testeur.

Cas d’utilisation | Source de lumière | Mode de mesure
Test rapide à main levée d'un reflex ou autre appareil à obturateur plan focal | LED intégrée | Automatique
Test rapide d'un appareil à obturateur central | Source de lumière avec diffuseur | Automatique
Tests complets en atelier | Source de lumière avec diffuseur | Global

## 10.Limitation de garantie

Le Baby Shutter Tester a été conçu et fabriqué avec le plus grand soin, toutefois, son fabricant décline toute responsabilité sur les conséquences de son utilisation.

Toute garantie expresse ou implicite, y compris, mais sans s’y limiter, les garanties implicites de qualité marchande et d’adéquation à un usage particulier, est rejetée. En aucun cas le fabricant ne peut être tenu pour responsable des dommages directs, indirects, accessoires, spéciaux, exemplaires ou consécutifs (y compris mais sans s’y limiter, la perte d’utilisation ou de bénéfices, ou l'interruption des activités), quelle qu’en soit la cause, résultant de quelque manière que ce soit de l’utilisation de cet équipement, même s’il a été informé de la possibilité de tels dommages.

## 11.Fabrication

Ce produit a été conçu et fabriqué en France. Son assemblage est fait selon un processus artisanal. Le boitier est imprimé à l'unité sur une imprimante 3D avec une matière première biosourcée et

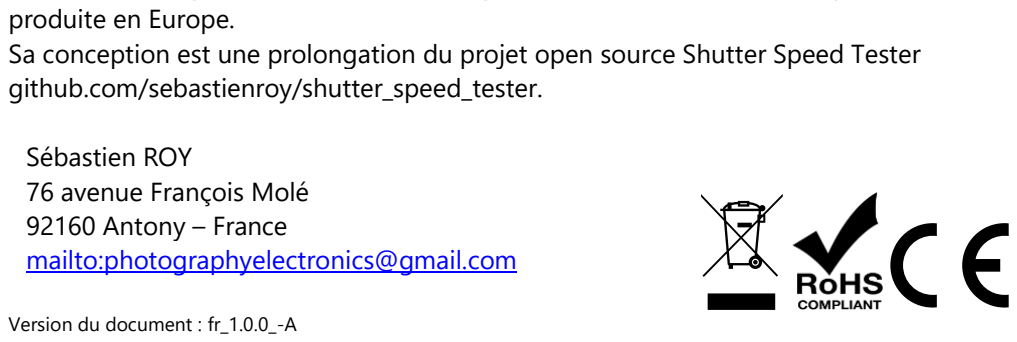
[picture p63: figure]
produite en Europe.; github.com/sebastienroy/shutter_speed_tester.; Sébastien ROY 76 avenue François Molé 92160 Antony – France mailto:photographyelectronics@gmail.com; Version du document : fr_1.0.0_-A

Sa conception est une prolongation du projet open source Shutter Speed Tester

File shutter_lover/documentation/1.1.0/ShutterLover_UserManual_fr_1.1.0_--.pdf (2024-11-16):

# Shutter Lover - Mode d'emploi

Le Shutter Lover est un appareil destiné à mesurer la vitesse d'obturation des appareils photographiques argentiques, et en particulier de mesurer la vitesse de translation des rideaux des obturateurs plan focal.
Il est particulièrement adapté aux appareils de format 24x36. Un adaptateur permet de l'utiliser également sur les appareils moyen format.

## Descriptif

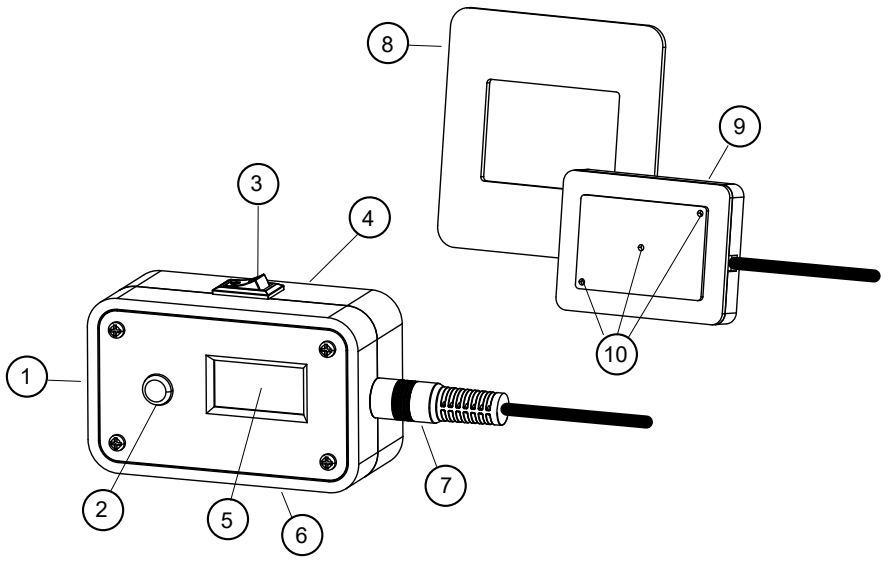
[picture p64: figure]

1. Port micro-USB
2. Bouton de réinitialisation
3. Interrupteur On/Off
4. LEDs d'illumination
5. Ecran d'affichage
6. Embase pour fixation sur pied
7. Connecteur du capteur
8. Adaptateur capteur pour le moyen format
9. Capteur
10. Points de mesure du capteur

## Mise en service

Pour mettre en route l'appareil, connectez le capteur sur sa prise, branchez le câble USB sur le Shutter Lover d'un côté et sur une source d'alimentation électrique de l'autre (ordinateur ou adaptateur secteur) et positionnez l'interrupteur sur "I".
Le Shutter Lover doit être maintenu à l'abri de l'humidité et des sources de chaleur.
Il est prévu pour fonctionner sur une plage de température de 5 à 40°C.

## Mode opératoire

- Ouvrez le dos de votre appareil photo et positionnez le capteur du Shutter Lover à l'arrière de l'appareil photo, à la place de la pellicule. Un relief sur le capteur permet de le positionner précisément dans le cadre des appareil 24x36. Un adaptateur moyen format permet de le positionner également sur ce format d'appareil photo.
Utilisez un élastique ou tout autre dispositif pour maintenir le capteur en place.
- Retirez l'objectif de l'appareil photo
- Branchez et allumez le Shutter Lover. L'écran affiche "Ready" et ses LED d'éclairage s'allument. Evitez de projeter le faisceau lumineux des LEDs en direction des yeux.
- Positionnez le boitier du Shutter Lover en face de la monture de l'appareil photo, parallèle à celle-ci et centrée verticalement et horizontalement. Ajustez la distance entre le Shutter Lover et le capteur pour qu'elle corresponde à la distance de calibration (voir plus loin). Il est recommandé de fixer l'appareil photo et le Shutter Lover sur trépied afin de maitriser plus facilement leur positionnement relatif.
- Pour vous assurer du bon positionnement du Shutter Lover, vous pouvez utiliser le mode Test de l'appareil (voir paragraphe Mode Test).
- Sélectionnez sur votre appareil photo la vitesse que vous voulez vérifier.
- Déclenchez l'obturateur.
- L'écran du Shutter Lover affiche alors le résultat synthétique de la mesure. Cet affichage est séparé en deux parties.
- La partie supérieure affiche les temps de translation du premier rideau ("Open" (1)) et du deuxième rideau ("Close" (2)) entre les deux points de mesure situés sur la diagonale du capteur.
- La partie inférieure affiche les vitesses d'obturation sur le premier capteur diagonal détectant l’ouverture (3), le point central (4) et le dernier capteur diagonal (5).
- Si la mesure sur l'un ou l'autre des points du capteur n'a pu être effectuée (mauvais positionnement du boitier du Shutter Lover par rapport à son capteur ou disfonctionnement de l'obturateur), des résultats partiels sont affichés au bout d'un délai de 2 secondes.
- Si le Shutter Lover est branché sur un ordinateur et que l'application distante est lancée (voir paragraphe Application distante), celle-ci permet d'acquérir les données détaillées de la mesure et de les archiver.
- Pour recommencer la mesure, pressez brièvement le bouton de réinitialisation.

## Les différents modes de fonctionnement

Le mode de fonctionnement initial du Shutter Lover est le mode "mesure", avec lequel l'appareil effectue les mesures de vitesse.
Mais l'appareil possède également d'autres modes de fonctionnement, qui permettent de faciliter le positionnement ou d'afficher des informations. Un appui long ou court sur le bouton permet de naviguer d'un mode à l'autre.

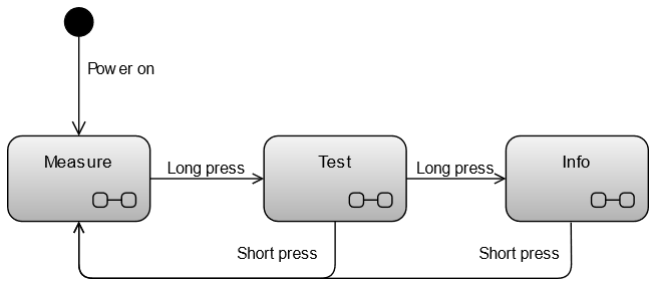
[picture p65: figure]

Figure 2 : modes de fonctionnement et transitions.

Mode Mesure

Ce mode permet d’effectuer les mesures de vitesse de votre appareil photo. Voir paragraphe « Mode opératoire »

Mode Test

Ce mode permet de s’assurer que le capteur est correctement positionné sur l’appareil photo. Dans ce mode, l’écran affiche une représentation de chacun des points de mesure du capteur et indique lesquels d’entre eux sont illuminés.
Positionnez le capteur à l’arrière de l’appareil photo, positionnez le boitier du Shutter Lover en face, centré, à sa distance de calibration et déclenchez en vitesse lente ou en pause B. Lorsque le capteur est correctement positionné, les 3 points de mesure sont illuminés. Vous pouvez alors procéder à vos mesures.

Mode Info

Dans ce mode, l’écran affiche des informations sur l’appareil : le numéro de version du firmware ainsi que des valeurs relatives à sa calibration usine.

## Principes de fonctionnement

De nombreux appareils photographiques, dont la plupart des reflex au format 24x36, disposent d’un obturateur plan focal.
Ce type d’obturateur est constitué de deux rideaux qui se déplacent devant le plan focal (le plan du film). Les deux rideaux se déplacent dans le même sens. Le premier rideau est ouvrant, le deuxième est fermant. Si la vitesse de translation des deux rideaux n’est pas identique, cela conduit à des variations d’exposition d’un coté à l’autre de la surface exposée, visibles en particulier aux hautes vitesses.
Les constructeurs préconisent, dans leurs manuels de maintenance, de régler la vitesse de translation des rideaux à des valeurs précises. Le rôle du Shutter Lover est de mesurer cette vitesse de translation afin d’en faire le contrôle et la maintenance.
Le Shutter Lover utilise un capteur comportant 3 points de mesure. L’un est situé au centre, les deux autres sont situés dans les coins opposés d’un rectangle de côté 32mm x 20mm (à 2mm des bords du format 24x36). Ce positionnement sur la diagonale permet aussi bien de mesurer les rideaux se déplaçant horizontalement que verticalement. Lorsque l’on fait face à l’appareil photo, le capteur doit être positionné à l’emplacement de la pellicule, avec le câble à droite.
Le boitier du Shutter Lover comporte 3 LEDS qui permettent d’éclairer chacun des points de mesure du capteur et d’éviter les erreurs de parallaxe.

Le Shutter Lover chronomètre les temps auxquels s’effectuent les transitions illuminé / non illuminé de chacun des points de mesure, en déduit les temps et vitesse d’obturation en chacun de ces points et également les durées de déplacement des rideaux entre les différents points.

## Précision des mesures et calibration usine

En raison de phénomènes physiques liés à la taille du capteur, les vitesses mesurées varient légèrement en fonction de l’intensité lumineuse, et donc en fonction de la distance LED – capteur. Une calibration usine est faite afin de déterminer la distance optimale entre les LEDS du boitier et le capteur.
Cette distance optimale, spécifique à votre exemplaire, est notée dans la documentation fournie. Les composants utilisés étant stables, il n’est pas nécessaire de recalibrer l’appareil au cours du temps.

## Application distante

Une application distante permet de collecter, afficher et archiver sur un ordinateur personnel les résultats détaillés des mesures effectuées avec le Shutter Lover.
Cette application est en Open-Source, ainsi que ses spécifications d’interface. Vous avez donc la possibilité de l’adapter vous-même à vos besoins.
Pour son installation et son utilisation, reportez-vous à l’adresse web suivante : http://github.com/sebastienroy/shutter_lover_remote_app

## Limitation de garantie

Le Shutter Lover a été conçu et fabriqué avec le plus grand soin, afin de s’acquitter au mieux de la tâche pour laquelle il a été conçu. L’appareil bénéficie d’une garantie constructeur de 2 ans. Toutefois, son fabricant décline toute responsabilité sur les conséquences de son utilisation.

Toute garantie expresse ou implicite, y compris, mais sans s’y limiter, les garanties implicites de qualité marchande et d’adéquation à un usage particulier, est rejetée. En aucun cas le fabricant ne peut être tenu pour responsable des dommages directs, indirects, accessoires, spéciaux, exemplaires ou consécutifs (y compris mais sans s’y limiter, la perte d’utilisation ou de bénéfices, ou l'interruption des activités), quelle qu’en soit la cause et quelle que soit la théorie de la responsabilité, résultant de quelque manière que ce soit de l’utilisation de cet équipement, même s’il a été informé de la possibilité de tels dommages.

## Fabrication

Ce produit a été conçu et fabriqué en France.
Le plastique de son boitier est biosourcé et produit en Europe.
Son assemblage, y compris la soudure de ses composants, est fait selon un processus artisanal.

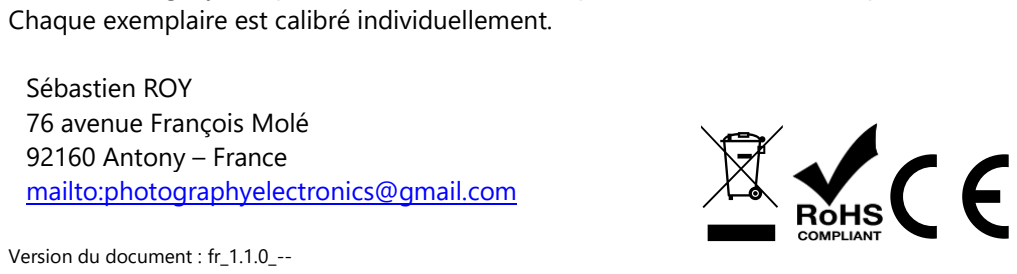
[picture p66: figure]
Chaque exemplaire est calibré individuellement.; Sébastien ROY 76 avenue François Molé 92160 Antony – France mailto:photographyelectronics@gmail.com; Version du document : fr_1.1.0_--

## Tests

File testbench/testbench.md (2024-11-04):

# Test Bench

In order to improve the reproducibility and the precision of the measure, it is recommended to use a test bench for measuring speeds above 1/250s.  

Here is a description of a suitable test bench

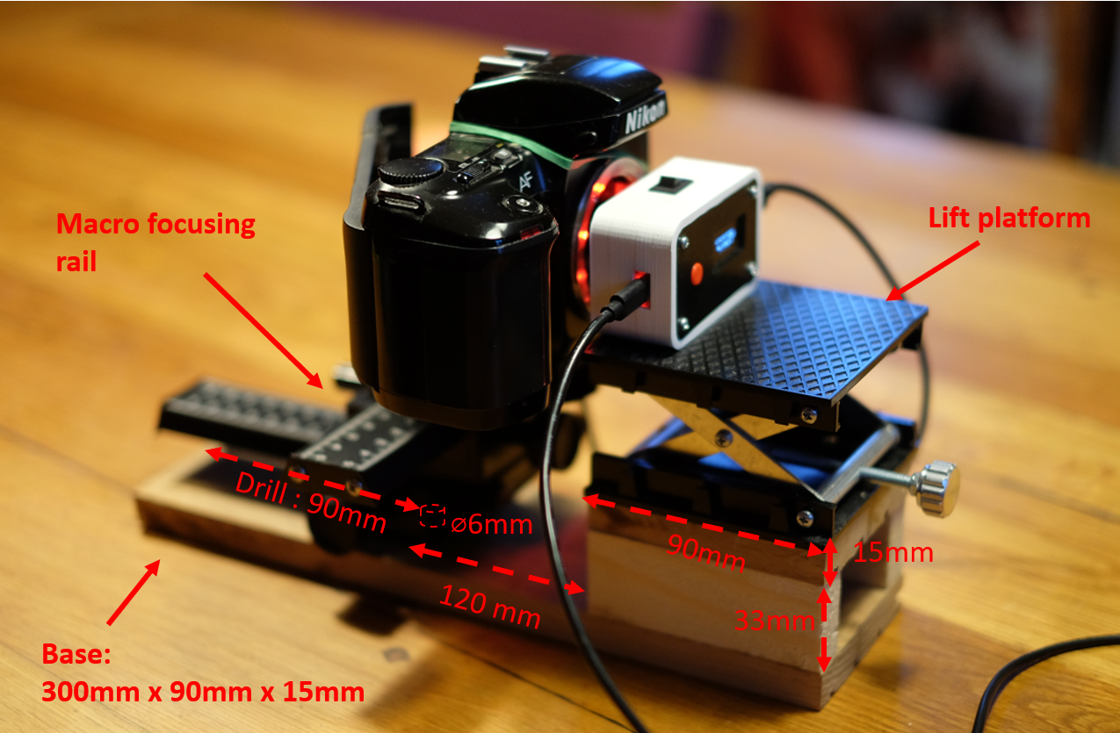
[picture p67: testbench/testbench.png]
Test bench


To build this bench you will need the following:
- A macro focusing rail (like [this one](https://aliexpress.com/item/1005001804948944.html) )  
- A lift platform (such as [this one](https://aliexpress.com/item/1005002895053253.html) )
- 2 1/4" Kodak camera screws (like [this](https://www.aliexpress.com/item/1005005803164258.html))
- Some pieces of 15mm thick wood
- Some wood screws
- A driller
- wood glue

_The dimensions above are those of the described bench. Of course it is not the only way to build a test bench._

The base of the bench is a board 30cm long and 9cm large.  
At one side, there is a kind of "bridge" that allows to raise the lift platform, and is high enough (33mm) to put on the rail to pass.  
The lift platform is screwed on the bridge.  
A 6mm hole is drilled into the base, that allows to screw the macro focusing rail on the base. 
A router has been used to thin the board around the hole and allow the screw to be housed inside.  

Depending if you use the bench for the Baby Shutter Tester or the Shutter Lover, you will have to flip the top rail (and/or the bottom rail) of the macro focusing rail in order to adapt to the measuring distance of the tool.

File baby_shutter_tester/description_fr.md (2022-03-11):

# Baby Shutter tester
Le baby Shutter Tester est un appareil destiné à mesurer la vitesse d’obturation des appareils photographiques argentiques.  

## Fabrication

drapeau Cet appareil a été conçu et fabriqué en France. Son assemblage est fait selon un processus artisanal.  Les composants électroniques sont soudés à la main. Le boitier est imprimé à l'unité sur une imprimante 3D.  
 La matière première de son boitier est biosourcée et produite en Europe.

Sa conception est issue du projet open source [Shutter Speed Tester (http://github.com/sebastienroy/shutter_speed_tester)](http://github.com/sebastienroy/shutter_speed_tester).  
Il en reprend les principes, mais le choix de ses composants et sa fabrication ont été optimisés pour permettre un format plus réduit.

## Description de l'appareil

Le Baby shutter tester est constitué d’un boitier principal et d'un capteur reliés par un fil.

### Le boitier principal comporte

- Un interrupteur on/off
- Un bouton de réinitialisation et de sélection de mode
- Un écran d'affichage
- Une LED d'éclairage (sur le côté droit)
- Un port micro USB (sur le côté gauche)
- Une trappe à pile LR6 (à l’arrière)

### Le capteur comporte

- Un support au format 35 mm
- Un capteur électronique (phototransistor)
- Un adaptateur moyen format 6x6 amovible 

L'appareil peut être alimenté électriquement soit par un câble micro USB, soit par deux piles LR6 (AA), non fournis.

## Utilisation

L'appareil permet de mesurer des vitesses d'obturation précises jusqu'au 20 000e de seconde.

- Ouvrez le boitier de votre appareil photo, et placez le capteur à l'arrière de l'appareil, à la place de la pellicule (utilisez si nécessaire l'adaptateur moyen format)
- placez le boitier du Baby Shutter Tester en face de l'appareil photo à la bonne hauteur pour que la LED d'éclairage soit positionnée en face du centre du capteur
- allumez l'appareil. La LED d'éclairage de l'appareil s'allume
- déclenchez. L'appareil indique le temps et la vitesse mesurés entre l'ouverture et la fermeture de l'obturateur.
- pour recommencer la mesure, appuyez sur le bouton en façade de l'appareil.

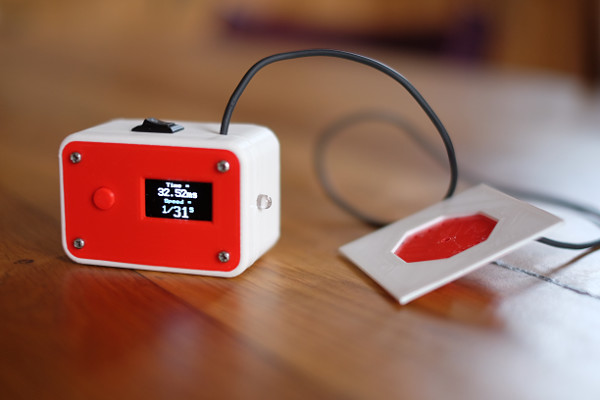
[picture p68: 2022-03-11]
baby_shutter_tester/images/BabyShutterTester.jpg

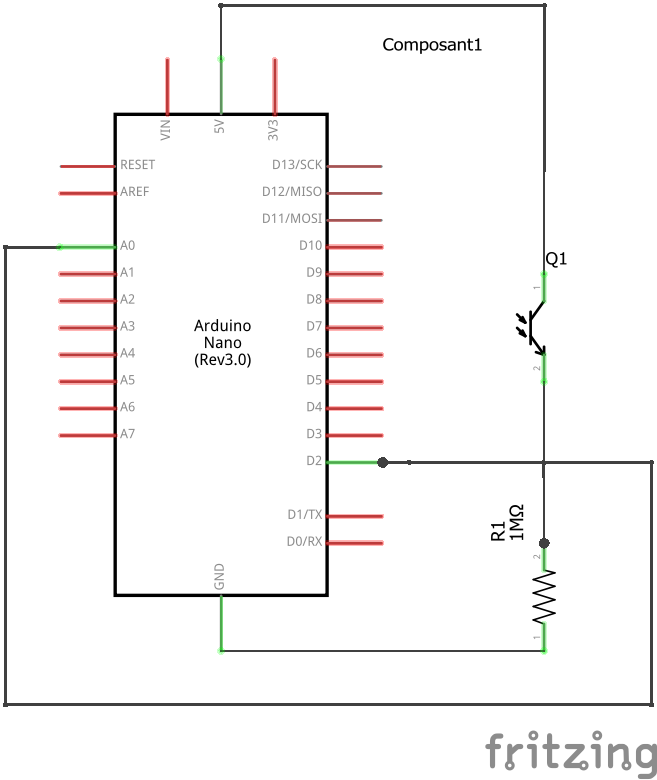
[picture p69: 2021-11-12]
Development/03_Development/01_Experimentation/experimentation/Experimentation_schéma.png

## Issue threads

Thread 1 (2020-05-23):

bibliography

sebastienroy, 2020-05-23:
An interesting project:
https://www.youtube.com/watch?v=UwOh3da_Y8s
https://github.com/cameradactyl/Shutter-Timer

sebastienroy, 2020-05-24:
How to use analog comparator trigger :
https://arduino.stackexchange.com/questions/23551/how-to-use-the-analog-comparator-to-determine-when-an-analog-pin-has-reached-a-c

sebastienroy, 2020-05-24:
L'article de reve, en francais:
https://zestedesavoir.com/articles/2106/arduino-les-secrets-de-lanalogique/

Closed 2022-08-29.

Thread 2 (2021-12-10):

Resistor footprint size

sebastienroy, 2021-12-10:
The resistor footprint chosen for the main board is too small, compared to the size of standard the 1/4 W resistors

Closed 2021-12-12.

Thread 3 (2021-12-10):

Transistor legs spacing

sebastienroy, 2021-12-10:
The space on the pcb between the legs of the transistor is too small. It is hard to solder them without making a contact between the legs

Closed 2021-12-12.

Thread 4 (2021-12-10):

Poles on the silk screen

sebastienroy, 2021-12-10:
The + and - poles of the 2 poles connectors are inverted on the silkscreen of the PCB.
Gnd is marked "+", and +VCC is marked "-"

Closed 2021-12-12.

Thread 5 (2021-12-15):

Use Raspberry Pico instead of Arduino

sebastienroy, 2021-12-15:
While Arduino nano is a not bad component choice, using a Raspberry Pico may be an even better one :
- Cheaper
- Made in Europe
- Faster
- Use micro usb instead of the old mini usb

It would be interresting to studdy such an alternative

sebastienroy, 2022-01-21:
Here is a nice kicad componant lib for pico:
https://github.com/ncarandini/KiCad-RP-Pico

sebastienroy, 2022-01-21:
For the SSD1306 OLED diplay, this one looks fine:
https://github.com/pforrmi/KiCad-SSD1306-128x64

sebastienroy, 2022-01-21:
And for the 3D model of the SSD1306
https://grabcad.com/library/display-oled-ssd1306-de-0-96-1

sebastienroy, 2022-03-13:
Ok

Closed 2022-03-13.

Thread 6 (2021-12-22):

No resistance to bouncing

sebastienroy, 2021-12-22:
The current algorithm is not resistant to bouncing.
The consequence is the result is not accurate (time very short) when ther is bouncing.
The expected behaviour would be that the first "open" event should be taken into account, and also the first "close" even.

Closed 2021-12-22.

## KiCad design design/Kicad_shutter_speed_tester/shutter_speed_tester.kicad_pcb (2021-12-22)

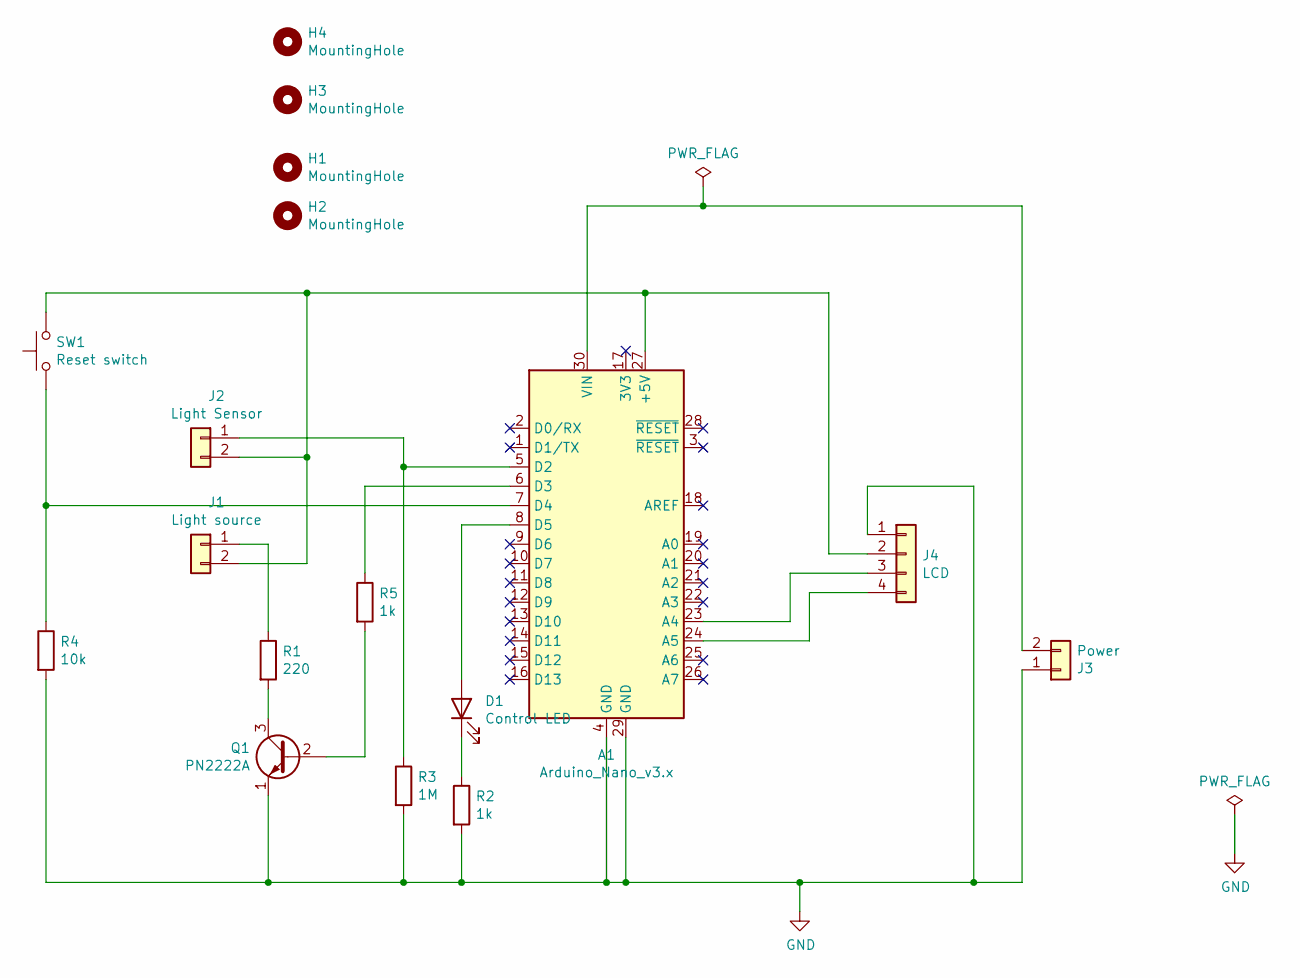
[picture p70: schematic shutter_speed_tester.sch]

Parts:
A1: Arduino_Nano_v3.x; Arduino_Nano
D1: Control LED; LED_D5.0mm
H1, H2, H3, H4: MountingHole; MountingHole_2.5mm
J1: Light source; Molex_KK-254_AE-6410-02A_1x02_P2.54mm_Vertical
J2: Light Sensor; Molex_KK-254_AE-6410-02A_1x02_P2.54mm_Vertical
J3: Power; Molex_KK-254_AE-6410-02A_1x02_P2.54mm_Vertical
J4: LCD; Molex_KK-254_AE-6410-04A_1x04_P2.54mm_Vertical
Q1: PN2222A; TO-92_Inline_Wide
R1: 220; R_Axial_DIN0207_L6.3mm_D2.5mm_P7.62mm_Horizontal
R2, R5: 1k; R_Axial_DIN0207_L6.3mm_D2.5mm_P7.62mm_Horizontal
R3: 1M; R_Axial_DIN0207_L6.3mm_D2.5mm_P7.62mm_Horizontal
R4: 10k; R_Axial_DIN0207_L6.3mm_D2.5mm_P7.62mm_Horizontal
SW1: Reset switch; SW_PUSH_6mm_H5mm

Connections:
GND: A1.4 (GND), A1.29 (GND), J3.1, J4.1, Q1.1 (E), R2.2, R3.2, R4.2
unnamed: A1.5 (D2), J2.1, R3.1
unnamed: A1.6 (D3), R5.1
unnamed: A1.7 (D4), R4.1, SW1.1
unnamed: A1.8 (D5), D1.2 (A)
unnamed: A1.23 (A4), J4.3
unnamed: A1.24 (A5), J4.4
unnamed: A1.27 (+5V), J1.2, J2.2, J4.2, SW1.2
unnamed: A1.30 (VIN), J3.2
unnamed: D1.1 (K), R2.1
unnamed: J1.1, R1.1
unnamed: Q1.2 (B), R5.2
unnamed: Q1.3 (C), R1.2

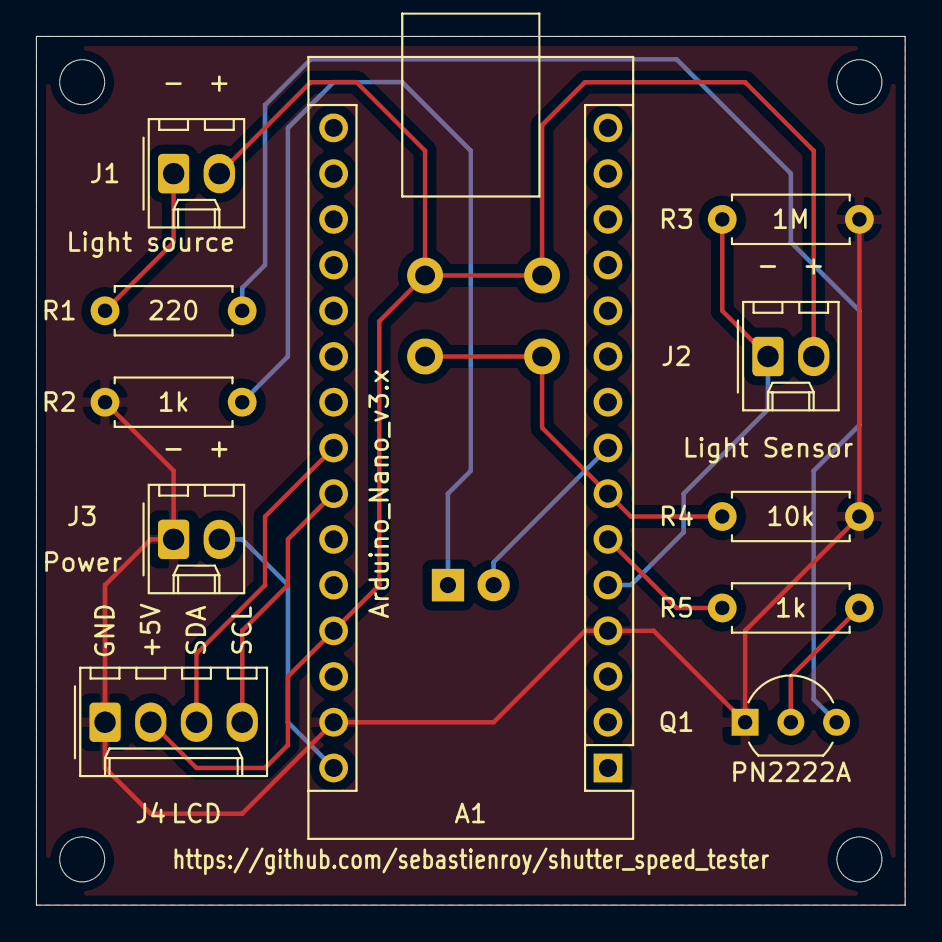
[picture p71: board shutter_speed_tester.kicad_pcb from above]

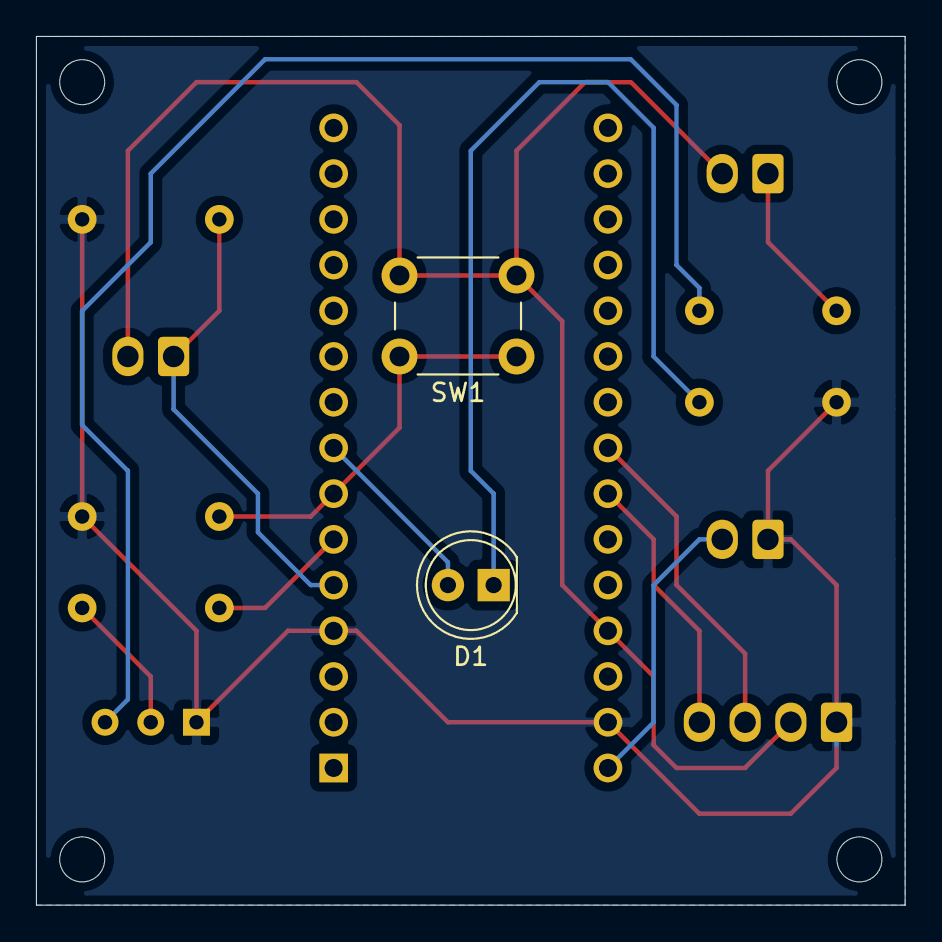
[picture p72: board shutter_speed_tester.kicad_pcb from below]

Board: 2 copper layers, 48.3 x 48.3 mm, 17 parts (2 on the bottom side), 13 nets.

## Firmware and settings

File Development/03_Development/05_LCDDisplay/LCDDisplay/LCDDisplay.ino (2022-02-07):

/*
 * Shutter Speed Tester
 * https://github.com/sebastienroy/shutter_speed_tester
 * Created by Sebastien ROY
 * 2021-2022
 * 
 * @license GPL-3.0+ <http://spdx.org/licenses/GPL-3.0+>
 * 
*/

#include <LiquidCrystal_I2C.h>
#include <util/atomic.h> // this library includes the ATOMIC_BLOCK macro.

//#define DEBUG
#define PERF_DEBUG

const char *version = "1.0.0";

const byte SENSOR_PIN = 2;
const byte ILLUMINATION_LED_PIN = 3;
const byte RESET_BUTTON_PIN = 4;
const byte CONTROL_LED_PIN = 5;

const byte ON = 1;
const byte OFF = 0;

// These variables are manipulated by the interrupt callback used to read the value
const byte NOTHING = 0;
const byte OPENING = 1;
const byte CLOSING = 2; 
volatile byte event_type = 0;
volatile bool measure_is_open = false;
volatile unsigned long  duration = 0;

const byte READY_STATE = 0;
const byte SHUTTER_OPEN_STATE = 1;
const byte DISPLAY_STATE = 2;
byte current_state = READY_STATE;

// control LED lev (over 255)
const int control_led_level = 255;

LiquidCrystal_I2C lcd(0x3f,16,2);  // set the LCD address to 0x3f for a 16 chars and 2 lines display
                                   // the I2C address value has to be determined using an I2C scanner

void setup() {
    Serial.begin(9600);
    pinMode(SENSOR_PIN, INPUT);
    pinMode(ILLUMINATION_LED_PIN, OUTPUT);
    pinMode(RESET_BUTTON_PIN, INPUT);
    pinMode(CONTROL_LED_PIN, OUTPUT);
    attachInterrupt(digitalPinToInterrupt(SENSOR_PIN), shutter_cb,  CHANGE);
    Serial.println("Shutter speed tester");
    Serial.print("Version ");
    Serial.println(version);

    // Init LCD
    lcd.init();                      // initialize the lcd 
    lcd.backlight();
    lcd.noCursor();
    lcdDisplayReady();
    
    // Light ON
    digitalWrite(ILLUMINATION_LED_PIN, ON);
    digitalWrite(CONTROL_LED_PIN, OFF);
    Serial.println("Ready to start measure");
    delay(200);
    event_type = NOTHING; // Clear the events induced by the light switch
    measure_is_open = true;
}

void loop() {
    if(current_state == READY_STATE) {
      if(event_type == OPENING || digitalRead(SENSOR_PIN) == ON) {
        // Entering the Shutter Open State
        // digitalWrite(CONTROL_LED_PIN, ON); // light on the control led
        analogWrite(CONTROL_LED_PIN, control_led_level);
        event_type = NOTHING; // Ok, taken into account
        current_state = SHUTTER_OPEN_STATE;
#if defined DEBUG        
        Serial.println("Entering SHUTTER OPEN State");
#endif // defined DEBUG        
      } else if(event_type == CLOSING) { // maybe to fast to first open
        event_type = NOTHING; // Ok, taken into account
        // Entering Display State
        enterDisplayState();
        current_state = DISPLAY_STATE;    
#if defined DEBUG        
        Serial.println("Entered closing while waiting");    
#endif // defined DEBUG        
      }
    } else if(current_state == SHUTTER_OPEN_STATE) {
      if(event_type == CLOSING) {
        event_type = NOTHING; // Ok, taken into account
        digitalWrite(CONTROL_LED_PIN, OFF); // switch off the control LED
        // Entering Display State
        enterDisplayState();
        current_state = DISPLAY_STATE;
      }
    } else if(current_state == DISPLAY_STATE) {
        byte reset_pin = digitalRead(RESET_BUTTON_PIN);
        if(reset_pin == 1) {
          // Entering Ready State
          // Light ON
          digitalWrite(ILLUMINATION_LED_PIN,ON);
          delay(200);
          event_type = NOTHING; // Clear the events induced by the light switch
          lcdDisplayReady();
          Serial.println("Ready to start measure");

          current_state = READY_STATE;
          measure_is_open = true;
        }  
        if (event_type == CLOSING) {
#if defined DEBUG        
           Serial.println("Closing while in display");
#endif // defined DEBUG        
        }
    }

    delay(10);
}

void lcdDisplayReady() {
  lcd.clear();
  lcd.setCursor(0,0);
  lcd.print("Ready to");
  lcd.setCursor(2,1);
  lcd.print("start measure");
}

void lcdDisplayMeasure(long microsDuration) {
  float time_mili = microsDuration / 1000.0;
  float speed_val = 1000.0 / time_mili;
  lcd.clear();
  lcd.setCursor(0,0);
  lcd.print("time=");
  lcd.print(String(time_mili));
  lcd.print("ms");
  lcd.setCursor(0,1);
  lcd.print("speed=1/");
  lcd.print(String(speed_val));
}

void enterDisplayState() {
    // Display result
    lcdDisplayMeasure(duration);
    
    float time_mili = duration / 1000.0;
    float speed_val = 1000.0 / time_mili;
    Serial.print("Opening duration (ms) : ");
    Serial.print(time_mili);
    Serial.print(" Speed : 1/");
    Serial.print(speed_val);
    Serial.println();
    // Switch off the illumination led
    digitalWrite(ILLUMINATION_LED_PIN, OFF);
  
}

/*
 * Callback to measure the time where the shutter is open
 * The tricky thing is to prevent bouncing
 */
void shutter_cb() {
  static byte previous_state = OFF;
  static  unsigned long begin_time = 0;
  static unsigned long end_time = 0;
 if( measure_is_open) {
  #if defined PERF_DEBUG
  unsigned long t1 = micros();
  #endif
    
    ATOMIC_BLOCK(ATOMIC_RESTORESTATE) {
      byte current_state = digitalRead(SENSOR_PIN);
      if(current_state != previous_state) {
        if((current_state == ON) && (begin_time == 0) ) { // alow start measure only once
          begin_time = micros();        
          event_type = OPENING;
    #if defined DEBUG        
        Serial.print("Open - ");
        Serial.println(measure_is_open);
    #endif // defined DEBUG        
        } else if((current_state == OFF) && (begin_time !=0) ){ // current_state==OFF but prevent close before open
          end_time = micros();  
          duration = end_time - begin_time;
          // reset measurement
          begin_time = end_time = 0;       
          event_type = CLOSING;
    #if defined DEBUG        
        Serial.print("Close - ");
        Serial.println(measure_is_open);
    #endif // defined DEBUG        
          measure_is_open = false;
        }
        previous_state = current_state;
        
      }
    } // ATOMIC_BLOC
    #if defined PERF_DEBUG
  unsigned long t2 = micros();
  Serial.print("callback duration (micros) : ");
  Serial.println(t2-t1);
  #endif
  } // measure_is_open

}

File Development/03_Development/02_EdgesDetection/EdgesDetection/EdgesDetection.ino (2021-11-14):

const byte SENSOR_PIN = 2;

const byte NOTHING = 0;
const byte OPENING = 1;
const byte CLOSING = 2; 
byte event_type = 0;

unsigned long begin_time = 0;
unsigned long end_time = 0;

void setup() {
    Serial.begin(9600);
    pinMode(SENSOR_PIN, INPUT);
    attachInterrupt(digitalPinToInterrupt(SENSOR_PIN), shutter_cb,  CHANGE);
    Serial.println("Hello world");
}

void loop() {
    delay(100);

    if(event_type == CLOSING) {
      unsigned long duration = end_time - begin_time;
      float time_mili = duration / 1000.0;
      float speed_val = 1000.0 / time_mili;
      Serial.print("Opening duration (ms) : ");
      Serial.print(time_mili);
      Serial.print(" Speed : 1/");
      Serial.print(speed_val);
      Serial.println();
      
      event_type = NOTHING;
     }

}

void shutter_cb() {
  unsigned long current_time = micros();
  event_type = ( digitalRead(SENSOR_PIN) == 0 )? CLOSING : OPENING;
  if(event_type == OPENING) {
    begin_time = current_time;
  } else {
    end_time = current_time;
  }
}

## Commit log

2021-11-07 Work in progress
    [shutterSpeedTester.fzz]
2021-11-08 Story 1 in progress
    [EdgesDetection.fzz]
2021-11-12 Step 0 work in progress
    [Experimentation.fzz]
2021-11-12 Step 0 finished
    [Experimentation.fzz]
2021-11-12 Step 1 looks fine
    [EdgesDetection.fzz]
2021-11-13 Add state diagram step
    [BehaviourStates.fzz, EdgesDetection.fzz]
2021-11-13 Add step 3 : control LED
    [ControlLED.fzz, LCDDisplay.fzz]
2021-11-14 Add lcd display
    [LCDDisplay.fzz]
2021-11-14 Few improvemets
    [LCDDisplay.fzz]
2021-11-28 Add kicad files
    [shutter_speed_tester.csv, shutter_speed_tester.kicad_pcb, shutter_speed_tester.sch]
2021-11-28 adding routing
    [shutter_speed_tester.kicad_pcb, shutter_speed_tester.sch]
2021-11-29 pcb design described
    [shutter_speed_tester.kicad_pcb]
2021-12-01 reorganize pcb with USB port on top
    [shutter_speed_tester.kicad_pcb, shutter_speed_tester.sch]
2021-12-01 move components
    [shutter_speed_tester.kicad_pcb]
2021-12-07 update board
    [shutter_speed_tester.kicad_pcb]
2021-12-12 Changes on PCB, fixes #2, fixes #3, fixes #4
    [shutter_speed_tester.kicad_pcb, shutter_speed_tester.sch]
2021-12-13 Add screws in part list
2021-12-16 export pcb 3d view
    [shutter_speed_tester.step]
2021-12-20 Set control LED size to 5mm
    [shutter_speed_tester.sch, shutter_speed_tester.step]
2021-12-20 Add i2c scanner
2021-12-20 Step 7 : Casing fron panel
    [CasingForShutterSpeedTester.FCStd, shutter_speed_tester.step]
2021-12-22 Fixes #6 : bouncing management
    [LCDDisplay.ino]
2021-12-26 work on casing
    [LightSourceHousingTest.FCStd]
2021-12-27 work in progress. reduce by depth and add 9V battery
    [9V battery v3.step, LightSourceHousingTest.FCStd]
2022-01-02 changes on lightSource housing
    [LightSourceHousingTest.FCStd]
2022-01-03 increase tollerance around light source LED
    [LightSourceHousingTest.FCStd]
2022-01-04 begin design of battery door
    [BatteryDoor.FCStd]
2022-01-04 Battery door is complete
    [BatteryDoor.FCStd]
2022-01-04 reduce battery cage
    [BatteryDoor.FCStd]
2022-01-04 work on battery door
    [BatteryDoor.FCStd]
2022-01-05 Changes on door
    [BatteryDoor.FCStd]
2022-01-05 adjust door
    [BatteryDoor.FCStd]
2022-01-05 started work on rear panel
    [BatteryDoor.FCStd]
2022-01-06 Create Light Sensor Casing
    [LightSensorCasing.FCStd]
2022-01-06 Beginning of step 10
    [WireBlocking.FCStd]
2022-01-12 update sensorcasing
    [LightSensorCasing.FCStd]
2022-01-12 Work still in progress
    [LightSensorCasing.FCStd]
2022-01-13 Add conclusion on battery door design
2022-01-14 6x6 adpter
    [LightSensorCasing.FCStd]
2022-01-18 Add auto update LCD I2C address
2022-01-18 add casing parts
    [CasingForShutterSpeedTester-BatteryCageBack.stl, CasingForShutterSpeedTester-Calle LED.stl, CasingForShutterSpeedTester-CaseBody.stl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]
2022-01-19 add USB access hole in the case body
    [CasingForShutterSpeedTester-CaseBody.stl]
2022-01-20 add datasheets and driver
2022-01-25 Add PLA filament in part list
2022-01-27 precision on the switch connection
2022-01-27 add light sensor casing stories
2022-01-29 increase tolerence between button and panel
2022-01-29 sorting parts by color
    [CasingForShutterSpeedTester-BatteryCageBack.stl, CasingForShutterSpeedTester-Calle_LED.stl, CasingForShutterSpeedTester-CaseBody.stl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]
2022-01-29 add credits
    [LightSensorCasing.FCStd]
2022-01-31 Remove unused jack audio connector
2022-02-07 Add indication on the LiquidCrystal I2C library
2025-06-15 Added FreeCAD assembly screenshot
    Added FreeCAD assembly screenshot to signal its open-soruce nature and modifyability.
